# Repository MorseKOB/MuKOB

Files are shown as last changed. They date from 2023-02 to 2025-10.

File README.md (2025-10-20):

# MuKOB (μKOB) - Micro-controller based MorseKOB Client Device

Raspberry Pi Pico W (RP2040 CPU) based device with a built-in display and
a terminal interface. Uses built-in wifi to connect to the MorseKOB Server.

It interfaces to a KOB, Key + Sounder, Key + Tone, Paddle + Tone, etc. to provide Morse
input and output. The device can operate completely stand-alone (using the
display-touchscreen) or it can connect to a VT-220 terminal (or emulator like Putty)
to provide a larger interface and allow keyboard input.

It supports both American (railroad) and International code with sounder or tone
output, and allows use of Farnsworth word/character timing to promote improving
copying speed.

This repo also includes the **MuKOB Interface** which can be used with **MKOB** and **MorseKOB** through a USB to a PC.

# References
* [MorseKOB Main Project](https://github.com/MorseKOB)
* [PyKOB - The full/computer MKOB Client Application, utilities and Python libraries](https://github.com/MorseKOB/PyKOB)
* [Raspberry Pi Pico W](https://www.raspberrypi.com/documentation/microcontrollers/raspberry-pi-pico.html)
* [FatFs - Generic FAT Filesystem Module](http://elm-chan.org/fsw/ff/00index_e.html)
* [no-OS-FatFS-SD-SPI-RPi-Pico](https://github.com/carlk3/no-OS-FatFS-SD-SPI-RPi-Pico)

# Acknowledgements
The first, and probably most significant acknowledgement has to go to the architects, developers, technical writers, and other staff members responsible for the **Raspberry Pi Pico** and **Pico W**, the **Raspberry Pi Pico C/C++ SDK**, and the **Raspberry Pi Pico C/C++ Samples**.

This application implements a 'C' version of the American Morse encoding and decoding algorithms developed by *Les Kerr*.

The FAT file system and SD card libraries, with some small modifications (to configure for the MuKOB board and remove some printing), are from *ChaN* and *Carl Kugler* respectively.

As with every significant C project I've undertaken since the early '80s, my 'go-to' reference is **The C Programming Language** by *Brian Kernighan* and *Dennis Ritchie* (Prentice Hall, 1978 & 1988).

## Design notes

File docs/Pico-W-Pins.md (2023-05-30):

# Pico-W Pins used for the μKOB device

The μKOB device uses most of the Pico-W's GPIO/PIO pins. Because both hardware
SPI's are used, as well as two pins for PIO (for the rotary encoder), the pins
assigned can't be changed too much. The definitions for the pins used are in
the 'system_defs.h' file.

As defined, the pin assignments are
 (Pins within single-quotes are fixed use. NU=Not Used):
| | Use | PIN  |  |  PIN | Use |
|-|---|---|--|---|---|
| | TTY-TX | 1  |  |  40  | 'VBUS' |
| | TTY-RX | 2  |  |  39  | 'VSYS' |
| | 'GND' | 3  |  |  38  | 'GND' |
| | SD+Touch SPI0-SCK | 4  |  |  37  | '3V3_EN' |
| |  SD+Touch SPI0-TX | 5  |  |  36  | '3V3 OUT' |
| |  SD+Touch SPI0-RX | 6  |  |  35  | 'ADC_VREF' |
| | SD Select | 7  |  |  34  | GP-28 (NU) |
| | 'GND' | 8  |  |  33  | 'GND/AGND' |
| | Touch Select | 9  |  |  32  | Display Backlight |
| | Touch IRQ |  10  |  |  31  | Display Reset |
| | Display CMD-/Data |  11  |  |  30  | 'RUN' |
| | Display Select |  12  |  |  29  | Speaker |
| | 'GND' |  13  |  |  28  | 'GND' |
| |  Display SPI1-SCK |  14  |  |  27  | Options SW - 4 |
| | Display SPI1-TX |  15  |  |  26  | Options SW - 3 |
| | Display SPI1-RX |  16  |  |  25  | Options SW - 2 |
| | Rotary Push-SW |  17  |  |  24  | Options SW - 1 |
| | 'GND' |  18  |  |  23  | 'GND' |
| | Rotary Phase-A |  19  |  |  22  | Morse Key |
| | Rotary Phase-B |  20  |  |  21  | Morse Sounder |
|_|___________________|______|__|______|___________________|
Notes:
 SPI0 and SPI1 use the hardware SPI's. Therefore, they have limited pins.
 The Rotary A:B use PIO. They must be 2 sequential GP pins for 'A' then 'B'.
 The 'Options SW' is to select 'hard' options used before the SD is
  initialized. They were selected as 4 GPIO's in a row to make it easy to
  breadboard (also picked these since I2C is not being used).

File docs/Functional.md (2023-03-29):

# Cooperative Multitasking
μKOB uses *cooperative multitasking* on each of the RP2040 cores.

@see https://en.wikipedia.org/wiki/Cooperative_multitasking for more information on this style.

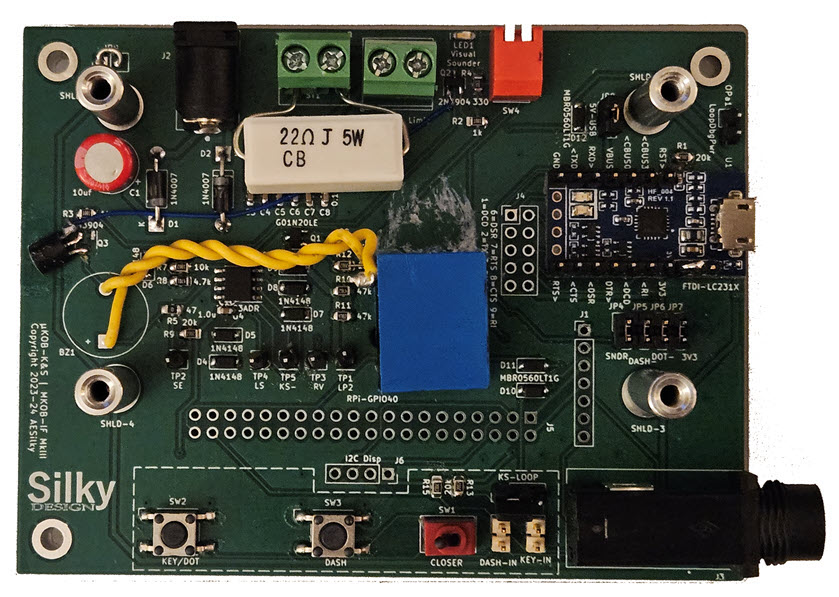
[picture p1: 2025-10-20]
docs/images/KSIF-MkIII-top-na.jpg

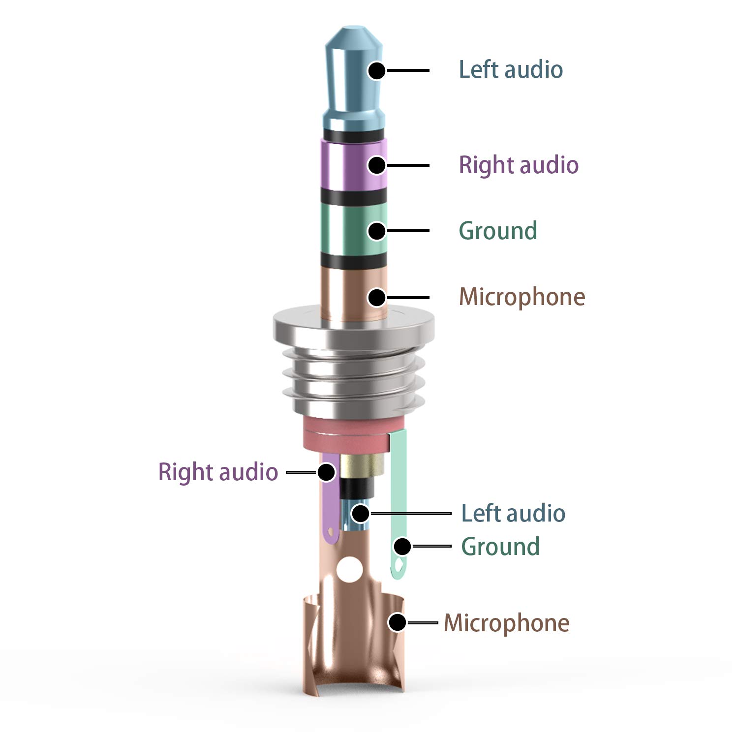
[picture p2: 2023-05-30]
docs/TRRS-Conn-Pins.jpg

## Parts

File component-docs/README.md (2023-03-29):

# COMPONENT DOCUMENTATION
This folder contains documents for the components used in the μKOB system.

These are copies from the manufacturers of the components and are the 
property/copyright of those manufacturers.

They are included here for convenience.

Some of the components may or may not be used in the current version, 
but were, or were expected to be, used in some version.

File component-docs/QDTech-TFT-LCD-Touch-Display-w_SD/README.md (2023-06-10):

# TFT-LCD Display Modules w/Touch and SD Card

There are a number of commonly found, different sized, SPI display modules
with a red PCB, ILITECH display controller, ADS7843/XPT2046 touch screen
controller, and a full-sized SD card slot, sold under different brand names
(HiLetgo, Adafruit, Hosyond, etc.). Regardless of the distributor selling it,
they are all designed and manufactured by:
Shenzhen Junxian Electronic Technology Co., Ltd
[QDTech China](https://szjunxian.en.alibaba.com/)

The specific ILITECH display controller the module uses depends on the
resolution and screen size of the TFT-LCD panel.

Resolution - Size = Controller:

* 240x320 - 2.8" = ILI9341
* 240x320 - 3.2" = ILI9341
* 320x480 - 3.5" = ILI9844
* 320x480 - 4.0" = ILI9486

Touch Screen Controller: TI (Burr-Brown) ADS7843 / SHENZHEN XPTEK XPT2046

SD Card: Full size card socket using 4-wire SPI interface mode.

Module Power (internal): 3.3V. From connector `VCC` or TOREX XC6206 Precicion Voltage Regulator with `VCC` as the source.

## SPI Interface

The SPI connections are seperate for the three functional areas with a common
power connection. The power, display, and touch connections are via one 14
pin connector (1x14 pin). The SD card connection is through a separate
(1x4 pin) connector.

The modules are available without the touch screen (generally, with a 1 digit
difference in model number).

## Power

There is a jumper (SMD resistor location), `J1` on the PCB that is shipped open
(not populated). Shorting it (populating with a 0 ohm resistor) bypasses the
TOREX XC6206 3.3v regulator that is sourced from the `VCC` pin on the 14 pin
connector.

`J1` **MUST** be open if the module is powered from 5v. It can be closed (wired or 0 ohm resistor/shunt populated) if powering the module from 3.3v to avoid the small (~250mV)
drop introduced by the regulator.

Note that **all logic signals are 3.3v**.

## Touch Screen Controller

The `Vref` of the ADS7843/XPT2046 touch screen controller is tied to (the internal)
`VCC3.3`. The `VCC3.3` is either the output from the on-module 3.3v regulator or the
`VCC` input of the module, depending on the state of `J1` (See: [Power](#markdown-header-power)).

If `J1` is left open, the locally generated `VCC3.3` is likely to be more stable than the
voltage of `VCC` provided by the connector. However, the (possibly) lower value of
Vref must be accounted for when reading ADC values.

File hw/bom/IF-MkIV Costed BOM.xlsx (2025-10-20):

Item | References | Value | Footprint | Quantity Total | Cost Each | Base | Base Cost | Key Jack 1/4 | K14 Cost | Sndr/Loop Power | SLPS Cost | LED+Mini Sounder | L/MS Cost
1 | C2, C3, C4, C5, C6, C7, C8, C11 | 0.1u | C_0603_1608Metric_Pad1.08x0.95mm_HandSolder | 8 | $0.02 | 8 | $0.16 |  | $0.00 |  | $0.00 |  | $0.00
2 | C9, C10 | 1.0u | C_0603_1608Metric_Pad1.08x0.95mm_HandSolder | 2 | $0.02 | 2 | $0.04 |  | $0.00 |  | $0.00 |  | $0.00
3 | C1 | 10uf | CP_Radial_D8.0mm_P5.00mm | 1 | $1.40 | 1 | $1.40 |  | $0.00 |  | $0.00 |  | $0.00
4 | C12 | 10uf Tant | CP_EIA-3528-12_Kemet-T_Pad1.50x2.35mm_HandSolder | 1 | $0.13 | 0 | $0.00 |  | $0.00 | 0 | $0.00 | 1 | $0.13
5 | R1, R9, R12, R13, R15 | 20k | R_0805_2012Metric_Pad1.20x1.40mm_HandSolder | 5 | $0.02 | 5 | $0.10 |  | $0.00 |  | $0.00 |  | $0.00
6 | R6, R7 | 10k | R_0805_2012Metric_Pad1.20x1.40mm_HandSolder | 2 | $0.02 | 2 | $0.04 |  | $0.00 |  | $0.00 |  | $0.00
7 | R8, R14 | 4.7k | R_0805_2012Metric_Pad1.20x1.40mm_HandSolder | 2 | $0.02 | 2 | $0.04 |  | $0.00 |  | $0.00 |  | $0.00
8 | R10, R11 | 47k | R_0805_2012Metric_Pad1.20x1.40mm_HandSolder | 2 | $0.02 | 2 | $0.04 |  | $0.00 |  | $0.00 |  | $0.00
9 | R2 | 1k | R_0805_2012Metric_Pad1.20x1.40mm_HandSolder | 1 | $0.02 | 0 | $0.00 |  | $0.00 | 0 | $0.00 | 1 | $0.02
10 | R4 | 330 | R_0805_2012Metric_Pad1.20x1.40mm_HandSolder | 1 | $0.02 | 0 | $0.00 |  | $0.00 | 0 | $0.00 | 1 | $0.02
11 | R5 | 0|16 | R_0805_2012Metric_Pad1.20x1.40mm_HandSolder | 1 | $0.02 | 0 | $0.00 |  | $0.00 | 0 | $0.00 | 1 | $0.02
12 | D4, D5, D6, D7, D8 | 1N4148 | D_SOD-123 | 5 | $0.05 | 5 | $0.25 |  | $0.00 |  | $0.00 |  | $0.00
13 | D2, D10, D11, D12 | MBR0560LT1G | D_SOD-123 | 4 | $0.12 | 3 | $0.36 |  | $0.00 |  | $0.00 | 1 | $0.12
14 | D1 | HDS20M | TO-269AA | 1 | $0.30 | 0 | $0.00 |  | $0.00 | 1 | $0.30 |  | $0.00
15 | D3 | 1N4007 | D_SOD-123 | 1 | $0.08 | 1 | $0.08 |  | $0.00 |  | $0.00 |  | $0.00
16 | D9 | MBR180S1 (Sndr Drv) | D_SOD-123 | 1 | $0.12 | 1 | $0.12 |  | $0.00 |  | $0.00 |  | $0.00
17 | U1 | FTDI-LC231X | AES-FTDI_LC231X | 1 | $9.75 | 1 | $9.75 |  | $0.00 |  | $0.00 |  | $0.00
18 | U4 | LM393ADR | SOIC-8_3.9x4.9mm_P1.27mm | 1 | $0.40 | 1 | $0.40 |  | $0.00 |  | $0.00 |  | $0.00
19 | SW1 | CLOSER | AES-SW-TGL-Micro-DPST-CIT | 1 | $2.60 | 0 | $0.00 |  | $0.00 |  | $0.00 |  | $0.00
20 | SW2 | KEY/DOT | AES-SW_PUSH_SMD_1P1T_NO_6x6mm | 1 | $0.55 | 0 | $0.00 |  | $0.00 |  | $0.00 |  | $0.00
21 | SW3 | DASH | AES-SW_PUSH_SMD_1P1T_NO_6x6mm | 1 | $0.55 | 0 | $0.00 |  | $0.00 |  | $0.00 |  | $0.00
22 | SW4 | SW_DIP_x02 | DIP-4_W7.62mm_Socket | 1 | $1.50 | 0 | $0.00 |  | $0.00 |  | $0.00 | 1 | $1.50
23 | JP8, JP10 | 5V-USB | PinHeader_1x02_P2.54mm_Vertical | 2 | $0.01 | 2 | $0.02 |  | $0.00 |  | $0.00 |  | $0.00
24 | JP1 | KeyJack-NP | PinHeader_1x02_P2.54mm_Vertical | 1 | $0.01 | 1 | $0.01 |  | $0.00 |  | $0.00 |  | $0.00
25 | JP2 | KEY-IN | PinHeader_1x02_P2.54mm_Vertical | 1 | $0.01 | 1 | $0.01 |  | $0.00 |  | $0.00 |  | $0.00
26 | JP3 | DASH-IN | PinHeader_1x02_P2.54mm_Vertical | 1 | $0.01 | 1 | $0.01 |  | $0.00 |  | $0.00 |  | $0.00
27 | JP4 | SNDR | PinHeader_1x02_P2.54mm_Vertical | 1 | $0.01 | 1 | $0.01 |  | $0.00 |  | $0.00 |  | $0.00
28 | JP5 | DASH- | PinHeader_1x02_P2.54mm_Vertical | 1 | $0.01 | 1 | $0.01 |  | $0.00 |  | $0.00 |  | $0.00
29 | JP6 | DOT- | PinHeader_1x02_P2.54mm_Vertical | 1 | $0.01 | 1 | $0.01 |  | $0.00 |  | $0.00 |  | $0.00
30 | JP7 | 3V3 | PinHeader_1x02_P2.54mm_Vertical | 1 | $0.01 | 1 | $0.01 |  | $0.00 |  | $0.00 |  | $0.00
31 | JP9 | Shield_GND | PinHeader_1x02_P2.54mm_Vertical | 1 | $0.01 | 1 | $0.01 |  | $0.00 |  | $0.00 |  | $0.00
32 | LED1 | VIS_SNDR | AES-LED_SMD_SIDEVIEW_Harvatek | 1 | $0.10 | 0 | $0.00 |  | $0.00 |  | $0.00 | 1 | $0.10
33 | OP1 | KS-LOOP | PinHeader_1x03_P2.54mm_Vertical | 1 | $0.02 | 0 | $0.00 |  | $0.00 |  | $0.00 | 1 | $0.02
34 | OPa1 | LoopDbgPwr | PinHeader_1x02_P2.54mm_Vertical | 1 | $0.01 | 1 | $0.01 |  | $0.00 |  | $0.00 |  | $0.00
35 | Q1 | G01N20LE (Sndr Drv) | SOT-23 | 1 | $0.35 | 1 | $0.35 |  | $0.00 |  | $0.00 |  | $0.00
36 | Q2 | MMBT3904 | SOT-23 | 1 | $0.04 | 0 | $0.00 |  | $0.00 |  | $0.00 | 1 | $0.04
37 | RLY1 | RELAY-5v|3v-DPST | Relay_SPDT_Finder_36.11 | 1 | $2.00 | 0 | $0.00 |  | $0.00 |  | $0.00 | 1 | $2.00
38 | ST1 | LOOP_CUR_LIMIT | TerminalBlock_Philmore_TB132_1x02_P5.00mm_Horizontal | 1 | $0.35 | 1 | $0.35 |  | $0.00 |  | $0.00 |  | $0.00
39 | ST2 | SNDR/KOB | TerminalBlock_Philmore_TB132_1x02_P5.00mm_Horizontal | 1 | $0.35 | 1 | $0.35 |  | $0.00 |  | $0.00 |  | $0.00
40 | TP1 | LP2 | PinHeader_1x01_P2.54mm_Vertical | 1 | $0.00 | 0 | $0.00 |  | $0.00 |  | $0.00 |  | $0.00
41 | TP2 | SE | PinHeader_1x01_P2.54mm_Vertical | 1 | $0.00 | 0 | $0.00 |  | $0.00 |  | $0.00 |  | $0.00
42 | TP3 | RV | PinHeader_1x01_P2.54mm_Vertical | 1 | $0.00 | 0 | $0.00 |  | $0.00 |  | $0.00 |  | $0.00
43 | TP4 | LS | PinHeader_1x01_P2.54mm_Vertical | 1 | $0.00 | 0 | $0.00 |  | $0.00 |  | $0.00 |  | $0.00
44 | TP5 | KS- | PinHeader_1x01_P2.54mm_Vertical | 1 | $0.00 | 0 | $0.00 |  | $0.00 |  | $0.00 |  | $0.00
45 | TP6 | SE- | PinHeader_1x01_P2.54mm_Vertical | 1 | $0.00 | 0 | $0.00 |  | $0.00 |  | $0.00 |  | $0.00
46 | J1 | MuKOB IF | PinHeader_1x07_P2.54mm_Vertical | 1 | $0.05 | 0 | $0.00 |  | $0.00 |  | $0.00 |  | $0.00
47 | J2 | LOOP PWR | AES-CUI_PJ-037B | 1 | $0.70 | 0 | $0.00 |  | $0.00 | 1 | $0.70 |  | $0.00
48 | J3 | KEY-PADDLE | AES-CUI_SJ-63063B-audio-jack | 1 | $1.80 | 0 | $0.00 | 1 | $1.80 |  | $0.00 |  | $0.00
49 | J4 | COMM-DCE-10 | PinHeader_2x05_DB9-Order | 1 | $0.10 | 0 | $0.00 |  | $0.00 |  | $0.00 |  | $0.00
50 | J5 | RPi-GPIO40 | PinSocket_2x20_P2.54mm_Vertical | 1 | $0.80 | 0 | $0.00 |  | $0.00 |  | $0.00 |  | $0.00
51 | J6 | I2C Disp | PinSocket_1x04_P2.54mm_Vertical | 1 | $0.05 | 0 | $0.00 |  | $0.00 |  | $0.00 |  | $0.00
52 | J7 | KEY-PADDLE-1_8 | CUI_SJ1-3534NG-audio-jack | 1 | $1.50 | 0 | $0.00 |  | $0.00 |  | $0.00 |  | $0.00
53 | PCB | MuKOB IF MkIV | PCBWay | 1 | $6.50 | 1 | $6.50 |  | $0.00 |  | $0.00 |  | $0.00
54 | Base | Acrylic | Send-Cut-Send Laser Cut | 1 | $2.00 | 1 | $2.00 |  | $0.00 |  | $0.00 |  | $0.00
55 | Shield | Altoids Tin | (Modifications) | 1 | $2.00 | 1 | $2.00 |  | $0.00 |  | $0.00 |  | $0.00
56 | Screws & Spacers |  | 8 Screws, 4 Alum Spacers, 4 Nylon Spacers (kit) | 1 | $3.00 | 1 | $3.00 |  | $0.00 |  | $0.00 |  | $0.00
 |  |  | Totals | 79 |  | 52 | $27.44 | 1 | $1.80 | 2 | $1.00 | 10 | $3.97
 |  | 'Full' >>> | Base + 1/4" Key Jack + Sndr Pwr + L/MS + Test Key |  | $37.71 |  | $27.24 |  | $1.80 |  | $1.00 |  | $3.97
 |  | 'KOB' >>> | Base + Sndr Pwr |  | $28.24 |  | $27.24 |  |  |  | $1.00

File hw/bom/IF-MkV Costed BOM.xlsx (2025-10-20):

Item | References | Value | Footprint | Quantity Total | Cost Each | Base | Base Cost | Key Jack 1/8 | K18 Cost | Sndr/Loop Power | SLPS Cost | LED (Vis) Sounder | L(VS) Cost | RPi Conn | RPC Cost | Debug Only | (qty check)
1 | C3, C6, C7, C8, C9, C11, C12, C13, C14 | 0.1u | C_0603_1608Metric_Pad1.08x0.95mm_HandSolder | 9 | $0.02 | 8 | $0.16 |  | $0.00 | 1 | $0.02 |  | $0.00 | -1 | -$0.02 |  | 9
2 | C5, C10 | 1.0u | C_0603_1608Metric_Pad1.08x0.95mm_HandSolder | 2 | $0.02 | 2 | $0.04 |  | $0.00 |  | $0.00 |  | $0.00 |  | $0.00 |  | 2
3 | C1 | 10u | C_0603_1608Metric_Pad1.08x0.95mm_HandSolder | 1 | $0.02 | 1 | $0.02 |  | $0.00 |  | $0.00 |  | $0.00 | -1 | -$0.02 |  | 1
4 | C2 | 47u | C_0603_1608Metric_Pad1.08x0.95mm_HandSolder | 1 | $0.05 | 1 | $0.05 |  | $0.00 |  | $0.00 |  | $0.00 | -1 | -$0.05 |  | 1
5 | C4 | 10uf | CP_Radial_D8.0mm_P5.00mm | 1 | $1.50 | 0 | $0.00 |  | $0.00 | 1 | $1.50 |  | $0.00 |  | $0.00 |  | 1
6 | R7, R8, R12, R13 | 20k | R_0805_2012Metric_Pad1.20x1.40mm_HandSolder | 4 | $0.03 | 4 | $0.12 |  | $0.00 |  | $0.00 |  | $0.00 |  | $0.00 |  | 4
7 | R3, R4 | 470 | R_0805_2012Metric_Pad1.20x1.40mm_HandSolder | 1 | $0.03 | 0 | $0.00 |  | $0.00 |  | $0.00 | 1 | $0.03 |  | $0.00 |  | 1
8 | R5, R6 | 27 | R_0805_2012Metric_Pad1.20x1.40mm_HandSolder | 2 | $0.03 | 2 | $0.06 |  | $0.00 |  | $0.00 |  | $0.00 | -2 | -$0.06 |  | 2
9 | R9, R10 | 10k | R_0805_2012Metric_Pad1.20x1.40mm_HandSolder | 2 | $0.03 | 2 | $0.06 |  | $0.00 |  | $0.00 |  | $0.00 |  | $0.00 |  | 2
10 | R11, R16 | 4.7k | R_0805_2012Metric_Pad1.20x1.40mm_HandSolder | 2 | $0.03 | 2 | $0.06 |  | $0.00 |  | $0.00 |  | $0.00 |  | $0.00 |  | 2
11 | R14, R15 | 47k | R_0805_2012Metric_Pad1.20x1.40mm_HandSolder | 2 | $0.03 | 2 | $0.06 |  | $0.00 |  | $0.00 |  | $0.00 |  | $0.00 |  | 2
12 | R1 | 1k | R_0805_2012Metric_Pad1.20x1.40mm_HandSolder | 1 | $0.03 | 0 | $0.00 |  | $0.00 |  | $0.00 | 1 | $0.03 |  | $0.00 |  | 1
13 | R2 | 0-S | R_0805_2012Metric_Pad1.20x1.40mm_HandSolder | 1 | $0.03 | 1 | $0.03 |  | $0.00 |  | $0.00 |  | $0.00 | -1 | -$0.03 |  | 1
14 | L1 | 600RJ0.5A | L_0805_2012Metric_Pad1.15x1.40mm_HandSolder | 1 | $0.15 | 1 | $0.15 |  | $0.00 |  | $0.00 |  | $0.00 |  | $0.00 |  | 1
15 | D4, D5, D6, D7, D8 | 1N4148 | D_SOD-123 | 5 | $0.05 | 5 | $0.25 |  | $0.00 |  | $0.00 |  | $0.00 |  | $0.00 |  | 5
16 | D1, D2, D3 | MBR0560LT1G | D_SOD-123 | 3 | $0.15 | 3 | $0.45 |  | $0.00 |  | $0.00 |  | $0.00 |  | $0.00 |  | 3
17 | D9 | MBR180S1 | D_SOD-123 | 1 | $0.15 | 1 | $0.15 |  | $0.00 |  | $0.00 |  | $0.00 |  | $0.00 |  | 1
18 | D10 | 1N4007 | D_SOD-123 | 1 | $0.08 | 1 | $0.08 |  | $0.00 |  | $0.00 |  | $0.00 |  | $0.00 |  | 1
19 | U1 | LM393ADR | SOIC-8_3.9x4.9mm_P1.27mm | 1 | $0.50 | 1 | $0.50 |  | $0.00 |  | $0.00 |  | $0.00 |  | $0.00 |  | 1
20 | U2 | FT231XQ | QFN-20-1EP_4x4mm_P0.5mm_EP2.5x2.5mm | 1 | $3.50 | 1 | $3.50 |  | $0.00 |  | $0.00 |  | $0.00 | -1 | -$3.50 |  | 1
21 | BR1 | HDS20M | AES-BridgeRect-HDS20M-13-1KV-2A | 1 | $0.30 | 0 | $0.00 |  | $0.00 | 1 | $0.30 |  | $0.00 |  | $0.00 |  | 1
22 | JP4 | KeyJack-NP | PinHeader_1x02_P2.54mm_Vertical | 1 | $0.01 | 1 | $0.01 |  | $0.00 |  | $0.00 |  | $0.00 |  | $0.00 |  | 1
23 | JP5 | SNBR EN | PinHeader_1x02_P2.54mm_Vertical | 1 | $0.01 | 1 | $0.01 |  | $0.00 |  | $0.00 |  | $0.00 |  | $0.00 |  | 1
24 | JP6 | Shield-GND | PinHeader_1x02_P2.54mm_Vertical | 1 | $0.01 | 1 | $0.01 |  | $0.00 |  | $0.00 |  | $0.00 |  | $0.00 |  | 1
25 | LED1 | VIS_SNDR | AES-LED_SMD_SIDEVIEW_Harvatek | 1 | $0.10 | 0 | $0.00 |  | $0.00 |  | $0.00 | 1 | $0.10 |  | $0.00 |  | 1
26 | LED2 | RX | AES-LED_SMD_SIDEVIEW_Harvatek | 0 | $0.10 | 0 | $0.00 |  | $0.00 |  | $0.00 |  | $0.00 |  | $0.00 |  | 0
27 | OP1 | LPWR-EPWR | PinHeader_1x03_P2.54mm_Vertical | 1 | $0.03 | 0 | $0.00 |  | $0.00 | 1 | $0.03 |  | $0.00 |  | $0.00 |  | 1
28 | Q1 | MMBT3904 | SOT-23 | 1 | $0.04 | 0 | $0.00 |  | $0.00 |  | $0.00 | 1 | $0.04 |  | $0.00 |  | 1
29 | Q2 | G01N20LE | SOT-23 | 1 | $0.35 | 1 | $0.35 |  | $0.00 |  | $0.00 |  | $0.00 |  | $0.00 |  | 1
30 | ST1 | SNDR/KOB | AES-TermBlock-2POS-5mm-Horz | 1 | $0.35 | 1 | $0.35 |  | $0.00 |  | $0.00 |  | $0.00 |  | $0.00 |  | 1
31 | ST2 | LOOP CUR LIMIT | AES-TermBlock-2POS-5mm-Horz | 1 | $0.35 | 1 | $0.35 |  | $0.00 |  | $0.00 |  | $0.00 |  | $0.00 |  | 1
32 | J2 | LOOP PWR | AES-CUI_PJ-037B | 1 | $0.70 | 0 | $0.00 |  | $0.00 | 1 | $0.70 |  | $0.00 |  | $0.00 |  | 1
33 | J3 | KEY-PADDLE-1_8 | AES-CUI_SJ1-3534NG-audio-jack | 1 | $1.50 | 0 | $0.00 | 1 | $1.50 |  | $0.00 |  | $0.00 |  | $0.00 |  | 1
34 | J4 | USB-Conn | AES-USB_C_Amphenol_GSB1C4621DSHR | 1 | $0.50 | 1 | $0.50 |  | $0.00 |  | $0.00 |  | $0.00 | -1 | -$0.50 |  | 1
35 | J5 | RPi-GPIO40 | 2x20 Socket Header | 1 | $3.50 | 0 | $0.00 |  | $0.00 |  | $0.00 |  | $0.00 | 1 | $3.50 |  | 0
36 | PCB | MuKOB IF MkV | PCBWay | 1 | $7.50 | 1 | $7.50 |  | $0.00 |  | $0.00 |  | $0.00 |  | $0.00 |  | 1
37 | Board Insulator | vinyl | Cricut | 2 | $1.00 | 2 | $2.00 |  | $0.00 |  | $0.00 |  | $0.00 | -1 | -$1.00 |  | 2
38 | Shield | Altoids Tin | (Modifications) | 1 | $4.00 | 1 | $4.00 |  | $0.00 |  | $0.00 |  | $0.00 |  | $0.00 |  | 1
39 | Connector Faceplate | MkV Face | Spring-Steel SendCutSend | 1 | $1.00 | 1 | $1.00 |  | $0.00 |  | $0.00 |  | $0.00 | -1 | -$1.00 |  | 1
40 | Mounting Hardware |  | #6 SS Screws, washers, nuts (set) | 1 | $2.00 | 1 | $2.00 |  | $0.00 |  | $0.00 |  | $0.00 | -1 | -$2.00 |  | 1
 |  |  |  |  |  |  | $0.00 |  | $0.00 |  | $0.00 |  | $0.00 |  | $0.00 |  | 0
 |  |  | Totals | 62 |  | 51 | $23.82 | 1 | $1.50 | 5 | $2.55 | 4 | $0.20 | -10 | -$4.68 | 0 | 1
 |  | 'Full' (Non-RPi) >>> | Base + 1/8" Key Jack + Sndr Pwr + LED(VisSndr) |  | $28.07
 |  | 'LoopPwr' (Non-RPi) >>> | Base + Sndr Pwr |  | $26.37
 |  | 'Minimum' (Non-RPi) >>> | Base Only (No: Key Jack, Power, LED) |  | $23.82

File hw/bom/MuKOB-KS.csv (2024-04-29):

null | Sourced | Placed | References | Value | Footprint | Quantity
1 |  |  | C4, C5, C6, C7, C8, C9 | 0.1u | C_0603_1608Metric_Pad1.08x0.95mm_HandSolder | 6
2 |  |  | C1, C2 | 1uF | C_0201_0603Metric_Pad0.64x0.40mm_HandSolder | 2
3 |  |  | C3 | 10uf | CP_Radial_D8.0mm_P5.00mm | 1
4 |  |  | R5, R6, R8 | 20k | R_0402_1005Metric_Pad0.72x0.64mm_HandSolder | 3
5 |  |  | R2, R10 | 1k | R_0402_1005Metric_Pad0.72x0.64mm_HandSolder | 2
6 |  |  | R1 | 3.3k | R_0402_1005Metric_Pad0.72x0.64mm_HandSolder | 1
7 |  |  | R3 | 10k | R_0402_1005Metric_Pad0.72x0.64mm_HandSolder | 1
8 |  |  | R4 | 270 | R_0402_1005Metric_Pad0.72x0.64mm_HandSolder | 1
9 |  |  | R7 | 100 | R_0402_1005Metric_Pad0.72x0.64mm_HandSolder | 1
10 |  |  | R9 | DNP | R_0402_1005Metric_Pad0.72x0.64mm_HandSolder | 1
11 |  |  | D1, D7, D8 | MBR0560LT1G | D_SOD-123 | 3
12 |  |  | D3, D5, D6 | 1N4148 | D_SOD-123 | 3
13 |  |  | D2, D4 | 1N4148 | D_DO-35_SOD27_P7.62mm_Horizontal | 2
14 |  |  | U1 | MCP1702T-3302E | SOT-23 | 1
15 |  |  | U3 | LM358 | SOIC-8_3.9x4.9mm_P1.27mm | 1
16 |  |  | U4 | LM393ADR | SOIC-8_3.9x4.9mm_P1.27mm | 1
17 |  |  | SW1 | CLOSER | SW-TGL-Micro-DPST-CIT | 1
18 |  |  | SW2 | KEY/DOT | SW_PUSH_SMD_1P1T_NO_6x6mm | 1
19 |  |  | SW3 | DASH | SW_PUSH_SMD_1P1T_NO_6x6mm | 1
20 |  |  | M_KSI1, M_KSI2, M_KSI3, M_KSI4 | MountingHole_Pad | MountingHole_3.2mm_M3_ISO7380_Pad_TopBottom | 4
21 |  |  | SHLD-1, SHLD-2, SHLD-3, SHLD-4 | MountingHole_Pad | MountingHole_4.3mm_M4_ISO14580_Pad_TopBottom | 4
22 |  |  | JP1, JP3 | 1x2 Header | PinHeader_1x02_P2.54mm_Vertical | 2
23 |  |  | Q2, Q4 | 2N3904 | TO-92_Inline | 2
24 |  |  | JP2 | KEY-IN | PinHeader_1x02_P2.54mm_Vertical | 1
25 |  |  | LED1 | SNDR | LED_SMD_SIDEVIEW_Harvatek | 1
26 |  |  | OPa1 | 5V-SRC | PinHeader_1x03_P2.54mm_Vertical | 1
27 |  |  | OPa2 | LoopDbgPwr | PinHeader_1x02_P2.54mm_Vertical | 1
28 |  |  | Q1 | 2N3905 | TO-92_Inline | 1
29 |  |  | Q3 | G01N20LE | SOT-23 | 1
30 |  |  | ST1 | SNDR/KOB | TerminalBlock_Philmore_TB132_1x02_P5.00mm_Horizontal | 1
31 |  |  | ST2 | LOOP RES | TerminalBlock_Philmore_TB132_1x02_P5.00mm_Horizontal | 1
32 |  |  | TP1 | LP2 | PinHeader_1x01_P2.54mm_Vertical | 1
33 |  |  | TP2 | SE | PinHeader_1x01_P2.54mm_Vertical | 1
34 |  |  | TP3 | RV | PinHeader_1x01_P2.54mm_Vertical | 1
35 |  |  | TP4 | LS | PinHeader_1x01_P2.54mm_Vertical | 1
36 |  |  | TP5 | KS- | PinHeader_1x01_P2.54mm_Vertical | 1
37 |  |  | J1 | USB-PWR | USB_Micro-B_Amphenol_10103594-0001LF_Horizontal_modified | 1
38 |  |  | J2 | LOOP PWR | CUI_PJ-037B | 1
39 |  |  | J3 | MKOB-Serial | DSUB-9_Female_Horizontal_P2.77x2.84mm_EdgePinOffset9.90mm_Housed_MountingHolesOffset11.32mm | 1
40 |  |  | J5 | KEY/PDL | CUI_SJ1-3534NG-audio-jack | 1

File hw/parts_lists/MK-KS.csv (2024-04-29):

Source: | C:\Users\aesil\proj\mukob-hw\MuKOB\hw\MK-KS.kicad_sch
Date: | 1/16/2024 10:56:56 AM
Tool: | Eeschema 7.0.2
Generator: | C:\Program Files\KiCad\7.0\bin\scripting\plugins/bom_csv_grouped_by_value.py
Component Count: | 63
Collated Components:
Item | Qty | Reference(s) | Value | LibPart | Footprint | Datasheet | DNP | CUI_PURCHASE_URL | Category | DESCRIPTION | DK_Datasheet_Link | DK_Detail_Page | Description | Digi-Key_PN | Family | MF | MP | MPN | Manufacturer | PACKAGE | PRICE | Sim.Device | Sim.Pins | Status
1 | 2 | C1, C2 | 1uF | Device:C | Capacitor_SMD:C_0201_0603Metric_Pad0.64x0.40mm_HandSolder | ~
2 | 1 | C3 | 10uf | Device:C_Polarized_US | Capacitor_THT:CP_Radial_D8.0mm_P5.00mm | ~
3 | 6 | C4, C5, C6, C7, C8, C9 | 0.1u | Device:C | Capacitor_SMD:C_0603_1608Metric_Pad1.08x0.95mm_HandSolder | ~
4 | 3 | D1, D7, D8 | MBR0560LT1G | Diode:MBR0560 | Diode_SMD:D_SOD-123 | http://www.mccsemi.com/up_pdf/MBR0520~MBR0580(SOD123).pdf
5 | 2 | D2, D4 | 1N4148 | Diode:1N4004 | Diode_THT:D_DO-35_SOD27_P7.62mm_Horizontal | http://www.vishay.com/docs/88503/1n4001.pdf |  |  |  |  |  |  |  |  |  |  |  |  |  |  |  | D | 1=K 2=A
6 | 2 | D3, D5 | 1N4148 | Diode:1N4004 | Diode_SMD:D_SOD-123 | http://www.vishay.com/docs/88503/1n4001.pdf |  |  |  |  |  |  |  |  |  |  |  |  |  |  |  | D | 1=K 2=A
7 | 1 | D6 | 1N4148 | Diode:1N4148W | Diode_SMD:D_SOD-123 | https://www.vishay.com/docs/85748/1n4148w.pdf |  |  |  |  |  |  |  |  |  |  |  |  |  |  |  | D | 1=K 2=A
8 | 1 | J1 | USB-PWR | Connector:USB_OTG | AES_Library:USB_Micro-B_Amphenol_10103594-0001LF_Horizontal_modified | ~
9 | 1 | J2 | LOOP PWR | Connector:Conn_Coaxial_Power | AES_Library:CUI_PJ-037B | ~
10 | 1 | J3 | MKOB-Serial | Connector:DE9_Receptacle_MountingHoles | Connector_Dsub:DSUB-9_Female_Horizontal_P2.77x2.84mm_EdgePinOffset9.90mm_Housed_MountingHolesOffset11.32mm | ~
11 | 1 | J4 | MuKOB IF | Connector_Generic:Conn_01x07 | Connector_PinHeader_2.54mm:PinHeader_1x07_P2.54mm_Vertical | ~
12 | 1 | J5 | KEY/PDL | AES_Library:CUI_SJ1-3534NG-audio-jack | AES_Library:CUI_SJ1-3534NG-audio-jack |  |  | https://www.cuidevices.com/product/interconnect/connectors/audio-connectors/jacks/sj1-353xng-series |  | 3.5 mm, Stereo, Right Angle, Through Hole, Isolated Ground, Audio Jack Connector |  |  |  |  |  | CUI Devices | SJ1-3534NG |  |  | None | None
13 | 2 | JP1, JP3 | 1x2 Header | Jumper:Jumper_2_Open | Connector_PinHeader_2.54mm:PinHeader_1x02_P2.54mm_Vertical | ~
14 | 1 | JP2 | KEY-IN | Jumper:Jumper_2_Open | Connector_PinHeader_2.54mm:PinHeader_1x02_P2.54mm_Vertical | ~
15 | 1 | LED1 | SNDR | Device:LED | AES_Library:LED_SMD_SIDEVIEW_Harvatek | ~
16 | 4 | M_KSI1, M_KSI2, M_KSI3, M_KSI4 | MountingHole_Pad | Mechanical:MountingHole_Pad | MountingHole:MountingHole_3.2mm_M3_ISO7380_Pad_TopBottom | ~
17 | 1 | OPa1 | 5V-SRC | MuKOB:Option_A-B | Connector_PinHeader_2.54mm:PinHeader_1x03_P2.54mm_Vertical
18 | 1 | OPa2 | LoopDbgPwr | Connector_Generic:Conn_01x02 | Connector_PinHeader_2.54mm:PinHeader_1x02_P2.54mm_Vertical | ~
19 | 1 | Q1 | 2N3905 | Transistor_BJT:2N3905 | Package_TO_SOT_THT:TO-92_Inline | https://www.nteinc.com/specs/original/2N3905_06.pdf
20 | 2 | Q2, Q4 | 2N3904 | Transistor_BJT:2N3904 | Package_TO_SOT_THT:TO-92_Inline | https://www.onsemi.com/pub/Collateral/2N3903-D.PDF
21 | 1 | Q3 | G01N20LE | Transistor_FET:2N7002 | Package_TO_SOT_SMD:SOT-23 | https://www.onsemi.com/pub/Collateral/NDS7002A-D.PDF
22 | 1 | R1 | 3.3k | Device:R_US | Resistor_SMD:R_0402_1005Metric_Pad0.72x0.64mm_HandSolder | ~
23 | 1 | R2 | 1k | Device:R_Small_US | Resistor_SMD:R_0402_1005Metric_Pad0.72x0.64mm_HandSolder | ~
24 | 1 | R3 | 10k | Device:R_US | Resistor_SMD:R_0402_1005Metric_Pad0.72x0.64mm_HandSolder | ~
25 | 1 | R4 | 270 | Device:R_Small_US | Resistor_SMD:R_0402_1005Metric_Pad0.72x0.64mm_HandSolder | ~
26 | 3 | R5, R6, R8 | 20k | Device:R_US | Resistor_SMD:R_0402_1005Metric_Pad0.72x0.64mm_HandSolder | ~
27 | 1 | R7 | 100 | Device:R_US | Resistor_SMD:R_0402_1005Metric_Pad0.72x0.64mm_HandSolder | ~
28 | 1 | R9 | DNP | Device:R_US | Resistor_SMD:R_0402_1005Metric_Pad0.72x0.64mm_HandSolder | ~
29 | 1 | R10 | 1k | Device:R_US | Resistor_SMD:R_0402_1005Metric_Pad0.72x0.64mm_HandSolder | ~
30 | 4 | SHLD-1, SHLD-2, SHLD-3, SHLD-4 | MountingHole_Pad | Mechanical:MountingHole_Pad | MountingHole:MountingHole_4.3mm_M4_ISO14580_Pad_TopBottom | ~
31 | 1 | ST1 | SNDR/KOB | Connector:Screw_Terminal_01x02 | TerminalBlock_Philmore:TerminalBlock_Philmore_TB132_1x02_P5.00mm_Horizontal | ~
32 | 1 | ST2 | LOOP RES | Connector:Screw_Terminal_01x02 | TerminalBlock_Philmore:TerminalBlock_Philmore_TB132_1x02_P5.00mm_Horizontal | ~
33 | 1 | SW1 | CLOSER | Switch:SW_SPST | AES_Library:SW-TGL-Micro-DPST-CIT | ~
34 | 1 | SW2 | KEY/DOT | Switch:SW_Push | AES_Library:SW_PUSH_SMD_1P1T_NO_6x6mm | ~
35 | 1 | SW3 | DASH | Switch:SW_Push | AES_Library:SW_PUSH_SMD_1P1T_NO_6x6mm | ~
36 | 1 | TP1 | LP2 | Test_point_Jump:TP_01 | Connector_PinHeader_2.54mm:PinHeader_1x01_P2.54mm_Vertical | ~
37 | 1 | TP2 | SE | Test_point_Jump:TP_01 | Connector_PinHeader_2.54mm:PinHeader_1x01_P2.54mm_Vertical | ~
38 | 1 | TP3 | RV | Test_point_Jump:TP_01 | Connector_PinHeader_2.54mm:PinHeader_1x01_P2.54mm_Vertical | ~
39 | 1 | TP4 | LS | Test_point_Jump:TP_01 | Connector_PinHeader_2.54mm:PinHeader_1x01_P2.54mm_Vertical | ~
40 | 1 | TP5 | KS- | Test_point_Jump:TP_01 | Connector_PinHeader_2.54mm:PinHeader_1x01_P2.54mm_Vertical | ~
41 | 1 | U1 | MCP1702T-3302E | Regulator_Linear:MCP1700x-330xxTT | Package_TO_SOT_SMD:SOT-23 | http://ww1.microchip.com/downloads/en/DeviceDoc/20001826D.pdf
42 | 1 | U3 | LM358 | Amplifier_Operational:LM358 | Package_SO:SOIC-8_3.9x4.9mm_P1.27mm | http://www.ti.com/lit/ds/symlink/lm2904-n.pdf
43 | 1 | U4 | LM393ADR | rpikobhat-rescue:LM393DR-dk_Linear-Comparators | Package_SO:SOIC-8_3.9x4.9mm_P1.27mm | http://www.ti.com/general/docs/suppproductinfo.tsp?distId=10 |  |  | Integrated Circuits (ICs) |  | http://www.ti.com/general/docs/suppproductinfo.tsp?distId=10 | /product-detail/en/texas-instruments/LM393ADR/296-1015-1-ND/404839 | IC DUAL DIFF COMP 8-SOIC | 296-14605-1-ND | Linear - Comparators |  |  | LM393ADR | Texas Instruments |  |  |  |  | Active

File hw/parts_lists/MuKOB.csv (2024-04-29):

Source: | C:\Users\aesil\proj\mukob-hw\MuKOB\hw\MuKOB.kicad_sch
Date: | 1/16/2024 11:01:40 AM
Tool: | Eeschema 7.0.2
Generator: | C:\Program Files\KiCad\7.0\bin\scripting\plugins/bom_csv_grouped_by_value.py
Component Count: | 123
Collated Components:
Item | Qty | Reference(s) | Value | LibPart | Footprint | Datasheet | DNP | MANUFACTURER | MAXIMUM_PACKAGE_HEIGHT | PARTREV | SNAPEDA_PN | STANDARD
1 | 1 | BZ1 | Buzzer | Device:Buzzer | Buzzer_Beeper:Buzzer_12x9.5RM7.6 | ~
2 | 11 | C1, C2, C3, C5, C6, C22, C23, C24, C25, C26, C27 | 0.1uF | Device:C_Small | Capacitor_SMD:C_0603_1608Metric_Pad1.08x0.95mm_HandSolder | ~
3 | 3 | C4, C7, C8 | 10uF | Device:C | Capacitor_SMD:C_0603_1608Metric | ~
4 | 1 | C9 | 0.1uF | Device:C | Capacitor_SMD:C_0603_1608Metric_Pad1.08x0.95mm_HandSolder | ~
5 | 4 | C10, C11, C12, C13 | 1uF | Device:C | Capacitor_SMD:C_0201_0603Metric_Pad0.64x0.40mm_HandSolder | ~
6 | 2 | C14, C15 | 100nF | Device:C_Small | Capacitor_SMD:C_0201_0603Metric_Pad0.64x0.40mm_HandSolder | ~
7 | 2 | C16, C19 | 47uF | Device:C | Capacitor_SMD:C_1206_3216Metric_Pad1.33x1.80mm_HandSolder | ~
8 | 3 | C17, C18, C20 | 100nF | Device:C | Capacitor_SMD:C_0201_0603Metric_Pad0.64x0.40mm_HandSolder | ~
9 | 1 | C21 | 22uF Tant | Device:C_Polarized_Small_US | Capacitor_Tantalum_SMD:CP_EIA-3528-15_AVX-H_Pad1.50x2.35mm_HandSolder | ~
10 | 10 | CF1, CF2, CF3, CF4, CF5, CFA1, CFA2, CFA3, CFA4, CFA5 | 0.1uF | Device:C_Small | Capacitor_THT:C_Axial_L3.8mm_D2.6mm_P7.50mm_Horizontal | ~
11 | 1 | J1 | UART0 IO01 | Connector_Generic:Conn_01x03 | Connector_PinHeader_2.54mm:PinHeader_1x03_P2.54mm_Vertical | ~
12 | 1 | J2 | SERIAL-COMM | AES_Library:CUI_SJ-2524-SMT-TRS-tsw-audio-jack | AES_Library:CUI_SJ-2524-SMT-TRS-audio-jack |  |  | CUI Devices | 4.8mm | 1.05 | SJ-2524-SMT-TR | Manufacturer Recommendations
13 | 1 | J3 | KEY_SND_IF | Connector_Generic:Conn_01x07 | Connector_PinSocket_2.54mm:PinSocket_1x07_P2.54mm_Vertical | ~
14 | 1 | J4 | GPIO28 | Connector_Generic:Conn_01x03 | Connector_PinHeader_2.54mm:PinHeader_1x03_P2.54mm_Vertical | ~
15 | 1 | J5 | I2C-0 | Connector_Generic:Conn_01x04 | Connector_PinSocket_2.54mm:PinSocket_1x04_P2.54mm_Vertical | ~
16 | 1 | J6 | MicroSD-Socket w/Det | Connector:Micro_SD_Card_Det | AES_Library:SDCard-GCT_MEM2075-00-140-01-A | http://katalog.we-online.de/em/datasheet/693072010801.pdf
17 | 1 | J7 | KEY-PADDLE | AES_Library:CUI_SJ-63063B-14TRS-audio-jack | AES_Library:CUI_SJ-63063B-audio-jack |  |  | CUI Devices | 12.5mm | 1.0 |  | Manufacturer Recommendations
18 | 1 | J8 | UART1 IO89 | Connector_Generic:Conn_01x03 | Connector_PinHeader_2.54mm:PinHeader_1x03_P2.54mm_Vertical | ~
19 | 1 | J9 | UI 20-FCC | Connector_Generic:Conn_01x20 | AES_Library:Amphenol_F51L_1x20_P1.00mm_Horizontal-FFC | ~
20 | 1 | J10 | IO_EX | Connector_Generic:Conn_01x07 | Connector_PinHeader_2.54mm:PinHeader_1x07_P2.54mm_Vertical | ~
21 | 1 | J11 | SPKR_L | Connector_Generic:Conn_01x02 | TerminalBlock_Philmore:TerminalBlock_Philmore_TB132_1x02_P5.00mm_Horizontal | ~
22 | 1 | J12 | SPKR_R | Connector_Generic:Conn_01x02 | TerminalBlock_Philmore:TerminalBlock_Philmore_TB132_1x02_P5.00mm_Horizontal | ~
23 | 1 | J13 | UI 20-RBN | Connector_Generic:Conn_02x10_Odd_Even | Connector_PinHeader_2.54mm:PinHeader_2x10_P2.54mm_Vertical | ~
24 | 1 | J14 | AUDIO | AES_Library:CUI_SJ-43516-SMT-4cCPJ | AES_Library:CUI_DEVICES_SJ43516_SMT-CPJ | SJ-43516-SMT-TR
25 | 1 | J15 | SPI-0 | Connector_Generic:Conn_01x07 | Connector_PinSocket_2.54mm:PinSocket_1x07_P2.54mm_Vertical | ~
26 | 1 | J16 | SPI-DISP | Connector_Generic:Conn_01x14 | Connector_PinSocket_2.54mm:PinSocket_1x14_P2.54mm_Vertical | ~
27 | 1 | J17 | SW_MATRIX | Connector_Generic:Conn_01x05 | Connector_PinHeader_2.54mm:PinHeader_1x05_P2.54mm_Vertical | ~
28 | 1 | J18 | UIM 20-FCC | Connector_Generic:Conn_01x20 | AES_Library:Amphenol_F51L_1x20_P1.00mm_Horizontal-FFC | ~
29 | 1 | J19 | UIM 20-RBN | Connector_Generic:Conn_02x10_Odd_Even | Connector_PinHeader_2.54mm:PinHeader_2x10_P2.54mm_Vertical | ~
30 | 1 | JP1 | S0-RX | Connector_Generic:Conn_01x02 | Connector_PinHeader_2.54mm:PinHeader_1x02_P2.54mm_Vertical | ~
31 | 1 | JP2 | J7-BP | Jumper:Jumper_2_Open | Connector_PinHeader_2.54mm:PinHeader_1x02_P2.54mm_Vertical | ~
32 | 1 | JP3 | AUD-SDR- | Connector_Generic:Conn_01x02 | Connector_PinHeader_2.54mm:PinHeader_1x02_P2.54mm_Vertical | ~
33 | 2 | JP-PWR-1, JP-PWR-2 | PWR-APWR-Bridge | Connector_Generic:Conn_02x02_Odd_Even | Connector_PinHeader_2.54mm:PinHeader_2x02_P2.54mm_Vertical | ~
34 | 1 | LED1 | PWR | Device:LED | AES_Library:LED_SMD_SIDEVIEW_Harvatek | ~
35 | 4 | M_KSI1, M_KSI2, M_KSI3, M_KSI4 | MountingHole_Pad | Mechanical:MountingHole_Pad | MountingHole:MountingHole_3.2mm_M3_ISO7380_Pad_TopBottom | ~
36 | 1 | OP1 | BZ-SPK | MuKOB:Option_A-B | Connector_PinHeader_2.54mm:PinHeader_1x03_P2.54mm_Vertical
37 | 6 | OP2, OP3, OP4, OP5, OP6, OP7 | OP_A-B | MuKOB:Option_A-B | Connector_PinHeader_2.54mm:PinHeader_1x03_P2.54mm_Vertical
38 | 1 | OP8 | IO28-ToneR | MuKOB:Option_A-B | Connector_PinHeader_2.54mm:PinHeader_1x03_P2.54mm_Vertical
39 | 1 | OP9 | DISP-BL-PWR | MuKOB:Option_A-B | Connector_PinHeader_2.54mm:PinHeader_1x03_P2.54mm_Vertical
40 | 1 | Q1 | 2N3904 | Transistor_BJT:2N3904 | Package_TO_SOT_THT:TO-92_Inline | https://www.onsemi.com/pub/Collateral/2N3903-D.PDF
41 | 2 | R1, R18 | 100 | Device:R_Small_US | Resistor_SMD:R_0402_1005Metric_Pad0.72x0.64mm_HandSolder | ~
42 | 1 | R2 | DNP | Device:R_US | Resistor_THT:R_Axial_DIN0207_L6.3mm_D2.5mm_P10.16mm_Horizontal | ~
43 | 5 | R3, R8, R9, R24, R25 | 10k | Device:R_US | Resistor_SMD:R_0402_1005Metric_Pad0.72x0.64mm_HandSolder | ~
44 | 5 | R4, R5, R6, R7, R10 | 100k | Device:R_US | Resistor_SMD:R_0402_1005Metric_Pad0.72x0.64mm_HandSolder | ~
45 | 2 | R11, R14 | 220 | Device:R_US | Resistor_SMD:R_0402_1005Metric_Pad0.72x0.64mm_HandSolder | ~
46 | 2 | R12, R15 | 100 | Device:R_US | Resistor_SMD:R_0402_1005Metric_Pad0.72x0.64mm_HandSolder | ~
47 | 2 | R13, R16 | 1.8k | Device:R_US | Resistor_SMD:R_0402_1005Metric_Pad0.72x0.64mm_HandSolder | ~
48 | 1 | R17 | 20k | Device:R_Small_US | Resistor_SMD:R_0402_1005Metric_Pad0.72x0.64mm_HandSolder | ~
49 | 1 | R19 | 47k | Device:R_US | Resistor_SMD:R_0402_1005Metric_Pad0.72x0.64mm_HandSolder | ~
50 | 1 | R20 | 15k | Device:R_US | Resistor_SMD:R_0402_1005Metric_Pad0.72x0.64mm_HandSolder | ~
51 | 1 | R21 | 2.2k | Device:R_US | Resistor_SMD:R_0402_1005Metric_Pad0.72x0.64mm_HandSolder | ~
52 | 1 | R22 | 28k | Device:R_US | Resistor_SMD:R_0402_1005Metric_Pad0.72x0.64mm_HandSolder | ~
53 | 1 | R23 | 6.8k | Device:R_US | Resistor_SMD:R_0402_1005Metric_Pad0.72x0.64mm_HandSolder | ~
54 | 1 | RE1 | RotEnc-SW | Device:RotaryEncoder_Switch | Rotary_Encoder:RotaryEncoder_Bourns_Vertical_PEC12R-3xxxF-Sxxxx | ~
55 | 1 | SW1 | RESET | Switch:SW_Push | AES_Library:SW_PUSH_SMD_1P1T_NO_45x45mm-CK | ~
56 | 1 | SW2 | RE-SO | Switch:SW_Push | AES_Library:SW_PUSH_SMD_1P1T_NO_45x45mm-CK | ~
57 | 1 | SW3 | UP | Switch:SW_Push | AES_Library:SW_PUSH_SMD_1P1T_NO_45x45mm-CK | ~
58 | 1 | SW4 | LF | Switch:SW_Push | AES_Library:SW_PUSH_SMD_1P1T_NO_45x45mm-CK | ~
59 | 1 | SW5 | EN | Switch:SW_Push | AES_Library:SW_PUSH_SMD_1P1T_NO_45x45mm-CK | ~
60 | 1 | SW6 | RT | Switch:SW_Push | AES_Library:SW_PUSH_SMD_1P1T_NO_45x45mm-CK | ~
61 | 1 | SW7 | DN | Switch:SW_Push | AES_Library:SW_PUSH_SMD_1P1T_NO_45x45mm-CK | ~
62 | 1 | SW8 | RE-AO | Switch:SW_Push | AES_Library:SW_PUSH_SMD_1P1T_NO_45x45mm-CK | ~
63 | 1 | SW9 | RE-BO | Switch:SW_Push | AES_Library:SW_PUSH_SMD_1P1T_NO_45x45mm-CK | ~
64 | 1 | TP1 | VOL-A | Test_point_Jump:TP_01 | Connector_PinHeader_2.54mm:PinHeader_1x01_P2.54mm_Vertical | ~
65 | 1 | TP2 | VOL-B | Test_point_Jump:TP_01 | Connector_PinHeader_2.54mm:PinHeader_1x01_P2.54mm_Vertical | ~
66 | 1 | TP3 | AUD-IN | Test_point_Jump:TP_01 | Connector_PinHeader_2.54mm:PinHeader_1x01_P2.54mm_Vertical | ~
67 | 1 | TP4 | TONE-R | Test_point_Jump:TP_01 | Connector_PinHeader_2.54mm:PinHeader_1x01_P2.54mm_Vertical | ~
68 | 1 | TP5 | TONE-L | Test_point_Jump:TP_01 | Connector_PinHeader_2.54mm:PinHeader_1x01_P2.54mm_Vertical | ~
69 | 1 | U1 | MAX3221 | Interface_UART:MAX3221 | AES_Library:TSSOP-16 | http://www.ti.com/lit/ds/symlink/max3221.pdf
70 | 1 | U2 | PicoW | RPi_Pico:PicoW | AES_Library:RPi_PicoW_SMD_TH
71 | 1 | U3 | MCP23S08-E/SO | MuKOB:MCP23S08-E/SO | Package_SO:SOIC-18W_7.5x11.6mm_P1.27mm
72 | 1 | U4 | TLV70033_SOT23-5 | Regulator_Linear:TLV70033_SOT23-5 | Package_TO_SOT_SMD:SOT-23-5 | http://www.ti.com/lit/ds/symlink/tlv700.pdf
73 | 1 | U5 | TPA2012D2RTJT | MuKOB:TPA2012D2RTJT | AES_Library:QFN50P400X400X80-21N270X270 |  |  | TEXAS INSTRUMENTS |  | NA |  | IPC-7351B
74 | 1 | U6 | NC7WZ16P6X | RPi_Pico:NC7WZ16P6X | Package_TO_SOT_SMD:SOT-363_SC-70-6

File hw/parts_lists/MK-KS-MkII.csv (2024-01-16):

Source: | C:\Users\aesil\proj\mukob-hw\MuKOB\hw\MK-KS-MkII.kicad_sch
Date: | 1/13/2024 1:53:58 PM
Tool: | Eeschema 7.0.2
Generator: | C:\Program Files\KiCad\7.0\bin\scripting\plugins/bom_csv_grouped_by_value_with_fp.py
Component Count: | 56
Ref | Qnty | Value | Cmp name | Footprint | Description | Vendor | DNP
C3 | 1 | 10uf | C_Polarized_US | Capacitor_THT:CP_Radial_D8.0mm_P5.00mm | Polarized capacitor, US symbol
C4, C5, C6, C7, C8, C9 | 6 | 0.1u | C | Capacitor_SMD:C_0603_1608Metric_Pad1.08x0.95mm_HandSolder | Unpolarized capacitor
D1, D7, D8 | 3 | MBR0560LT1G | MBR0560 | Diode_SMD:D_SOD-123 | 60V 0.5A Schottky Power Rectifier Diode, SOD-123
D2, D4 | 2 | 1N4148 | 1N4004 | Diode_THT:D_DO-35_SOD27_P7.62mm_Horizontal | 400V 1A General Purpose Rectifier Diode, DO-41
D3, D5 | 2 | 1N4148 | 1N4004 | Diode_SMD:D_SOD-123 | 400V 1A General Purpose Rectifier Diode, DO-41
J2 | 1 | LOOP PWR | Conn_Coaxial_Power | AES_Library:AES-CUI_PJ-037B | coaxial connector (BNC, SMA, SMB, SMC, Cinch/RCA, LEMO, ...)
J3 | 1 | UART Data | Conn_01x03 | Connector_PinHeader_2.54mm:PinHeader_1x03_P2.54mm_Vertical | Generic connector, single row, 01x03, script generated (kicad-library-utils/schlib/autogen/connector/)
J4 | 1 | MuKOB IF | Conn_01x07 | Connector_PinHeader_2.54mm:PinHeader_1x07_P2.54mm_Vertical | Generic connector, single row, 01x07, script generated (kicad-library-utils/schlib/autogen/connector/)
J5 | 1 | KEY-PADDLE | CUI_SJ-63063B-14TRS-audio-jack | AES_Library:AES-CUI_SJ-63063B-audio-jack | 1/4" TRS Stereo Audio Jack w/ts
JP1 | 1 | 3V3-USB | Jumper_2_Open | Connector_PinHeader_2.54mm:PinHeader_1x02_P2.54mm_Vertical | Jumper, 2-pole, open
JP2 | 1 | KEY-IN | Jumper_2_Open | Connector_PinHeader_2.54mm:PinHeader_1x02_P2.54mm_Vertical | Jumper, 2-pole, open
JP3 | 1 | Key Jack NP | Jumper_2_Open | Connector_PinHeader_2.54mm:PinHeader_1x02_P2.54mm_Vertical | Jumper, 2-pole, open
JP4 | 1 | CB0-Dash | Jumper_2_Open | Connector_PinHeader_2.54mm:PinHeader_1x02_P2.54mm_Vertical | Jumper, 2-pole, open
JP5 | 1 | UART-LB | Jumper_2_Open | Connector_PinHeader_2.54mm:PinHeader_1x02_P2.54mm_Vertical | Jumper, 2-pole, open
LED1 | 1 | SNDR | LED | AES_Library:AES-LED_SMD_SIDEVIEW_Harvatek | Light emitting diode
M_KSI1, M_KSI2, M_KSI3, M_KSI4 | 4 | MountingHole_Pad | MountingHole_Pad | MountingHole:MountingHole_3.2mm_M3_ISO7380_Pad_TopBottom | Mounting Hole with connection
OPa1 | 1 | LoopDbgPwr | Conn_01x02 | Connector_PinHeader_2.54mm:PinHeader_1x02_P2.54mm_Vertical | Generic connector, single row, 01x02, script generated (kicad-library-utils/schlib/autogen/connector/)
Q3 | 1 | G01N20LE | 2N7002 | Package_TO_SOT_SMD:SOT-23 | 0.115A Id, 60V Vds, N-Channel MOSFET, SOT-23
Q4 | 1 | 2N3904 | 2N3904 | Package_TO_SOT_THT:TO-92_Inline | 0.2A Ic, 40V Vce, Small Signal NPN Transistor, TO-92
R1 | 1 | 3.3k | R_US | Resistor_SMD:R_0402_1005Metric_Pad0.72x0.64mm_HandSolder | Resistor, US symbol
R2, R5, R6, R8 | 4 | 20k | R_US | Resistor_SMD:R_0402_1005Metric_Pad0.72x0.64mm_HandSolder | Resistor, US symbol
R7 | 1 | 100 | R_US | Resistor_SMD:R_0402_1005Metric_Pad0.72x0.64mm_HandSolder | Resistor, US symbol
R9 | 1 | DNP | R_US | Resistor_SMD:R_0402_1005Metric_Pad0.72x0.64mm_HandSolder | Resistor, US symbol
R10 | 1 | 1k | R_US | Resistor_SMD:R_0402_1005Metric_Pad0.72x0.64mm_HandSolder | Resistor, US symbol
SHLD-1, SHLD-2, SHLD-3, SHLD-4 | 4 | MountingHole_Pad | MountingHole_Pad | MountingHole:MountingHole_4.3mm_M4_ISO14580_Pad_TopBottom | Mounting Hole with connection
ST1 | 1 | SNDR/KOB | Screw_Terminal_01x02 | TerminalBlock_Philmore:TerminalBlock_Philmore_TB132_1x02_P5.00mm_Horizontal | Generic screw terminal, single row, 01x02, script generated (kicad-library-utils/schlib/autogen/connector/)
ST2 | 1 | LOOP RES | Screw_Terminal_01x02 | TerminalBlock_Philmore:TerminalBlock_Philmore_TB132_1x02_P5.00mm_Horizontal | Generic screw terminal, single row, 01x02, script generated (kicad-library-utils/schlib/autogen/connector/)
ST3 | 1 | KEY | Screw_Terminal_01x02 | TerminalBlock_Philmore:TerminalBlock_Philmore_TB132_1x02_P5.00mm_Horizontal | Generic screw terminal, single row, 01x02, script generated (kicad-library-utils/schlib/autogen/connector/)
SW1 | 1 | CLOSER | SW_SPST | AES_Library:AES-SW-TGL-Micro-DPST-CIT | Single Pole Single Throw (SPST) switch
SW2 | 1 | KEY/DOT | SW_Push | AES_Library:AES-SW_PUSH_SMD_1P1T_NO_6x6mm | Push button switch, generic, two pins
SW3 | 1 | DASH | SW_Push | AES_Library:AES-SW_PUSH_SMD_1P1T_NO_6x6mm | Push button switch, generic, two pins
TP1 | 1 | LP2 | TP_01 | Connector_PinHeader_2.54mm:PinHeader_1x01_P2.54mm_Vertical | Test point, single pin
TP2 | 1 | SE | TP_01 | Connector_PinHeader_2.54mm:PinHeader_1x01_P2.54mm_Vertical | Test point, single pin
TP3 | 1 | RV | TP_01 | Connector_PinHeader_2.54mm:PinHeader_1x01_P2.54mm_Vertical | Test point, single pin
TP4 | 1 | LS | TP_01 | Connector_PinHeader_2.54mm:PinHeader_1x01_P2.54mm_Vertical | Test point, single pin
TP5 | 1 | KS- | TP_01 | Connector_PinHeader_2.54mm:PinHeader_1x01_P2.54mm_Vertical | Test point, single pin
U1 | 1 | FT234XF_USB_UART_Module | AES-FTDI_FT234XF_USB_UART_Module | AES_Library:AES-FTDI-UMFT234XF | UMFT234XF USB to a basic UART (RXD, TXD, RTS#, CTS#) Development Module
U4 | 1 | LM393ADR | AES-LM393DR-dk_Linear-Comparators | Package_SO:SOIC-8_3.9x4.9mm_P1.27mm

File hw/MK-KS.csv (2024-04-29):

# | Reference | Qty | Value | Footprint | DNP
1 | C1, C2 | 2 | 1uF | Capacitor_SMD:C_0201_0603Metric_Pad0.64x0.40mm_HandSolder
2 | C3 | 1 | 10uf | Capacitor_THT:CP_Radial_D8.0mm_P5.00mm
3 | C4, C5, C6, C7, C8, C9 | 6 | 0.1u | Capacitor_SMD:C_0603_1608Metric_Pad1.08x0.95mm_HandSolder
4 | D1, D7, D8 | 3 | MBR0560LT1G | Diode_SMD:D_SOD-123
5 | D2, D4 | 2 | 1N4148 | Diode_THT:D_DO-35_SOD27_P7.62mm_Horizontal
6 | D3, D5, D6 | 3 | 1N4148 | Diode_SMD:D_SOD-123
7 | J1 | 1 | USB-PWR | AES_Library:USB_Micro-B_Amphenol_10103594-0001LF_Horizontal_modified
8 | J2 | 1 | LOOP PWR | AES_Library:CUI_PJ-037B
9 | J3 | 1 | MKOB-Serial | Connector_Dsub:DSUB-9_Female_Horizontal_P2.77x2.84mm_EdgePinOffset9.90mm_Housed_MountingHolesOffset11.32mm
10 | J4 | 1 | MuKOB IF | Connector_PinHeader_2.54mm:PinHeader_1x07_P2.54mm_Vertical
11 | J5 | 1 | KEY/PDL | AES_Library:CUI_SJ1-3534NG-audio-jack
12 | JP1, JP3 | 2 | 1x2 Header | Connector_PinHeader_2.54mm:PinHeader_1x02_P2.54mm_Vertical
13 | JP2 | 1 | KEY-IN | Connector_PinHeader_2.54mm:PinHeader_1x02_P2.54mm_Vertical
14 | LED1 | 1 | SNDR | AES_Library:LED_SMD_SIDEVIEW_Harvatek
15 | M_KSI1, M_KSI2, M_KSI3, M_KSI4 | 4 | MountingHole_Pad | MountingHole:MountingHole_3.2mm_M3_ISO7380_Pad_TopBottom
16 | OPa1 | 1 | 5V-SRC | Connector_PinHeader_2.54mm:PinHeader_1x03_P2.54mm_Vertical
17 | OPa2 | 1 | LoopDbgPwr | Connector_PinHeader_2.54mm:PinHeader_1x02_P2.54mm_Vertical
18 | Q1 | 1 | 2N3905 | Package_TO_SOT_THT:TO-92_Inline
19 | Q2, Q4 | 2 | 2N3904 | Package_TO_SOT_THT:TO-92_Inline
20 | Q3 | 1 | G01N20LE | Package_TO_SOT_SMD:SOT-23
21 | R1 | 1 | 3.3k | Resistor_SMD:R_0402_1005Metric_Pad0.72x0.64mm_HandSolder
22 | R2, R10 | 2 | 1k | Resistor_SMD:R_0402_1005Metric_Pad0.72x0.64mm_HandSolder
23 | R3 | 1 | 10k | Resistor_SMD:R_0402_1005Metric_Pad0.72x0.64mm_HandSolder
24 | R4 | 1 | 270 | Resistor_SMD:R_0402_1005Metric_Pad0.72x0.64mm_HandSolder
25 | R5, R6, R8 | 3 | 20k | Resistor_SMD:R_0402_1005Metric_Pad0.72x0.64mm_HandSolder
26 | R7 | 1 | 100 | Resistor_SMD:R_0402_1005Metric_Pad0.72x0.64mm_HandSolder
27 | R9 | 1 | DNP | Resistor_SMD:R_0402_1005Metric_Pad0.72x0.64mm_HandSolder
28 | SHLD-1, SHLD-2, SHLD-3, SHLD-4 | 4 | MountingHole_Pad | MountingHole:MountingHole_4.3mm_M4_ISO14580_Pad_TopBottom
29 | ST1 | 1 | SNDR/KOB | TerminalBlock_Philmore:TerminalBlock_Philmore_TB132_1x02_P5.00mm_Horizontal
30 | ST2 | 1 | LOOP RES | TerminalBlock_Philmore:TerminalBlock_Philmore_TB132_1x02_P5.00mm_Horizontal
31 | SW1 | 1 | CLOSER | AES_Library:SW-TGL-Micro-DPST-CIT
32 | SW2 | 1 | KEY/DOT | AES_Library:SW_PUSH_SMD_1P1T_NO_6x6mm
33 | SW3 | 1 | DASH | AES_Library:SW_PUSH_SMD_1P1T_NO_6x6mm
34 | TP1 | 1 | LP2 | Connector_PinHeader_2.54mm:PinHeader_1x01_P2.54mm_Vertical
35 | TP2 | 1 | SE | Connector_PinHeader_2.54mm:PinHeader_1x01_P2.54mm_Vertical
36 | TP3 | 1 | RV | Connector_PinHeader_2.54mm:PinHeader_1x01_P2.54mm_Vertical
37 | TP4 | 1 | LS | Connector_PinHeader_2.54mm:PinHeader_1x01_P2.54mm_Vertical
38 | TP5 | 1 | KS- | Connector_PinHeader_2.54mm:PinHeader_1x01_P2.54mm_Vertical
39 | U1 | 1 | MCP1702T-3302E | Package_TO_SOT_SMD:SOT-23
40 | U3 | 1 | LM358 | Package_SO:SOIC-8_3.9x4.9mm_P1.27mm
41 | U4 | 1 | LM393ADR | Package_SO:SOIC-8_3.9x4.9mm_P1.27mm

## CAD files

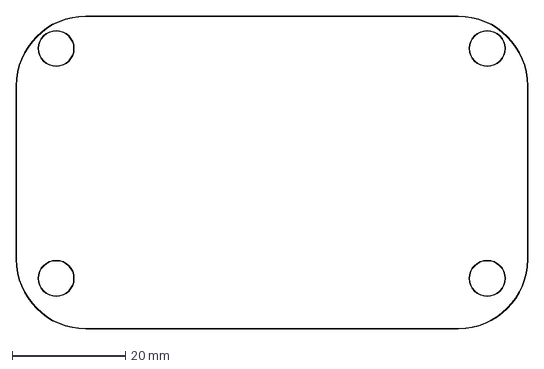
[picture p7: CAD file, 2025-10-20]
hw/dxf/MK-IF-MkV-Insulator.dxf
90.3 x 55.2 mm

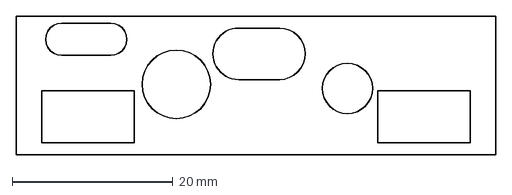
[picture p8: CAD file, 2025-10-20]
hw/dxf/MK-IF-MkV-Faceplate_2-0.dxf
59.6 x 17.2 mm

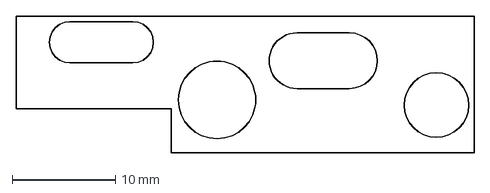
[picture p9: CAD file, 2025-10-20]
hw/dxf/MK-IF-MkV-Faceplate.dxf
44.4 x 13.3 mm

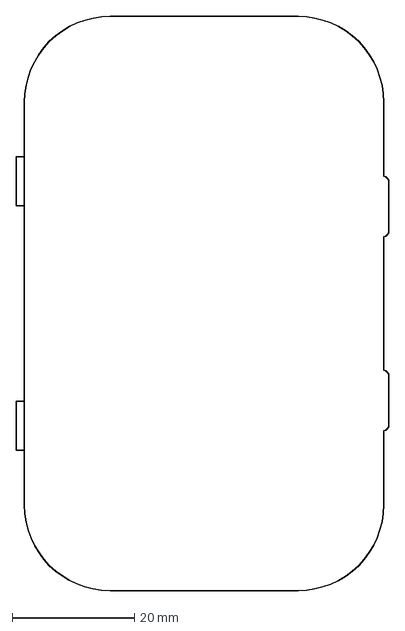
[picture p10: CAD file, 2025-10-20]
hw/dxf/Altoid-Bottom-Outline.dxf
61.0 x 93.9 mm

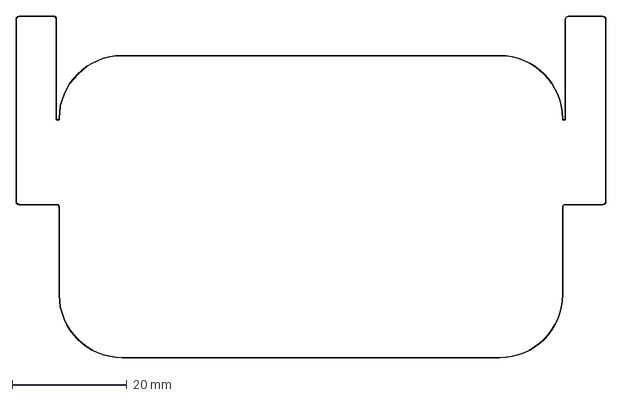
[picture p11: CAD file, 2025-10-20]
hw/dxf/MK-IF-MkV-PCB-Outline.dxf
103.0 x 59.6 mm

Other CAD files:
hw/step/MK-KS.step
hw/step/MuKOB.step

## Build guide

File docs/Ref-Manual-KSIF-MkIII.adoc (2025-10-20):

= μKOB KS Interface MkIII: Reference Manual
include::man_settings.adoc[]
//include::../mukobversion.txt[]
:title: μKOB KS Interface MkIII: Reference Manual
:docver: 1.1
:docdate: 20240506
:organization: Silky Design - AES
:copyright: Copyright (c) 2023-24 AESilky
:license: MIT License
:doctype: book
:description: μKOB KOB/Key/Paddle/Sounder Interface MkIII
:imagesdir: ./images

toc::[]

[introduction]
= Introduction
This is the reference manual for the μKOB Key/Sounder/KOB/Paddle Interface MkIII. It is not intended as a tutorial, and it is not a user manual for the μKOB device. It describes the external device connections, the jumper settings, and how to use the test features of the interface board.

[preface%nonfacing]
= Preface
At a high level, the ((μKOB KS Interface)) (board) provides an interface between the ((μKOB)) main board and a ((KOB)) or a separate ((Key & Sounder)). It is also capable of being used as a KOB/Key&Sounder interface for the ((MKOB)) application running on a ((Raspberry Pi)) through the ((GPIO)) (((GPIO, Raspberry Pi))) connector,footnote:gpiorpi[In this document the term _the GPIO_ will be used to refer to the Raspberry Pi GPIO connector/connection.] or for the ((MKOB)) or ((MorseKOB)) application running on any system that supports an FTDIfootnote:ftdi[Future Technology Devices International (*FTDI*) is the manufacturer of the USB-Serial module used. The FTDI _Virtual Serial Port_ driver is part of the Linux and MacOS kernel, and auto-installs on Windows.] USB serial port.

Depending on the intended application - ((μKOB)), ((Raspberry Pi)), or ((USB Serial)) - certain components may or may not, be populated. The possible options are:footnote:ifconn[Since this interface board connects to μKOB and Raspberry Pi using a _((piggyback))_ connector on the bottom of the board, it isn't possible to assemble a board that can be used on both a μKOB and a Raspberry Pi.]

1. μKOB Only
2. μKOB + USB Serial
3. Raspberry Pi GPIO Only
4. Raspberry Pi + USB Serial
5. USB Serial Only

Following are sections that identify all of the connectors and option jumpers, setting the option jumpers for applications 1, 3, and 5 (2 and 4 can be deduced), connecting a KOB, a Key & Sounder, or a Paddle, including power options and current limit resistor. Finally, there is a section on using the test key/paddle & sounder portion of the board (when the real thing isn't available, or isn't practical).

This interface can be used with a KOB (_KOB_ = _Key On Board_, a Sounder and Key connected in series, typically as a single unit on a base) (((KOB, Key On Board))) or a separate key and sounder (((Key & Sounder, separate))). The KOB, or a key and sounder connected in series, will sometimes be referred to as _The Loop Circuit_, _The Loop_, or simply, _Loop_ (((Loop, Loop Circuit))).

TIP: When carrying a ((stand-alone)) interface board, it is suggested that you hold it by the bottom, edges, or shield rather than by the USB cable. Carrying it by the USB cable has a tendency to cause the micro-USB connector to part ways with the USB-Serial Module that it was assembled to, and you will be left holding a USB cable and connector and the interface board will be on the floor. You will then need to test your surface mount soldering, and possibly trace repair, skills.

== Connectors, Controls, and Option Jumpers

[%breakable]
=== Connectors and Controls
[%unbreakable]
--
Going clockwise around the board, the connectors and controls are:

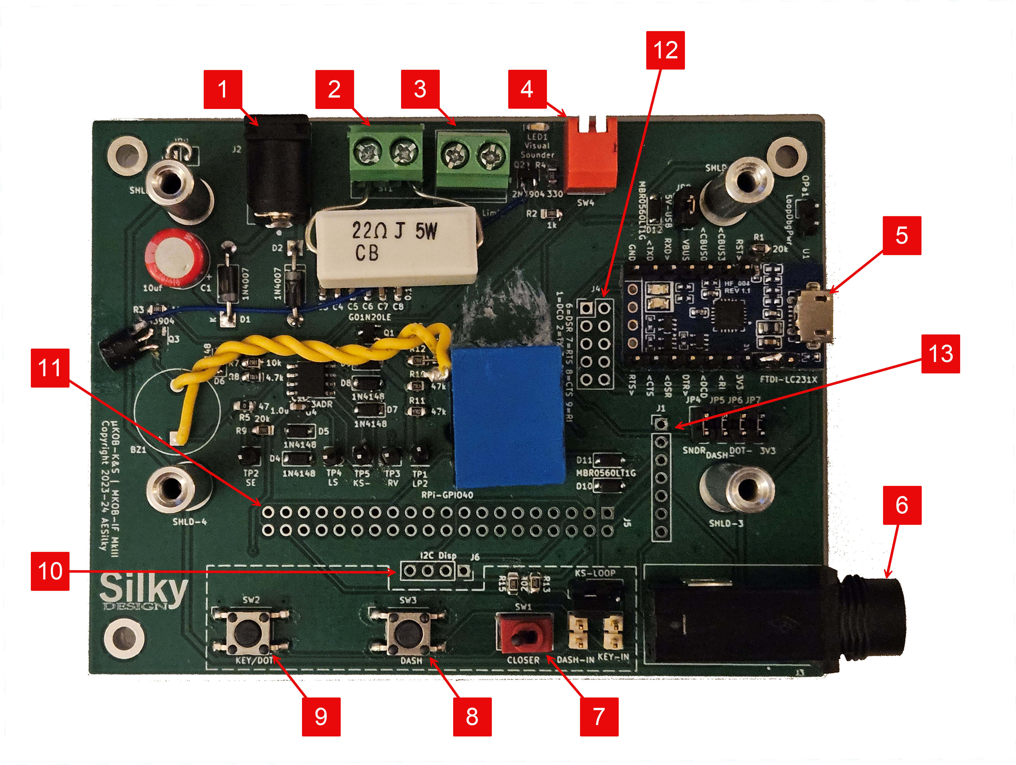
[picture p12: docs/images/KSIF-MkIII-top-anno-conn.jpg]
Connectors and Controls

--

.Interface Board Connectors
[%breakable]
[width=98%]
[cols="^.<1,<.<3,<.<10,^.<3",options=header]
|===
|#
|Connector / Control
|Usage
|Schematic Designator

|1
|Power Jack 2x5.5mm: Sounder/Loop Power
|This barrel connector is a typical size for _wall wart_ and small _inline_ power supplies in the 9v-24v range that can be used to power the sounder or KOB loop. The center pin is positive. This input is reverse polarity protected. Refer to the <<Sounder / KOB Loop Connection>> section for suggestions on selecting a power source.
|J2

|2
|2pos Screw Terminal (inward facing): Sounder Current Limit
|Used to connect a current limiting resistor for the sounder or KOB loop power (((KOB, loop power))). Refer to the <<Sounder / KOB Loop Connection>> section for suggestions on selecting an appropriate resistor value.
|ST1

|3
|2pos Screw Terminal: Sounder/KOB
|The connection to the Sounder/KOB. This is *The Loop*. Refer to the <<Sounder / KOB Loop Connection>> section for notes about connecting to a loop that is externally powered.
|ST2

|4
|2pos Switch: Mini Sounder & Visual Sounder Enable
|Pos-1 (left) enables the _Visual Sounder Indicator_. Pos-2 (right) enables the _Mini Sounder_. Down enables the feature, up disables the feature.
|SW4

|5
|USB (Micro-B): Serial interface and logic power
|Serial connection to a host running MKOB or MorseKOB. This is also used to supply power to the logic portion of the interface board when being used _((stand-alone))_.

*IMPORTANT:* If the interface board is attached to a *μKOB* or a *Raspberry Pi*, refer to the <<Option Jumpers>> section before connecting to this USB connector.
|U1

|6
|1/4in Stereo (TRS): Key/Paddle
|Key/Paddle input for use with a separate Key & Sounder. Refer to the <<Key/Paddle Input>> section for connection details.
|J3

|7
|Toggle Switch: Test Closer
|The key closer for the mini-test key portion. Lever to the left (toward the pushbutton switches) is CLOSED, to the right is OPEN.
|SW1

|8
|Pushbutton Switch: Test Paddle-Dash (Dah)
|The _Dash_ sender of the mini-test paddle.
|SW3

|9
|Pushbutton Switch: Test Key / Paddle-Dot (Dit)
|The mini-test key, or the _Dot_ sender of the mini-test paddle.
|SW2

|10
|1x4 Socket: I2C Disp
|Connection for an I2C display panel for a Raspberry Pi through the GPIO connector.  This 4-pin socket connector is connected to the I2C-1 GPIO pins for use with a small OLED panel.
|J6

|11
|2x20 Socket: GPIO
|Connection to a Raspberry Pi GPIO connector.  The 40-pin socket connector is populated on the bottom of the board.
|J5

|12
|2x5 Header: Serial I/O
|10-pin header for the serial port I/O signals. This can connect to a DB9 ribbon cable or to a piggyback'ed μKOB Comm Adaptor board.
|J4

|13
|1x7 Socket: μKOB
|Connection to a μKOB main board. The 7-pin socket connector is populated on the bottom of the board.
|J1

|NA
|7 Pin x 2 Rows on USB-Serial Module
|The two 7-pin header rows on the USB-Serial Module connect the module to the interface board. They are not intended to be used, and must not be jumpered. The signals are labeled on the interface board, and can be used for testing if needed.
|U1

|===

[%breakable]
=== Option Jumpers
[%unbreakable]
--
The option jumpers described in this section may or may not be configurable (via pins and jumpers) depending on how the interface board was assembled. It is possible that the options are hard-jumpered a specific way and cannot be changed. Unless noted, the option jumpers are either ON (jumpered) or OFF (open). Option jumper OP1 is the one 2-position option (left-right).

Going clockwise around the board, the option jumpers are:

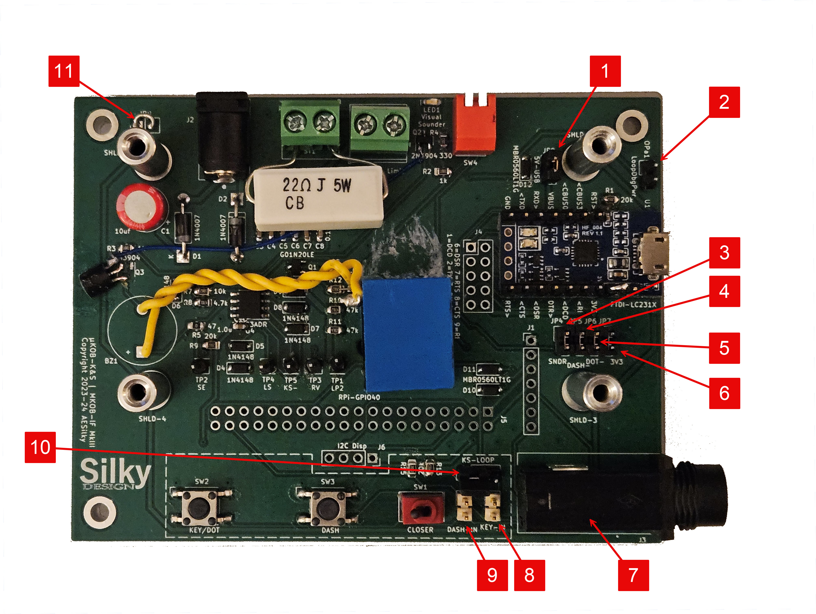
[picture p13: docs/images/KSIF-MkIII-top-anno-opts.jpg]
Option Jumpers

--

.Interface Board Option Jumpers
[%breakable]
[width=98%]
[cols="^.<1,<.<3,<.<10,^.<3",options=header]
|===
|#
|Name
|Usage
|Schematic Designator

|1
|5V-USB
|When jumpered, 5 volt power to the board is supplied by the USB connection. When open, 5 volt power is supplied by the μKOB or GPIO.
|JP8

|2
|LoopDbgPwr
|When jumpered, power is supplied to the Sounder / KOB Loop circuit from the 5V board (logic) power.
|OPa1

|3
|SNDR
|When jumpered, the sounder drive is from the USB (serial) RTS line. When open, the sounder drive is from the μKOB or GPIO.
|JP4

|4
|DASH-
|When jumpered, the paddle dash signal is sent to the USB (serial) CTS line. When open, the paddle dash signal is sent to the μKOB or GPIO.
|JP5

|5
|DOT-
|When jumpered, the key / paddle dot signal is sent to the USB (serial) DSR line. When open, the key / paddle dot signal is sent to the μKOB or GPIO.
|JP6

|6
|3V3
|When jumpered, 3.3 volt power to the board is supplied by the USB connection. When open, 3.3 volt power is supplied by the μKOB or GPIO.
|JP7

|7
|KeyJack-NP
|This must be jumpered when the Key/Paddle Jack (J3) is not installed. The jumper and markings are located within the border of the jack.
|JP1

|8
|KEY-IN
|When jumpered, the key / paddle dot signal is connected to the interface board. When open, the signal is not connected, allowing the mini-test key function to be used.
|JP3

|9
|DASH-IN
|When jumpered, the paddle dash signal is connected to the interface board. When open, the signal is not connected, allowing the mini-test key function to be used.
|JP2

|10
|KS-LOOP
|This 2-position jumper selects how the mini-test key and sounder are connected. When the jumper is to the *KS* side, the mini-test is connected as a separate key & sounder. When the jumper is to the *LOOP* side, the mini-test is connected as a loop (key and sounder in series). The paddle-dash is always separate, and when testing as a paddle the jumper should be in the *KS* position.
|OP1

|11
|JP9
|When jumpered, the shield (Altoids can) is connected to power/signal ground.
|JP9

|===

[%nonfacing]
== Option Settings
Following are the option settings for the different applications of the interface board.

[%breakable]
=== Common
[%unbreakable]
--
The option jumper settings in this section are common to all applications of the interface board.
--

.Common Option Jumpers
[%breakable]
[width=98%]
[cols="^.<3,<.<5,<.<5",options=header]
|===
|Name / Designator
|Typical Setting
|Alternate Setting Use

|LoopDbgPwr / OPa1
|OPEN
|Jumper to provide 5 volt power to the loop circuit for board testing.

|KEY-IN / JP3
|JUMPERED
|Open to use the on-board test key and closer when the external key can't be left open.

|DASH-IN / JP2
|JUMPERED
|Open to use the on-board test paddle if the external paddle can't be left open.

|KS-LOOP / OP1
|LEFT = Key&Sounder / RIGHT = Loop Configuration of the on-board test key and sounder.
|Must be jumpered to left or right for the on-board test sounder (visual or mini) to operate.

|JP9
|JUMPERED. This connects the shield to the board's (electrical) ground.
|Open to isolate the shield from the board. When this is done, one of the shield screws can be used to attach an external ground for the shield.

|===

[%breakable]
=== μKOB (Configurations 1 and 2)
[%unbreakable]
--
In addition to the common option jumper settings, the following settings apply when the interface board is being attached to a μKOB via piggyback connector J1.(((μKOB, Attached, J1))) If the board is only being used with a μKOB, the board most likely does not have the ((FTDI USB-Serial Module (U1))) populated. If that is the case, many of the jumpers in this section will also not be populated, and therefore will be OPEN.
--

[%unbreakable]
--
.μKOB Option Jumpers
[width=98%]
[cols="^.<3,<.<5,<.<5",options=header]
|===
|Name / Designator
|Setting
|Operation

|SNDR / JP4
|OPEN
|USB interface sounder drive signal is disconnected from the board.

|DASH- / JP5
|OPEN
|USB interface dash input is disconnected from the board.

|DOT- / JP6
|OPEN
|USB interface dot input is disconnected from the board.

|3V3 / JP7
|OPEN
|USB interface 3.3 volt source is disconnected from the board.

|5V-USB / JP8
|OPEN
|USB interface 5 volt source is disconnected from the board.

|RPI-GPIO40 / J5
|NON-EXISTENT
|A Raspberry Pi cannot be connected.

|===
--

[%breakable]
=== Raspberry Pi GPIO (Configurations 3 and 4)
[%unbreakable]
--
In addition to the common option jumper settings, the following settings apply when the interface board is being attached to a Raspberry Pi via piggyback connector J5.(((Raspberry Pi, Attached, J5))) If the board is only being used with a Raspberry Pi, the board most likely does not have the ((FTDI USB-Serial Module (U1))) populated. If that is the case, many of the jumpers in this section will also not be populated, and therefore will be OPEN.
--

.Raspberry Pi Option Jumpers
[%breakable]
[width=98%]
[cols="^.<3,<.<5,<.<5",options=header]
|===
|Name / Designator
|Setting
|Operation

|SNDR / JP4
|OPEN
|USB interface sounder drive signal is disconnected from the board.

|DASH- / JP5
|OPEN
|USB interface dash input is disconnected from the board.

|DOT- / JP6
|OPEN
|USB interface dot input is disconnected from the board.

|3V3 / JP7
|OPEN
|USB interface 3.3 volt source is disconnected from the board.

|5V-USB / JP8
|OPEN
|USB interface 5 volt source is disconnected from the board.

|I2C Disp / J6
|OPTIONAL
|Connects an I2C OLED Display panel to the Raspberry Pi GPIO (Pin1=GND, Pin2=3.3V/P1, Pin3=SCL/GP3/P5, Pin4=SDA/GP2/P3).

|μKOB / J1
|NON-EXISTENT
|A μKOB cannot be connected.

|===

[%breakable]
=== USB Serial (Configuration 5, plus 2 and 4)
[%unbreakable]
--
In addition to the common option jumper settings, the following settings apply when the interface board is being used through the USB Serial connection to a system running MKOB or MorseKOB. If the board is assembled for use only with the USB Serial interface, the options in this section are most likely permanently jumpered.
--

.USB Serial Option Jumpers
[%breakable]
[width=98%]
[cols="^.<3,<.<5,<.<5",options=header]
|===
|Name / Designator
|Setting
|Operation

|SNDR / JP4
|JUMPERED
|USB interface sounder drive signal is driving the board circuit.

|DASH- / JP5
|JUMPERED
|USB interface dash input is from the board circuit.

|DOT- / JP6
|JUMPERED
|USB interface dot input is from the board circuit.

|3V3 / JP7
|JUMPERED
|USB interface 3.3 volt source is powering the board.

|5V-USB / JP8
|JUMPERED
|USB interface 5 volt source is powering the board.

|μKOB / J1
|NO
|A μKOB cannot be connected.

|RPI-GPIO40 / J5
|NO
|A Raspberry Pi cannot be connected.

|===

[%nonfacing]
== Sounder / KOB Loop Connection
[%unbreakable]
--
A Sounder or a KOB Loop (key and sounder connected in series) are connected to the interface board using the screw-terminal block ST2. A user-supplied ((current limiting resistor))(((resistor, current limiting))) must be connected to screw-terminal block ST1. The resistor is positioned on the inside (under the shield) to reduce ((radio interference)) and to help guard against touching it, as it may become warm during operation.

Power for the sounder/loop is normally provided by a user-supplied power module connected via J2. Refer to the <<Externally Powered Loop>> section below if connecting to a powered telegraph loop.

Selecting the appropriate power module voltage and the current limiting resistor value depends on the sounder being used. The following table provides values that can be used as a starting point.

NOTE: The values in the table are meant to be used with this interface board and a Sounder or KOB for enjoying and practicing land-line telegraphy. They are not meant to indicate what was used in actual telegraph circuits _of the day_.

CAUTION: Some telegraphy enthusiasts use higher voltages and/or lower valued current limiting resistors to get a more _SNAPPY_ sound/response. Just remember that, in most cases, you are dealing with antique equipment that, if damaged, can be impossible to repair. If the sounder windings are over-powered long enough, or too many times, it can cause the (very thin) insulation coating the (extremely fine) wire to fail, causing an internal short. This results in the sounder becoming an interesting paper weight or conversation provoking door stop, rather than a functional telegraph instrument. It is suggested that you start with a lower voltage and/or higher resistor value. Then, if the sound produced isn't satisfactory, slightly increase the voltage *or* decrease the resistor value until a good, solid, *CLICK* is produced. Note that the *CLACK* is produced by the spring and other adjustments of the sounder, so voltage and resistance values don't really affect it.
--

[%unbreakable]
--
.Example Sounder / KOB Loop Voltage and Current Limit Resistor Values
[width=98%]
[cols="<.<10,<.<3,<.<3,^.<5,^.<5",options=header]
|===
|Instrument
|Nominal Current
|Voltage Drop
|Power Supply Voltage (J2)
|Current Limit Resistor Ohms (ST1)

|Line Sounder, 30 Ohms
|70 ma
|2.1v
|9v / 12v
|39 / 150 1W

|Line Sounder, 120 Ohms
|40 ma
|4.0v
|12v / 18v
|180 / 330 1W

|Local Sounder / KOB, 4 Ohms
|240 ma
|0.96v
|9v / 12v
|16 / 47 3W

|Local Sounder, 50 Ohms
|110 ma
|5.5v
|12v / 18v
|56 / 110 3W

|Local Sounder, 400 Ohms
|30 ma
|12v
|18v / 24v
|200 / 400 1W

|===
--

[%breakable]
=== Externally Powered Loop
The interface board is designed to make it easy to set up a personal telegraph station by providing a convenient way to provide power to the Sounder / KOB Loop. However, rather than powering the Sounder / KOB Loop from a power supply connected to J2, the interface board can be connected into a powered telegraph loop if the following conditions are met:

* The loop power must be DC
* The loop voltage must not exceed 30 volts (regardless of the amperage)
* The loop amperage must not exceed 1 amp (regardless of the voltage)
* The loop wattage must not exceed 1.8 watts (all sounders and other equipment in the loop energized)

If the existing telegraph loop has appropriate current limiting, the current limit resistor normally connected to ST1 can be replaced by a jumper wire. ST1 must have a resistor or a jumper wire in order to complete the loop circuit.

When connecting to a powered telegraph loop the J2 power connector must be jumpered. This can be accomplished using a shorting connector.

The interface board must be connected into the telegraph loop with the negative side of the loop circuit connected to the screw terminal nearer the J2 Power Jack (right side when viewing the face of the terminal block) and the positive side of the loop circuit connected to the screw terminal away from the J2 Power Jack (left when viewing the face of the terminal block). The interface board will introduce a 1.5 volt drop into the telegraph loop circuit.

[%nonfacing]
== Key/Paddle Input
[%unbreakable]
--
When using a separate key and sounder, or a paddle, the ((key)) or ((paddle))(((connecting, key or paddle))) is connected to the 1/4 inch phone jack ((J3)).

IMPORTANT: No power should be applied to this connection.

The connection is the same as many common HAM radios. It is illustrated below:
--

.Key/Paddle Connection
[%breakable]
[width=50%]
[cols="<.<1,<.<4"]
|===
|Tip
|Key or Paddle Dot

|Ring
|Paddle Dash

|Sleeve
|Common

|===

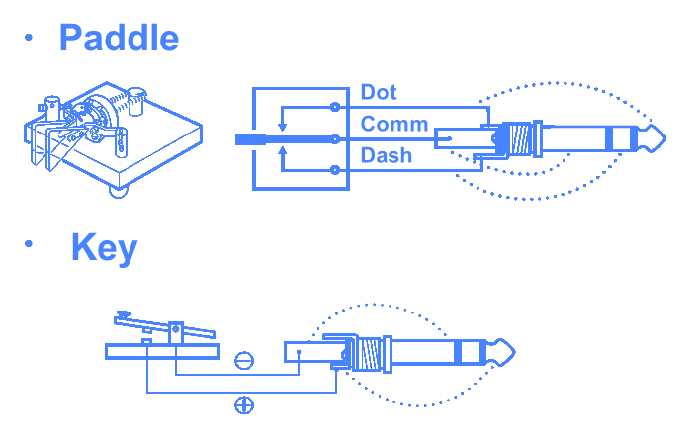
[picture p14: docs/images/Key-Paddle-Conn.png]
Key/Paddle Jack Connection


[%nonfacing]
== Connection Diagrams

.Separate Key and Sounder, powered through the interface
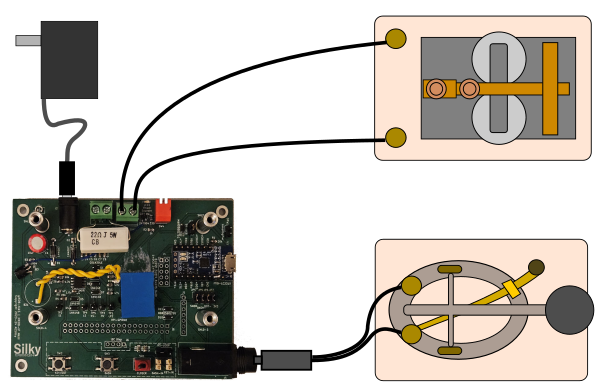
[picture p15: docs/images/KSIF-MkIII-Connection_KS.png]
Key & Sounder


.Separate Key and Sounder with external power
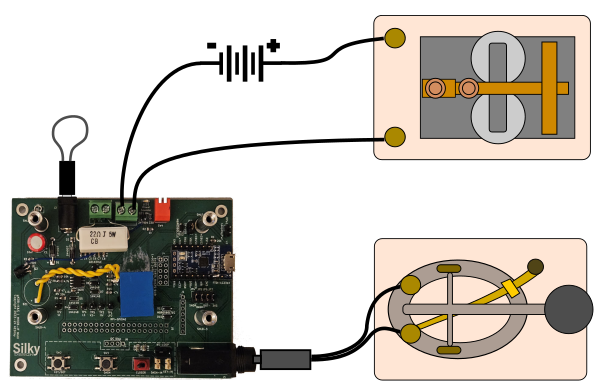
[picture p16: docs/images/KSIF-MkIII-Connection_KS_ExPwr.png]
Key & Sounder with External Power


.KOB or Loop, powered through the interface
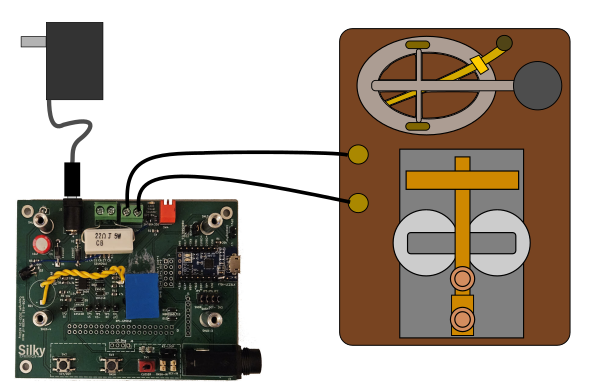
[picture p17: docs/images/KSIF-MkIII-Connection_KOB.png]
KOB (Loop)


.KOB or Loop with external power
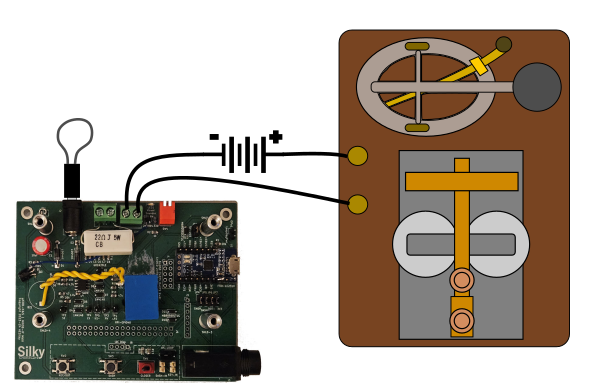
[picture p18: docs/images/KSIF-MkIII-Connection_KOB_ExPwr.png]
KOB (Loop) with External Power


[%nonfacing]
== Optional Test Key/Paddle and Visual/Mini Sounder
For testing μKOB or MKOB it can be handy to have a small, self-contained device that includes a key and sounder. This interface board optionally provides a _((Visual Sounder))_, a _((Mini Sounder))_, and a _Key_(((key))) with _Closer_(((closer))) switch, and a _((Paddle-Dash))_ switch. The _((Visual Sounder))_ and _((Mini Sounder))_ can be enabled/disabled individually using the 2-position ((DIP-Switch))(((DIP-Switch, 2-position))) (SW4). The test features do not require the Sounder/Loop power (J2), the Sounder Current Limit resistor (ST1), or a Sounder/KOB (ST2).

To use the key+closer when an external key is attached, the ((JP2)) jumper can be removed or the external key can be left open. Normally, nothing special needs to be done to use the _((Paddle Switches))_, as a paddle doesn't close the circuit when it's not being used.

((Option Jumper)) OP1 (((Option Jumper, OP1))) configures the test key+closer and visual sounder and mini sounder as either a ((separate key and sounder)) or a ((loop)) circuit. This configuration only affects the test key and sounder, it does not change the external circuit.

NOTE: Technically, the test key/paddle, visual sounder, and mini sounder are in parallel with the actual, external, telegraph equipment. Therefore, when using the actual telegraph equipment the test closer, if installed, must be open in order for the telegraph key's operation to be recognized.

=== Adjusting Tone
The _((Mini Sounder))_ ((tone)) can be adjusted by tightening or loosening the screws that hold down the ((shield tin)) (((shield tin, Altoids))).

ifdef::backend-pdf[]
[index]
== Index
endif::[]

[colophon%nonfacing]
= Colophon
This document is for PCB: μKOB-K&S | MKOB-IF MkIII v1.0 with Cv2 mods
--
Document version: {docver} ({docdate})
--

{license}

{copyright}

This document is authored using *asciidoc*, and the pdf version rendered through
*asciidoctor-pdf*, to create a manual that is more readable and more pleasing to the eye.

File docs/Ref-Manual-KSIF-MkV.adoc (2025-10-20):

= μKOB KS Interface MkV: Reference Manual
include::man_settings.adoc[]
//include::../mukobversion.txt[]
:title: μKOB KS Interface MkV: Reference Manual
:docver: 1.0
:docdate: 20240821
:organization: Silky Design - AES
:copyright: Copyright (c) 2023-24 AESilky
:license: MIT License
:doctype: book
:description: μKOB KOB/Key/Paddle/Sounder Interface MkV
:imagesdir: ./images

toc::[]

[introduction]
= Introduction
This is the reference manual for the μKOB Key/Sounder/KOB/Paddle Interface MkV. It is not intended as a tutorial, and it is not a user manual for the μKOB device. It describes the external device connections to, and jumper settings of, the interface board.

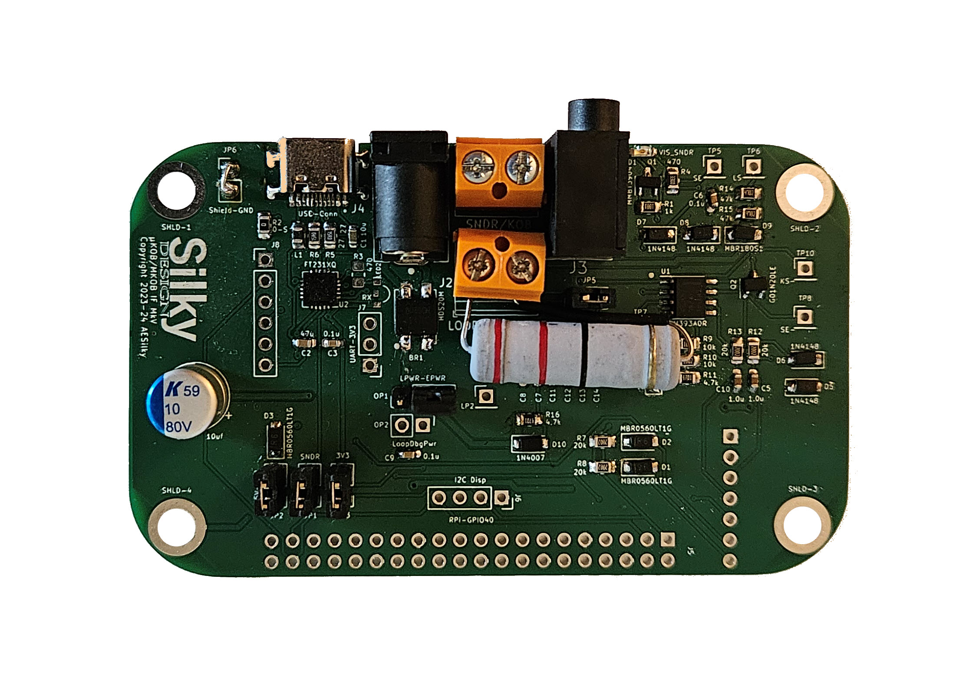
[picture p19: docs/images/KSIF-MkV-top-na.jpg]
The Interface Board


[preface%nonfacing]
= Preface
At a high level, the ((μKOB KS Interface)) (board) provides an interface between the ((μKOB)) main board and a ((KOB)) or a separate ((Key & Sounder)). It is also capable of being used as a KOB/Key&Sounder interface for the ((MKOB)) application running on a ((Raspberry Pi)) through the ((GPIO)) (((GPIO, Raspberry Pi))) connector,footnote:gpiorpi[In this document the term _the GPIO_ will be used to refer to the Raspberry Pi GPIO connector/connection.] or for the ((MKOB)) or ((MorseKOB)) application running on any system that supports a FTDIfootnote:ftdi[Future Technology Devices International (*FTDI*) is the manufacturer of the USB-Serial device used. The FTDI _Virtual Serial Port_ driver is part of the Linux and MacOS kernel, and auto-installs on Windows.] USB serial port.

Depending on the intended application - ((μKOB)), ((Raspberry Pi)), or ((USB Serial)) - certain components may or may not, be populated. The possible options are:footnote:ifconn[Since this interface board connects to μKOB and Raspberry Pi using a _((piggyback))_ connector on the bottom of the board, it isn't possible to assemble a board that can be used on both a μKOB and a Raspberry Pi.]

1. μKOB Only
2. μKOB + USB Serial
3. Raspberry Pi GPIO Only
4. Raspberry Pi + USB Serial
5. USB Serial Only

Following are sections that identify all of the connectors and option jumpers, setting the option jumpers for applications 1, 3, and 5 (2 and 4 can be deduced), connecting a KOB, a Key & Sounder, or a Paddle, including power options and current limit resistor.

This interface can be used with a KOB (_KOB_ = _Key On Board_, a Sounder and Key connected in series, typically as a single unit on a base) (((KOB, Key On Board))) or a separate key and sounder (((Key & Sounder, separate))). Within this document, a KOB or a key and sounder connected in series, will sometimes be referred to as _The Loop Circuit_, _The Loop_, or simply, _Loop_ (((Loop, Loop Circuit))).

== MKOB Suite Auto-Detect (USB Serial)

When using a single interface connected via the USB Serial and the MKOB Suite of applications (MKOB, MRT, Telegram, and the utilities), the configuration (preferences) can be set to auto-detect the interface. Using Configure (or the Preferences in MKOB) set the Serial Port value to *SDIF* (Silky Design Interface)(((SDIF, Silky Design Interface))). The value must by typed in manually. With the serial port set to *SDIF*, the application will search for the interface and once found it will automatically be used.

If more than one Silky Design interface is connected, the first interface found will be used.

== Connectors, Controls, and Option Jumpers

[%breakable]
=== Connectors and Controls
[%unbreakable]
--
Going clockwise around the board, the connectors are:

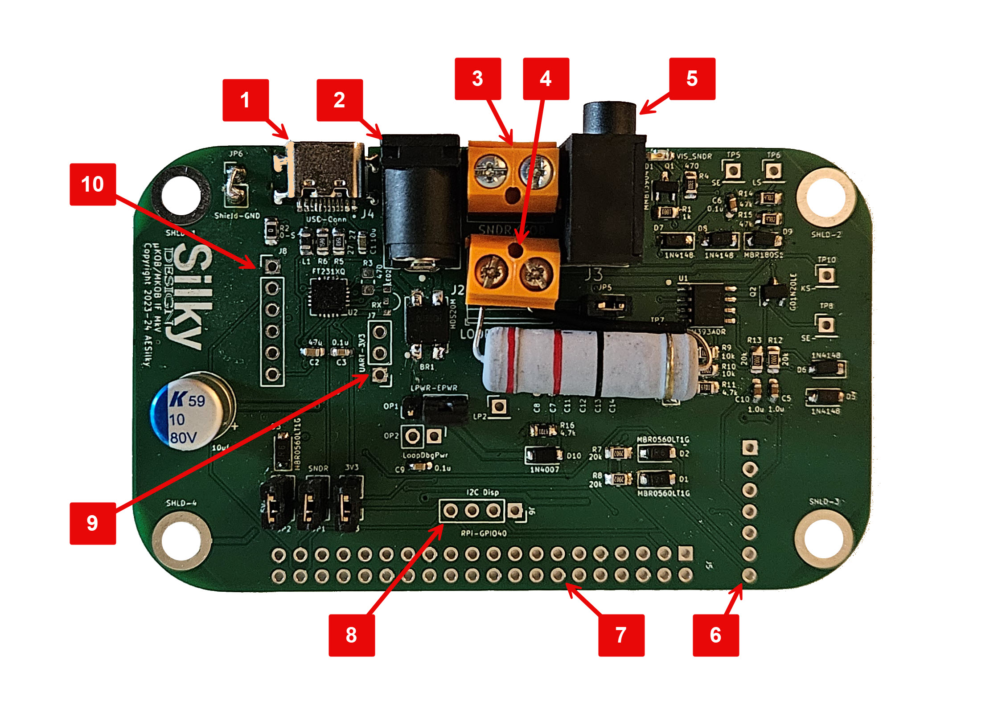
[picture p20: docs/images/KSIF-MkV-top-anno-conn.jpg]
Connectors

--

.Interface Board Connectors
[%breakable]
[width=98%]
[cols="^.<1,<.<3,<.<10,^.<3",options=header]
|===
|#
|Connector / Control
|Usage
|Schematic Designator

|1
|USB (USB-C): Serial interface and logic power
|Serial connection to a host running MKOB or MorseKOB. This is also used to supply power to the logic portion of the interface board when being used _((stand-alone))_.

*IMPORTANT:* If the interface board is attached to a *μKOB* or a *Raspberry Pi*, refer to the <<Option Jumpers>> section, and *DO NOT CONNECT* to this USB connector.
|J4

|2
|Power Jack 2x5.5mm: Sounder/Loop Power
|This barrel connector is a typical size for _wall wart_ and small _inline_ power supplies in the 9v-24v range that can be used to power the sounder or KOB loop. Typically the center pin is positive, but either polarity will work. Refer to the <<Sounder / KOB Loop Connection>> section for suggestions on selecting a power source.
|J2

|3
|2pos Screw Terminal: Sounder/KOB
|The connection to the Sounder/KOB. This is *The Loop*. Refer to the <<Sounder / KOB Loop Connection>> section for notes about connecting to a loop that is externally powered.
|ST1

|4
|2pos Screw Terminal (inward facing): Sounder Current Limit
|Used to connect a current limiting resistor for the sounder or KOB loop power(((KOB, loop power))). Refer to the <<Sounder / KOB Loop Connection>> section for suggestions on selecting an appropriate resistor value.
|ST2

|5
|1/8" Stereo (TRS): Key/Paddle
|Key/Paddle input for use with a separate Key & Sounder. Refer to the <<Key/Paddle Input>> section for connection details.
|J3

|6
|1x7 Socket: μKOB
|Connection to a μKOB main board. The 7-pin socket connector is populated on the bottom of the board.
|J1

|7
|2x20 Socket: GPIO
|Connection to a Raspberry Pi GPIO connector.  The 40-pin socket connector is populated on the bottom of the board.
|J5

|8
|1x4 Socket: I2C Disp
|Connection for an I2C display panel for a Raspberry Pi through the GPIO connector.  This 4-pin socket connector is connected to the I2C-1 GPIO pins for use with a small OLED panel.
|J6

|9
|3 Pin Serial Data
|This 3-pin header row is labeled on the back of the board. It provides a logic-level serial connection to a μKOB for debugging.
|J9

|10
|6 Pin Serial Handshake
|This 6-pin header row is labeled on the back of the board. It provides a connection to the switch when used *ONLY* as a MRT Selector Switch.
|J8

|===

[%breakable]
=== Option Jumpers
[%unbreakable]
--
The option jumpers described in this section may or may not be configurable (via pins and jumpers) depending on how the interface board was assembled. It is possible that the options are hard-jumpered a specific way and cannot be changed. Unless noted, the option jumpers are either ON (jumpered) or OFF (open). Option jumper OP1 is the one 2-position option (left-right).

Going clockwise around the board, the option jumpers are:

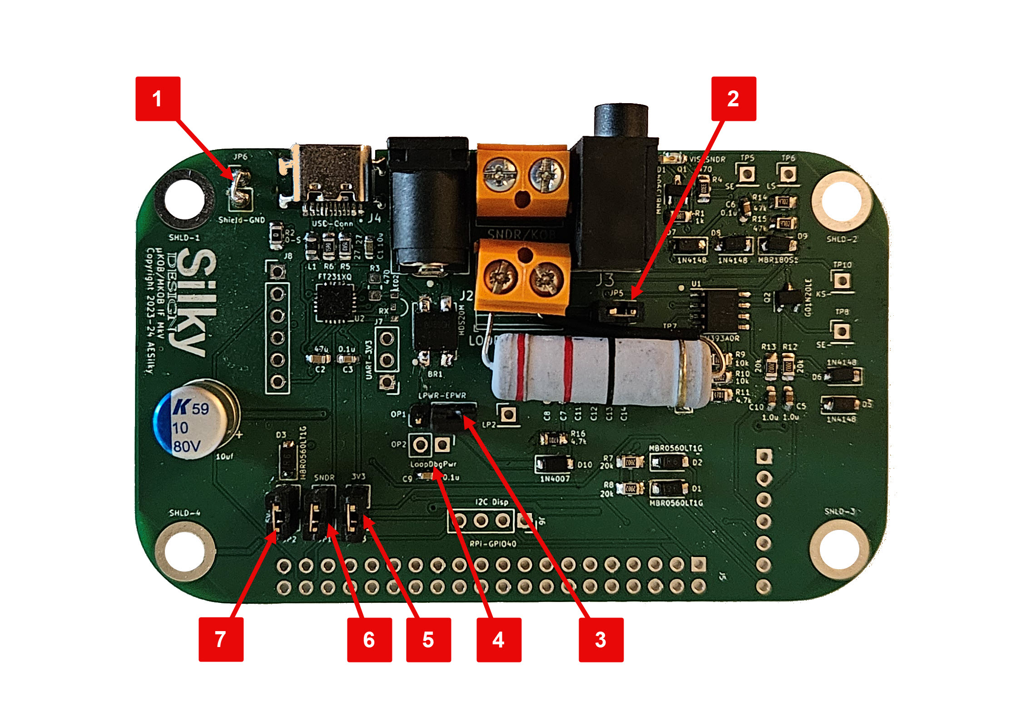
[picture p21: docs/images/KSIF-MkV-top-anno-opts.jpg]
Option Jumpers

--

.Interface Board Option Jumpers
[%breakable]
[width=98%]
[cols="^.<1,<.<3,<.<10,^.<3",options=header]
|===
|#
|Name
|Usage
|Schematic Designator

|1
|Shield-GND
|When jumpered, the shield (Altoids Tin) is connected to power/signal ground.
|JP6

|2
|SNBR EN
|When jumpered, the snubber circuit is connected to the Loop. The snubber circuit reduces electrical noise (radio interference) generated by driving the sounder.
|JP5

|3
|LPWR-EPWR
|This 2-position jumper selects how the Sounder / KOB Loop is powered. Selecting _LPWR_ (left) powers the Sounder/Loop from the _LOCAL_ (on-board) power connector (J2). Selecting _EPWR_ (right) configures the interface to allow the Sounder/Loop to be powered externally.
|OP1

|4
|LoopDbgPwr (*DEBUG ONLY*)
|When jumpered, power is supplied to the Sounder / KOB Loop circuit from the 5V board (logic) power.
|OP2

|5
|3V3
|When jumpered, 3.3 volt power to the board is supplied by the USB connection. When open, 3.3 volt power is supplied by the μKOB or GPIO.
|JP3

|6
|SNDR
|When jumpered, the sounder drive is from the USB (serial) RTS line. When open, the sounder drive is from the μKOB or GPIO.
|JP1

|7
|5V-USB
|When jumpered, 5 volt power to the board is supplied by the USB connection. When open, 5 volt power is supplied by the μKOB or GPIO.
|JP2

|NA
|KeyJack-NP
|This must be jumpered when the Key/Paddle Jack (J3) is not installed. The jumper and markings are located within the border of the jack.
|JP4

|NA
|TPn
|There are a number of _test points_ on the board. These are used for circuit test. See schematic for details.
|TP5-TP10

|===

[%nonfacing]
== Option Settings
Following are the option settings for the different applications of the interface board.

[%breakable]
=== Common
[%unbreakable]
--
The option jumper settings in this section are common to all applications of the interface board.
--

.Common Option Jumpers
[%breakable]
[width=98%]
[cols="^.<3,<.<5,<.<5",options=header]
|===
|Name / Designator
|Typical Setting
|Alternate Setting Use

|LPWR-EPWR / OP1
|LEFT = Local power supplied to the Sounder/Loop. RIGHT = Sounder/Loop is externally powered.
|Must be jumpered to left or right for the Sounder/Loop to operate.

|SNBR EN / JP5
|JUMPERED. Connects the snubber circuit to the Loop to reduce electrical noise (radio interference) generated by driving the sounder.
|Open to remove the snubber.

|LoopDbgPwr / OP2
|OPEN
|Jumper to provide 5 volt power to the loop circuit for board testing.

|Shield-GND / JP6
|JUMPERED. This connects the shield to the board's (electrical) ground.
|Open to isolate the shield from the board. When this is done, one of the shield screws can be used to attach an external ground for the shield.

|===

[%breakable]
=== μKOB (Configurations 1 and 2)
[%unbreakable]
--
In addition to the common option jumper settings, the following settings apply when the interface board is being attached to a μKOB via piggyback connector J1.(((μKOB, Attached, J1))) If the board is only being used with a μKOB, the board most likely does not have the ((USB interface)) populated. If that is the case, many of the jumpers in this section will also not be populated, and therefore will be OPEN.
--

[%unbreakable]
--
.μKOB Option Jumpers
[width=98%]
[cols="^.<3,<.<5,<.<5",options=header]
|===
|Name / Designator
|Setting
|Operation

|SNDR / JP1
|OPEN
|USB interface sounder drive signal is disconnected from the board.

|3V3 / JP3
|OPEN
|USB interface 3.3 volt source is disconnected from the board.

|5V-USB / JP2
|OPEN
|USB interface 5 volt source is disconnected from the board.

|RPI-GPIO40 / J5
|NON-EXISTENT
|A Raspberry Pi cannot be connected.

|I2C Disp / J6
|NON-EXISTENT
|The I2C is only connected to the GPIO connector for the Raspberry Pi.

|===
--

[%breakable]
=== Raspberry Pi GPIO (Configurations 3 and 4)
[%unbreakable]
--
In addition to the common option jumper settings, the following settings apply when the interface board is being attached to a Raspberry Pi via piggyback connector J5.(((Raspberry Pi, Attached, J5))) If the board is only being used with a Raspberry Pi, the board most likely does not have the ((USB interface)) populated. If that is the case, many of the jumpers in this section will also not be populated, and therefore will be OPEN.
--

.Raspberry Pi Option Jumpers
[%breakable]
[width=98%]
[cols="^.<3,<.<5,<.<5",options=header]
|===
|Name / Designator
|Setting
|Operation

|SNDR / JP1
|OPEN
|USB interface sounder drive signal is disconnected from the board.

|3V3 / JP3
|OPEN
|USB interface 3.3 volt source is disconnected from the board.

|5V-USB / JP2
|OPEN
|USB interface 5 volt source is disconnected from the board.

|I2C Disp / J6
|OPTIONAL
|Connects an I2C OLED Display panel to the Raspberry Pi GPIO (Pin1=GND, Pin2=3.3V/P1, Pin3=SCL/GP3/P5, Pin4=SDA/GP2/P3).

|μKOB / J1
|NON-EXISTENT
|A μKOB cannot be connected.

|===

[%breakable]
=== USB Serial (Configuration 5, plus 2 and 4)
[%unbreakable]
--
In addition to the common option jumper settings, the following settings apply when the interface board is being used through the USB Serial connection to a system running MKOB or MorseKOB. If the board is assembled for use only with the USB Serial interface, the options in this section are most likely permanently jumpered.
--

.USB Serial Option Jumpers
[%breakable]
[width=98%]
[cols="^.<3,<.<5,<.<5",options=header]
|===
|Name / Designator
|Setting
|Operation

|SNDR / JP1
|JUMPERED
|USB interface sounder drive signal is driving the board circuit.

|3V3 / JP3
|JUMPERED
|USB interface 3.3 volt source is powering the board.

|5V-USB / JP2
|JUMPERED
|USB interface 5 volt source is powering the board.

|μKOB / J1
|NO
|A μKOB cannot be connected.

|RPI-GPIO40 / J5
|NO
|A Raspberry Pi cannot be connected.

|===

[%nonfacing]
== Sounder / KOB Loop Connection
[%unbreakable]
--
A Sounder or a KOB Loop (key and sounder connected in series) are connected to the interface board using the screw-terminal block ST1. A user-supplied ((current limiting resistor))(((resistor, current limiting))) must be connected to screw-terminal block ST2. The resistor is positioned on the inside to reduce ((radio interference)) and to help guard against touching it, as it may become warm during operation.

Power for the sounder/loop is normally provided by a user-supplied power module connected via J2. Refer to the <<Externally Powered Loop>> section below if connecting to a powered telegraph loop.

Selecting the appropriate power module voltage and the current limiting resistor value depends on the sounder being used. The following table provides values that can be used as a starting point.

NOTE: The values in the table are meant to be used with this interface board and a Sounder or KOB for enjoying and practicing land-line telegraphy. They are not meant to indicate what was used in actual telegraph circuits _of the day_.

CAUTION: Some telegraphy enthusiasts use higher voltages and/or lower valued current limiting resistors to get a more _SNAPPY_ sound/response. Just remember that, in most cases, you are dealing with antique equipment that, if damaged, can be impossible to repair. If the sounder windings are over-powered long enough, or too many times, it can cause the (very thin) insulation coating the (extremely fine) wire to fail, causing an internal short. This results in the sounder becoming an interesting paper weight or conversation provoking door stop, rather than a functional telegraph instrument. It is suggested that you start with a lower voltage and/or higher resistor value. Then, if the sound produced isn't satisfactory, slightly increase the voltage *or* decrease the resistor value until a good, solid, *CLICK* is produced. Note that the *CLACK* is produced by the spring and other adjustments of the sounder, so voltage and resistance values don't really affect it.
--

[%unbreakable]
--
.Example Sounder / KOB Loop Voltage and Current Limit Resistor Values
[width=98%]
[cols="<.<10,<.<3,<.<3,^.<5,^.<5",options=header]
|===
|Instrument
|Nominal Current
|Voltage Drop
|Power Supply Voltage (J2)
|Current Limit Resistor Ohms (ST2)

|Line Sounder, 30 Ohms
|70 ma
|2.1v
|9v / 12v
|39 / 150 1W

|Line Sounder, 120 Ohms
|40 ma
|4.0v
|12v / 18v
|180 / 330 1W

|Local Sounder / KOB, 4 Ohms
|240 ma
|0.96v
|9v / 12v
|16 / 47 3W

|Local Sounder, 50 Ohms
|110 ma
|5.5v
|12v / 18v
|56 / 110 3W

|Local Sounder, 400 Ohms
|30 ma
|12v
|18v / 24v
|200 / 400 1W

|===
--

[%breakable]
=== Externally Powered Loop
The interface board is designed to make it easy to set up a personal telegraph station by providing a convenient way to provide power to the Sounder / KOB Loop. However, rather than powering the Sounder / KOB Loop from a power supply connected to J2, the interface board can be connected into a powered telegraph loop if the following conditions are met:

* The loop power must be DC
* The loop voltage must not exceed 80 volts (regardless of the amperage)
* The loop amperage must not exceed 1 amp (regardless of the voltage)
* The loop wattage must not exceed 3 watts (all sounders and other equipment in the loop energized)

If the existing telegraph loop has appropriate current limiting, the current limit resistor normally connected to ST2 can be replaced by a jumper wire. ST2 must have a resistor or a jumper wire in order to complete the loop circuit.

When connecting to a powered telegraph loop the LPWR-EPWR / OP1 jumper should be to the right (EPWR)(((External Power, EPWR))).

The interface board must be connected into the telegraph loop with the positive side of the loop circuit connected to the screw terminal nearer the J2 Power Jack (right side when viewing the face of the terminal block) and the negative side of the loop circuit connected to the screw terminal away from the J2 Power Jack (left when viewing the face of the terminal block). The interface board will introduce a 0.5 volt drop into the telegraph loop circuit.

[%nonfacing]
== Key/Paddle Input
[%unbreakable]
--
When using a separate key and sounder, or a paddle, the ((key)) or ((paddle))(((connecting, key or paddle))) is connected to the 1/8 inch (3.175 mm) phone jack ((J3)).

IMPORTANT: No power should be applied to this connection.

The connection is the same as many common HAM radios. It is illustrated below:
--

.Key/Paddle Connection
[%breakable]
[width=50%]
[cols="<.<1,<.<4"]
|===
|Tip
|Key or Paddle Dot

|Ring
|Paddle Dash

|Sleeve
|Common

|===

Key/Paddle Jack Connection

[%nonfacing]
== Connection Diagrams

.Separate Key and Sounder, powered through the interface
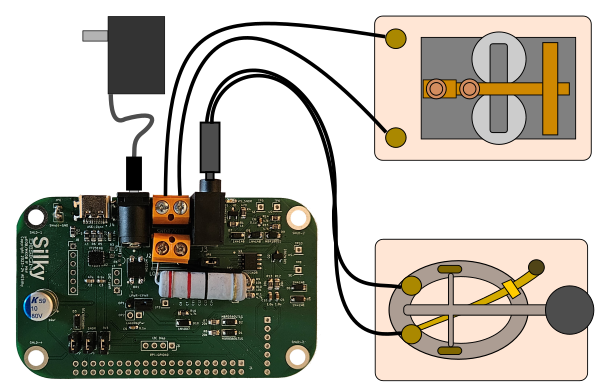
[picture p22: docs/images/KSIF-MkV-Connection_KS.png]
Key & Sounder


.Separate Key and Sounder with external power
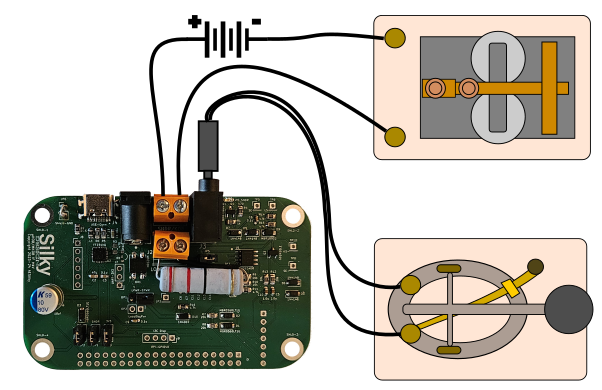
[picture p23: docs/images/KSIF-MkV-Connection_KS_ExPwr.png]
Key & Sounder with External Power


.KOB or Loop, powered through the interface
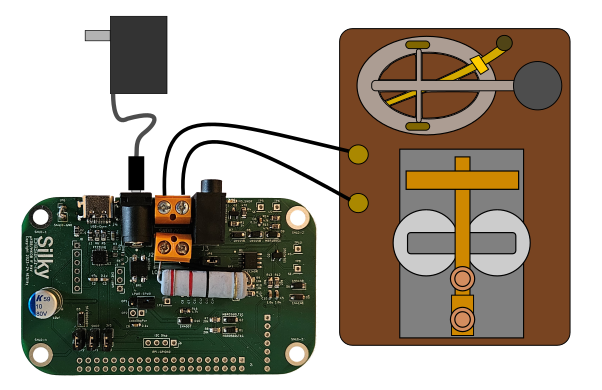
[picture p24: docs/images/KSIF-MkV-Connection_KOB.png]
KOB (Loop)


.KOB or Loop with external power
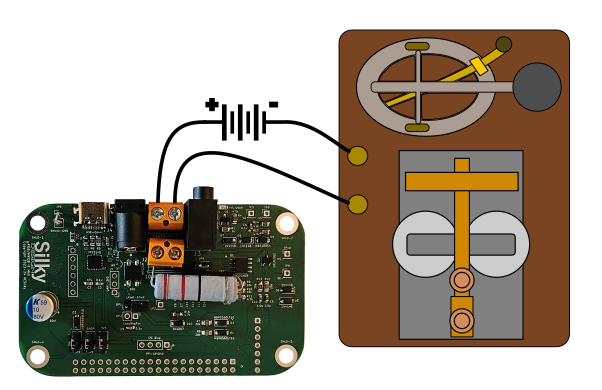
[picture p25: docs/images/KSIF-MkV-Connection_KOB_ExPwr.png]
KOB (Loop) with External Power


ifdef::backend-pdf[]
[index]
== Index
endif::[]

[colophon%nonfacing]
= Colophon
This document is for PCB: μKOB/MKOB IF MkV v1.0
--
Document version: {docver} ({docdate})
--

{license}

{copyright}

This document is authored using *asciidoc*, and the PDF version rendered through
*asciidoctor-pdf*.

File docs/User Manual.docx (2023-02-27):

# µKOB

# Introduction

µKOB (MuKOB) is a MorseKOB client developed for micro-controller operation. The initial version is targeted at the Raspberry Pi Pico W micro-controller with some specific peripherals connected. The Hardware section details the peripherals and connections. The combination of the micro-controller and peripherals will be referred to as ‘The Device’ or ‘The Unit’, or simply as ‘µKOB’ when the physical device/unit is implied.

µKOB can be operated using either the built-in display, with touch and rotary control, or a connected ANSI terminal (like PuTTY or similar terminal emulator). In fact, it can be operated from both simultaneously!

Refer to the sections for ‘Device Control’ and ‘Terminal Control’ for information about each method.

# General Operation

# Device Control

# Terminal Control

µKOB operates with a connected ANSI Terminal. It is tested with PuTTY, but other applications might work as well.

To enter a command or commands, type ‘:’ (colon). This pauses code display if you are currently connected to a wire and receiving code and displays a prompt at the bottom of the screen. µKOB is now in command mode and is waiting for your input. To exit command mode and return to displaying incoming code, press ‘ESC’.

## Commands

The following commands control µKOB operation and configuration. They are entered at the command prompt, which is entered by typing ‘:’ during normal operation.

Command | Description
w <wire number> | Set the wire to connect to.
c [wire number] | Connect to the currently selected wire. Optionally, specify the wire. If currently connected, disconnect.
s <speed> | Set the code speed.
S <Station ID> | Set the Station ID.
h | Help – lists commands with a short description.

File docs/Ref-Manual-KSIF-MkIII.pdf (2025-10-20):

# μKOB KS Interface MkIII

# Reference Manual

# Table of Contents

μKOB KS Interface MkIII

Silky Design - AES | Table of Contents | 1

2 | Preface | Silky Design - AES

# Introduction

This is the reference manual for the μKOB Key/Sounder/KOB/Paddle Interface MkIII. It is not intended as a tutorial, and it is not a user manual for the μKOB device. It describes the external device connections, the jumper settings, and how to use the test features of the interface board.

Silky Design - AES | Introduction | 3

# Preface

At a high level, the μKOB KS Interface (board) provides an interface between the μKOB main board and a KOB or a separate Key & Sounder. It is also capable of being used as a KOB/Key&Sounder interface for the MKOB application running on a Raspberry Pi through the GPIO connector,[1]
or for
the MKOB or MorseKOB application running on any system that supports an FTDI[2]
USB serial
port.

Depending on the intended application - μKOB, Raspberry Pi, or USB Serial - certain components may or may not, be populated. The possible options are:[3]

1. μKOB Only
2. μKOB + USB Serial
3. Raspberry Pi GPIO Only
4. Raspberry Pi + USB Serial
5. USB Serial Only

Following are sections that identify all of the connectors and option jumpers, setting the option jumpers for applications 1, 3, and 5 (2 and 4 can be deduced), connecting a KOB, a Key & Sounder, or a Paddle, including power options and current limit resistor. Finally, there is a section on using the test key/paddle & sounder portion of the board (when the real thing isn’t available, or isn’t practical).

This interface can be used with a KOB (KOB = Key On Board, a Sounder and Key connected in series, typically as a single unit on a base) or a separate key and sounder. The KOB, or a key and sounder connected in series, will sometimes be referred to as The Loop Circuit, The Loop, or simply, Loop.

When carrying a stand-alone interface board, it is suggested that you hold it by the bottom, edges, or shield rather than by the USB cable. Carrying it by the USB cable has a tendency to cause the micro-USB connector to part ways with the USB-Serial Module that it was assembled to, and you will be left holding a USB cable and connector and the interface board will be on the floor. You will then need to test your surface mount soldering, and possibly trace repair, skills.

[1] In this document the term the GPIO will be used to refer to the Raspberry Pi GPIO connector/connection.
[2] Future Technology Devices International (FTDI) is the manufacturer of the USB-Serial module used. The FTDI Virtual Serial Port driver is part of the Linux and MacOS kernel, and auto-installs on Windows.
[3] Since this interface board connects to μKOB and Raspberry Pi using a piggyback connector on the bottom of the board, it isn’t possible to assemble a board that can be used on both a μKOB and a Raspberry Pi.
4 | Preface | Silky Design - AES

# Connectors, Controls, and Option Jumpers

# Connectors and Controls

Going clockwise around the board, the connectors and controls are:


Table 1. Interface Board Connectors
# | Connector / Control | Usage | Schematic Designator

1 | Power Jack 2x5.5mm: Sounder/Loop Power | This barrel connector is a typical size for wall wart and small inline power supplies in the 9v-24v range that can be used to power the sounder or KOB loop. The center pin is positive. This input is reverse polarity protected. Refer to the Sounder / KOB Loop Connection section for suggestions on selecting a power source. | J2
Silky Design - AES | Connectors, Controls, and Option Jumpers | 5

# | Connector / Control | Usage | Schematic Designator

2 | 2pos Screw Terminal (inward facing): Sounder Current Limit | Used to connect a current limiting resistor for the sounder or KOB loop power. Refer to the Sounder / KOB Loop Connection section for suggestions on selecting an appropriate resistor value. | ST1
3 | 2pos Screw Terminal: Sounder/KOB | The connection to the Sounder/KOB. This is The Loop. Refer to the Sounder / KOB Loop Connection section for notes about connecting to a loop that is externally powered. | ST2
4 | 2pos Switch: Mini Sounder & Visual Sounder Enable | Pos-1 (left) enables the Visual Sounder Indicator. Pos-2 (right) enables the Mini Sounder. Down enables the feature, up disables the feature. | SW4
5 | USB (Micro-B): Serial interface and logic power | Serial connection to a host running MKOB or MorseKOB. This is also used to supply power to the logic portion of the interface board when being used stand-alone. IMPORTANT: If the interface board is attached to a μKOB or a Raspberry Pi, refer to the Option Jumpers section before connecting to this USB connector. | U1
6 | 1/4in Stereo (TRS): Key/Paddle | Key/Paddle input for use with a separate Key & Sounder. Refer to the Key/Paddle Input section for connection details. | J3
7 | Toggle Switch: Test Closer | The key closer for the mini-test key portion. Lever to the left (toward the pushbutton switches) is CLOSED, to the right is OPEN. | SW1
8 | Pushbutton Switch: Test Paddle-Dash (Dah) | The Dash sender of the mini-test paddle. | SW3
9 | Pushbutton Switch: Test Key / Paddle-Dot (Dit) | The mini-test key, or the Dot sender of the mini-test paddle. | SW2
6 | Connectors, Controls, and Option Jumpers | Silky Design - AES

# | Connector / Control | Usage | Schematic Designator

10 | 1x4 Socket: I2C Disp | Connection for an I2C display panel for a Raspberry Pi through the GPIO connector. This 4-pin socket connector is connected to the I2C-1 GPIO pins for use with a small OLED panel. | J6
11 | 2x20 Socket: GPIO | Connection to a Raspberry Pi GPIO connector. The 40-pin socket connector is populated on the bottom of the board. | J5
12 | 2x5 Header: Serial I/O | 10-pin header for the serial port I/O signals. This can connect to a DB9 ribbon cable or to a piggyback’ed μKOB Comm Adaptor board. | J4
13 | 1x7 Socket: μKOB | Connection to a μKOB main board. The 7-pin socket connector is populated on the bottom of the board. | J1
NA | 7 Pin x 2 Rows on USB-Serial Module | The two 7-pin header rows on the USB-Serial Module connect the module to the interface board. They are not intended to be used, and must not be jumpered. The signals are labeled on the interface board, and can be used for testing if needed. | U1
Silky Design - AES | Connectors, Controls, and Option Jumpers | 7

# Option Jumpers

The option jumpers described in this section may or may not be configurable (via pins and jumpers) depending on how the interface board was assembled. It is possible that the options are hard-jumpered a specific way and cannot be changed. Unless noted, the option jumpers are either ON (jumpered) or OFF (open). Option jumper OP1 is the one 2-position option (left-right).

Going clockwise around the board, the option jumpers are:


Table 2. Interface Board Option Jumpers
# | Name | Usage | Schematic Designator

1 | 5V-USB | When jumpered, 5 volt power to the board is supplied by the USB connection. When open, 5 volt power is supplied by the μKOB or GPIO. | JP8
2 | LoopDbgPwr | When jumpered, power is supplied to the Sounder / KOB Loop circuit from the 5V board (logic) power. | OPa1
3 | SNDR | When jumpered, the sounder drive is from the USB (serial) RTS line. When open, the sounder drive is from the μKOB or GPIO. | JP4
8 | Connectors, Controls, and Option Jumpers | Silky Design - AES

# | Name | Usage | Schematic Designator

4 | DASH- | When jumpered, the paddle dash signal is sent to the USB (serial) CTS line. When open, the paddle dash signal is sent to the μKOB or GPIO. | JP5
5 | DOT- | When jumpered, the key / paddle dot signal is sent to the USB (serial) DSR line. When open, the key / paddle dot signal is sent to the μKOB or GPIO. | JP6
6 | 3V3 | When jumpered, 3.3 volt power to the board is supplied by the USB connection. When open, 3.3 volt power is supplied by the μKOB or GPIO. | JP7
7 | KeyJack-NP | This must be jumpered when the Key/Paddle Jack (J3) is not installed. The jumper and markings are located within the border of the jack. | JP1
8 | KEY-IN | When jumpered, the key / paddle dot signal is connected to the interface board. When open, the signal is not connected, allowing the mini-test key function to be used. | JP3
9 | DASH-IN | When jumpered, the paddle dash signal is connected to the interface board. When open, the signal is not connected, allowing the mini-test key function to be used. | JP2
10 | KS-LOOP | This 2-position jumper selects how the mini-test key and sounder are connected. When the jumper is to the KS side, the mini-test is connected as a separate key & sounder. When the jumper is to the LOOP side, the mini-test is connected as a loop (key and sounder in series). The paddle-dash is always separate, and when testing as a paddle the jumper should be in the KS position. | OP1
11 | JP9 | When jumpered, the shield (Altoids can) is connected to power/signal ground. | JP9
Silky Design - AES | Connectors, Controls, and Option Jumpers | 9

# Option Settings

Following are the option settings for the different applications of the interface board.

# Common

The option jumper settings in this section are common to all applications of the interface board.

Table 3. Common Option Jumpers
Name / Designator | Typical Setting | Alternate Setting Use
LoopDbgPwr / OPa1 | OPEN | Jumper to provide 5 volt power to the loop circuit for board testing.
KEY-IN / JP3 | JUMPERED | Open to use the on-board test key and closer when the external key can’t be left open.
DASH-IN / JP2 | JUMPERED | Open to use the on-board test paddle if the external paddle can’t be left open.
KS-LOOP / OP1 | LEFT = Key&Sounder / RIGHT = Loop Configuration of the on-board test key and sounder. | Must be jumpered to left or right for the on-board test sounder (visual or mini) to operate.
JP9 | JUMPERED. This connects the shield to the board’s (electrical) ground. | Open to isolate the shield from the board. When this is done, one of the shield screws can be used to attach an external ground for the shield.

# μKOB (Configurations 1 and 2)

In addition to the common option jumper settings, the following settings apply when the interface board is being attached to a μKOB via piggyback connector J1. If the board is only being used with a μKOB, the board most likely does not have the FTDI USB-Serial Module (U1) populated. If that is the case, many of the jumpers in this section will also not be populated, and therefore will be OPEN.

10 | Option Settings | Silky Design - AES

Table 4. μKOB Option Jumpers
Name / Designator | Setting | Operation
SNDR / JP4 | OPEN | USB interface sounder drive signal is disconnected from the board.
DASH- / JP5 | OPEN | USB interface dash input is disconnected from the board.
DOT- / JP6 | OPEN | USB interface dot input is disconnected from the board.
3V3 / JP7 | OPEN | USB interface 3.3 volt source is disconnected from the board.
5V-USB / JP8 | OPEN | USB interface 5 volt source is disconnected from the board.
RPI-GPIO40 / J5 | NON-EXISTENT | A Raspberry Pi cannot be connected.

# Raspberry Pi GPIO (Configurations 3 and 4)

In addition to the common option jumper settings, the following settings apply when the interface board is being attached to a Raspberry Pi via piggyback connector J5. If the board is only being used with a Raspberry Pi, the board most likely does not have the FTDI USB-Serial Module (U1) populated. If that is the case, many of the jumpers in this section will also not be populated, and therefore will be OPEN.

Table 5. Raspberry Pi Option Jumpers
Name / Designator | Setting | Operation
SNDR / JP4 | OPEN | USB interface sounder drive signal is disconnected from the board.
DASH- / JP5 | OPEN | USB interface dash input is disconnected from the board.
DOT- / JP6 | OPEN | USB interface dot input is disconnected from the board.
3V3 / JP7 | OPEN | USB interface 3.3 volt source is disconnected from the board.
5V-USB / JP8 | OPEN | USB interface 5 volt source is disconnected from the board.
Silky Design - AES | Option Settings | 11

Name / Designator | Setting | Operation
I2C Disp / J6 | OPTIONAL | Connects an I2C OLED Display panel to the Raspberry Pi GPIO (Pin1=GND, Pin2=3.3V/P1, Pin3=SCL/GP3/P5, Pin4=SDA/GP2/P3).
μKOB / J1 | NON-EXISTENT | A μKOB cannot be connected.

# USB Serial (Configuration 5, plus 2 and 4)

In addition to the common option jumper settings, the following settings apply when the interface board is being used through the USB Serial connection to a system running MKOB or MorseKOB. If the board is assembled for use only with the USB Serial interface, the options in this section are most likely permanently jumpered.

Table 6. USB Serial Option Jumpers
Name / Designator | Setting | Operation
SNDR / JP4 | JUMPERED | USB interface sounder drive signal is driving the board circuit.
DASH- / JP5 | JUMPERED | USB interface dash input is from the board circuit.
DOT- / JP6 | JUMPERED | USB interface dot input is from the board circuit.
3V3 / JP7 | JUMPERED | USB interface 3.3 volt source is powering the board.
5V-USB / JP8 | JUMPERED | USB interface 5 volt source is powering the board.
μKOB / J1 | NO | A μKOB cannot be connected.
RPI-GPIO40 / J5 | NO | A Raspberry Pi cannot be connected.
12 | Option Settings | Silky Design - AES

# Sounder / KOB Loop Connection

A Sounder or a KOB Loop (key and sounder connected in series) are connected to the interface board using the screw-terminal block ST2. A user-supplied current limiting resistor must be connected to screw-terminal block ST1. The resistor is positioned on the inside (under the shield) to reduce radio interference and to help guard against touching it, as it may become warm during operation.

Power for the sounder/loop is normally provided by a user-supplied power module connected via J2. Refer to the Externally Powered Loop section below if connecting to a powered telegraph loop.

Selecting the appropriate power module voltage and the current limiting resistor value depends on the sounder being used. The following table provides values that can be used as a starting point.

The values in the table are meant to be used with this interface board and a Sounder or KOB for enjoying and practicing land-line telegraphy. They are not meant to indicate what was used in actual telegraph circuits of the day.

Some telegraphy enthusiasts use higher voltages and/or lower valued current limiting resistors to get a more SNAPPY sound/response. Just remember that, in most cases, you are dealing with antique equipment that, if damaged, can be impossible to repair. If the sounder windings are over-powered long enough, or too many times, it can cause the (very thin) insulation coating the (extremely fine) wire to fail, causing an internal short. This results in the sounder becoming an interesting paper weight or conversation provoking door stop, rather than a functional telegraph instrument. It is suggested that you start with a lower voltage and/or higher resistor value. Then, if the sound produced isn’t satisfactory, slightly increase the voltage or decrease the resistor value until a good, solid, CLICK is produced. Note that the CLACK is produced by the spring and other adjustments of the sounder, so voltage and resistance values don’t really affect it.

Silky Design - AES | Sounder / KOB Loop Connection | 13

Table 7. Example Sounder / KOB Loop Voltage and Current Limit Resistor Values
Instrument | Nominal Current | Voltage Drop | Power Supply Voltage (J2) | Current Limit Resistor Ohms (ST1)
Line Sounder, 30 Ohms | 70 ma | 2.1v | 9v / 12v | 39 / 150 1W
Line Sounder, 120 Ohms | 40 ma | 4.0v | 12v / 18v | 180 / 330 1W
Local Sounder / KOB, 4 Ohms | 240 ma | 0.96v | 9v / 12v | 16 / 47 3W
Local Sounder, 50 Ohms | 110 ma | 5.5v | 12v / 18v | 56 / 110 3W
Local Sounder, 400 Ohms | 30 ma | 12v | 18v / 24v | 200 / 400 1W

# Externally Powered Loop

The interface board is designed to make it easy to set up a personal telegraph station by providing a convenient way to provide power to the Sounder / KOB Loop. However, rather than powering the Sounder / KOB Loop from a power supply connected to J2, the interface board can be connected into a powered telegraph loop if the following conditions are met:

- The loop power must be DC
- The loop voltage must not exceed 30 volts (regardless of the amperage)
- The loop amperage must not exceed 1 amp (regardless of the voltage)
- The loop wattage must not exceed 1.8 watts (all sounders and other equipment in the loop energized)

If the existing telegraph loop has appropriate current limiting, the current limit resistor normally connected to ST1 can be replaced by a jumper wire. ST1 must have a resistor or a jumper wire in order to complete the loop circuit.

When connecting to a powered telegraph loop the J2 power connector must be jumpered. This can be accomplished using a shorting connector.

The interface board must be connected into the telegraph loop with the negative side of the loop circuit connected to the screw terminal nearer the J2 Power Jack (right side when viewing the face of the terminal block) and the positive side of the loop circuit connected to the screw terminal away from the J2 Power Jack (left when viewing the face of the terminal block). The interface board will introduce a 1.5 volt drop into the telegraph loop circuit.

14 | Sounder / KOB Loop Connection | Silky Design - AES

# Key/Paddle Input

When using a separate key and sounder, or a paddle, the key or paddle is connected to the 1/4 inch phone jack J3.

- No power should be applied to this connection.

The connection is the same as many common HAM radios. It is illustrated below:

Table 8. Key/Paddle Connection

Tip | Key or Paddle Dot
Ring | Paddle Dash
Sleeve | Common

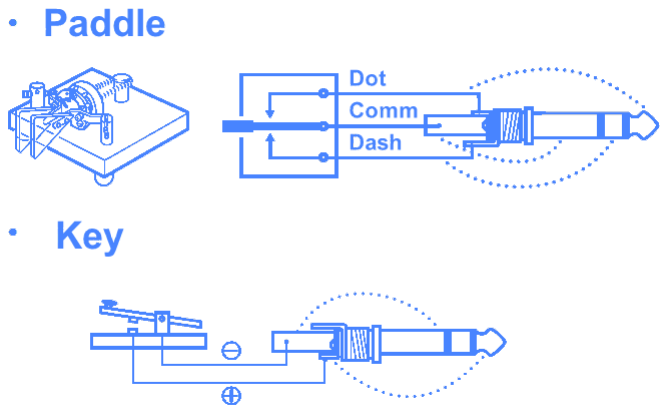
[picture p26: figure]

Silky Design - AES | Key/Paddle Input | 15

# Connection Diagrams

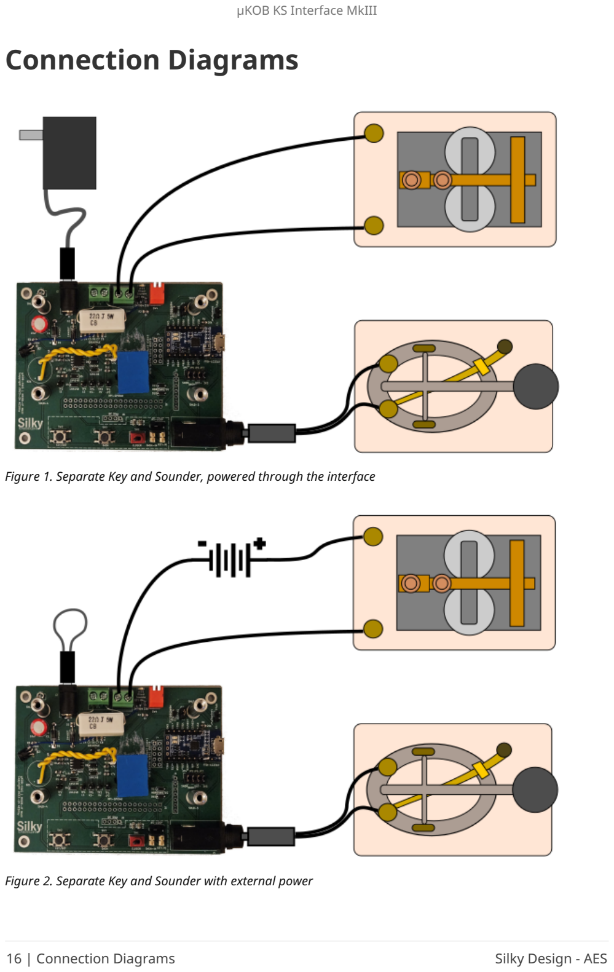
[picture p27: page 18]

Figure 1. Separate Key and Sounder, powered through the interface

Figure 2. Separate Key and Sounder with external power

16 | Connection Diagrams | Silky Design - AES

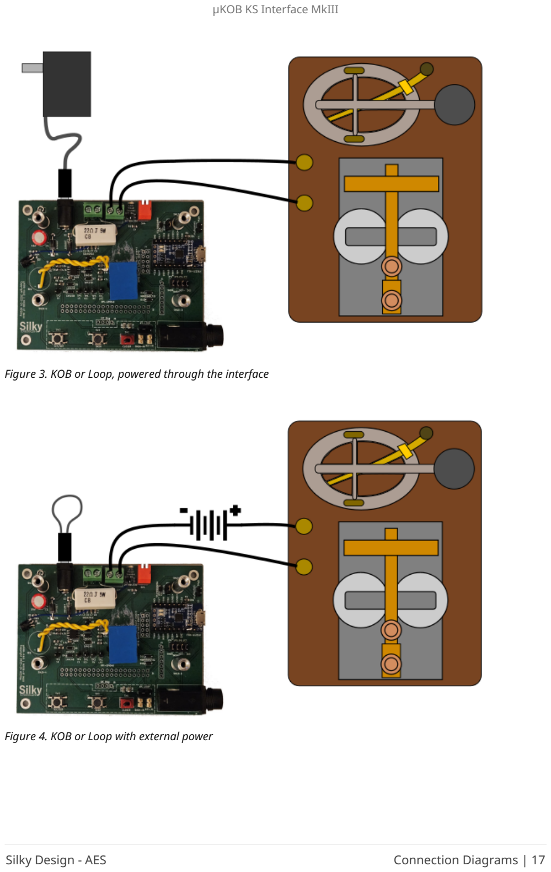
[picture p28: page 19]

Figure 3. KOB or Loop, powered through the interface

Figure 4. KOB or Loop with external power

Silky Design - AES | Connection Diagrams | 17

# Optional Test Key/Paddle and Visual/Mini Sounder

For testing μKOB or MKOB it can be handy to have a small, self-contained device that includes a key and sounder. This interface board optionally provides a Visual Sounder, a Mini Sounder, and a Key with Closer switch, and a Paddle-Dash switch. The Visual Sounder and Mini Sounder can be enabled/disabled individually using the 2-position DIP-Switch (SW4). The test features do not require the Sounder/Loop power (J2), the Sounder Current Limit resistor (ST1), or a Sounder/KOB (ST2).

To use the key+closer when an external key is attached, the JP2 jumper can be removed or the external key can be left open. Normally, nothing special needs to be done to use the Paddle Switches, as a paddle doesn’t close the circuit when it’s not being used.

Option Jumper OP1 configures the test key+closer and visual sounder and mini sounder as either a separate key and sounder or a loop circuit. This configuration only affects the test key and sounder, it does not change the external circuit.

Technically, the test key/paddle, visual sounder, and mini sounder are in parallel with the actual, external, telegraph equipment. Therefore, when using the actual telegraph equipment the test closer, if installed, must be open in order for the telegraph key’s operation to be recognized.

# Adjusting Tone

The Mini Sounder tone can be adjusted by tightening or loosening the screws that hold down the shield tin.

18 | Optional Test Key/Paddle and Visual/Mini Sounder | Silky Design - AES

# Index

C
closer, 18
connecting
key or paddle, 15
current limiting resistor, 13

D
DIP-Switch, 18
2-position, 18

F
FTDI USB-Serial Module (U1, 10-11

G
GPIO, 4
Raspberry Pi, 4

J
J3, 15
JP2, 18

K
key, 15, 18
Key & Sounder, 4
separate, 4
KOB, 4
Key On Board, 4
loop power, 6

L
Loop
Loop Circuit, 4
loop, 18

M
Mini Sounder, 18
MKOB, 4
MorseKOB, 4

O
Option Jumper, 18
OP1, 18

P
paddle, 15
Paddle Switches, 18
Paddle-Dash, 18
piggyback, 4

R
radio interference, 13
Raspberry Pi, 4
Attached
J5, 11
resistor
current limiting, 13

S
separate key and sounder, 18 shield tin, 18
Altoids, 18
stand-alone, 4, 6

T
tone, 18

U
USB Serial, 4

V
Visual Sounder, 18

Μ
μKOB, 4
Attached
J1, 10
μKOB KS Interface, 4
Silky Design - AES | Index | 19

# Colophon

This document is for PCB: μKOB-K&S | MKOB-IF MkIII v1.0 with Cv2 mods

Document version: 1.1 (20240506)

MIT License

Copyright (c) 2023-24 AESilky

This document is authored using asciidoc, and the pdf version rendered through asciidoctor-pdf, to create a manual that is more readable and more pleasing to the eye.

20 | Colophon | Silky Design - AES

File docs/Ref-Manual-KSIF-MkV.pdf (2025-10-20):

# μKOB KS Interface MkV

# Reference Manual

# Table of Contents

μKOB KS Interface MkIII

Silky Design - AES | Table of Contents | 1

2 | Preface | Silky Design - AES

# Introduction

This is the reference manual for the μKOB Key/Sounder/KOB/Paddle Interface MkV. It is not intended as a tutorial, and it is not a user manual for the μKOB device. It describes the external device connections to, and jumper settings of, the interface board.


Silky Design - AES | Introduction | 3

# Preface

At a high level, the μKOB KS Interface (board) provides an interface between the μKOB main board and a KOB or a separate Key & Sounder. It is also capable of being used as a KOB/Key&Sounder interface for the MKOB application running on a Raspberry Pi through the GPIO connector,[1]
or for
the MKOB or MorseKOB application running on any system that supports a FTDI[2]
USB serial port.

Depending on the intended application - μKOB, Raspberry Pi, or USB Serial - certain components may or may not, be populated. The possible options are:[3]

1. μKOB Only
2. μKOB + USB Serial
3. Raspberry Pi GPIO Only
4. Raspberry Pi + USB Serial
5. USB Serial Only

Following are sections that identify all of the connectors and option jumpers, setting the option jumpers for applications 1, 3, and 5 (2 and 4 can be deduced), connecting a KOB, a Key & Sounder, or a Paddle, including power options and current limit resistor.

This interface can be used with a KOB (KOB = Key On Board, a Sounder and Key connected in series, typically as a single unit on a base) or a separate key and sounder. Within this document, a KOB or a key and sounder connected in series, will sometimes be referred to as The Loop Circuit, The Loop, or simply, Loop.

[1] In this document the term the GPIO will be used to refer to the Raspberry Pi GPIO connector/connection.
[2] Future Technology Devices International (FTDI) is the manufacturer of the USB-Serial device used. The FTDI Virtual Serial Port driver is part of the Linux and MacOS kernel, and auto-installs on Windows.
[3] Since this interface board connects to μKOB and Raspberry Pi using a piggyback connector on the bottom of the board, it isn’t possible to assemble a board that can be used on both a μKOB and a Raspberry Pi.
4 | Preface | Silky Design - AES

# MKOB Suite Auto-Detect (USB Serial)

When using a single interface connected via the USB Serial and the MKOB Suite of applications (MKOB, MRT, Telegram, and the utilities), the configuration (preferences) can be set to auto-detect the interface. Using Configure (or the Preferences in MKOB) set the Serial Port value to SDIF (Silky Design Interface). The value must by typed in manually. With the serial port set to SDIF, the application will search for the interface and once found it will automatically be used.

If more than one Silky Design interface is connected, the first interface found will be used.

Silky Design - AES | MKOB Suite Auto-Detect (USB Serial) | 5

6 | MKOB Suite Auto-Detect (USB Serial) | Silky Design - AES

# Connectors, Controls, and Option Jumpers

# Connectors and Controls

Going clockwise around the board, the connectors are:


Table 1. Interface Board Connectors
# | Connector / Control | Usage | Schematic Designator

1 | USB (USB-C): Serial interface and logic power | Serial connection to a host running MKOB or MorseKOB. This is also used to supply power to the logic portion of the interface board when being used stand-alone. IMPORTANT: If the interface board is attached to a μKOB or a Raspberry Pi, refer to the Option Jumpers section, and DO NOT CONNECT to this USB connector. | J4
Silky Design - AES | Connectors, Controls, and Option Jumpers | 7

# | Connector / Control | Usage | Schematic Designator

2 | Power Jack 2x5.5mm: Sounder/Loop Power | This barrel connector is a typical size for wall wart and small inline power supplies in the 9v-24v range that can be used to power the sounder or KOB loop. Typically the center pin is positive, but either polarity will work. Refer to the Sounder / KOB Loop Connection section for suggestions on selecting a power source. | J2
3 | 2pos Screw Terminal: Sounder/KOB | The connection to the Sounder/KOB. This is The Loop. Refer to the Sounder / KOB Loop Connection section for notes about connecting to a loop that is externally powered. | ST1
4 | 2pos Screw Terminal (inward facing): Sounder Current Limit | Used to connect a current limiting resistor for the sounder or KOB loop power. Refer to the Sounder / KOB Loop Connection section for suggestions on selecting an appropriate resistor value. | ST2
5 | 1/8" Stereo (TRS): Key/Paddle | Key/Paddle input for use with a separate Key & Sounder. Refer to the Key/Paddle Input section for connection details. | J3
6 | 1x7 Socket: μKOB | Connection to a μKOB main board. The 7-pin socket connector is populated on the bottom of the board. | J1
7 | 2x20 Socket: GPIO | Connection to a Raspberry Pi GPIO connector. The 40-pin socket connector is populated on the bottom of the board. | J5
8 | 1x4 Socket: I2C Disp | Connection for an I2C display panel for a Raspberry Pi through the GPIO connector. This 4-pin socket connector is connected to the I2C-1 GPIO pins for use with a small OLED panel. | J6
9 | 3 Pin Serial Data | This 3-pin header row is labeled on the back of the board. It provides a logic-level serial connection to a μKOB for debugging. | J9
10 | 6 Pin Serial Handshake | This 6-pin header row is labeled on the back of the board. It provides a connection to the switch when used ONLY as a MRT Selector Switch. | J8
8 | Connectors, Controls, and Option Jumpers | Silky Design - AES

# Option Jumpers

The option jumpers described in this section may or may not be configurable (via pins and jumpers) depending on how the interface board was assembled. It is possible that the options are hard-jumpered a specific way and cannot be changed. Unless noted, the option jumpers are either ON (jumpered) or OFF (open). Option jumper OP1 is the one 2-position option (left-right).

Going clockwise around the board, the option jumpers are:


Table 2. Interface Board Option Jumpers
# | Name | Usage | Schematic Designator

1 | Shield-GND | When jumpered, the shield (Altoids Tin) is connected to power/signal ground. | JP6
2 | SNBR EN | When jumpered, the snubber circuit is connected to the Loop. The snubber circuit reduces electrical noise (radio interference) generated by driving the sounder. | JP5
Silky Design - AES | Connectors, Controls, and Option Jumpers | 9

# | Name | Usage | Schematic Designator

3 | LPWR-EPWR | This 2-position jumper selects how the Sounder / KOB Loop is powered. Selecting LPWR (left) powers the Sounder/Loop from the LOCAL (on-board) power connector (J2). Selecting EPWR (right) configures the interface to allow the Sounder/Loop to be powered externally. | OP1
4 | LoopDbgPwr (DEBUG ONLY) | When jumpered, power is supplied to the Sounder / KOB Loop circuit from the 5V board (logic) power. | OP2
5 | 3V3 | When jumpered, 3.3 volt power to the board is supplied by the USB connection. When open, 3.3 volt power is supplied by the μKOB or GPIO. | JP3
6 | SNDR | When jumpered, the sounder drive is from the USB (serial) RTS line. When open, the sounder drive is from the μKOB or GPIO. | JP1
7 | 5V-USB | When jumpered, 5 volt power to the board is supplied by the USB connection. When open, 5 volt power is supplied by the μKOB or GPIO. | JP2
NA | KeyJack-NP | This must be jumpered when the Key/Paddle Jack (J3) is not installed. The jumper and markings are located within the border of the jack. | JP4
NA | TPn | There are a number of test points on the board. These are used for circuit test. See schematic for details. | TP5-TP10
10 | Connectors, Controls, and Option Jumpers | Silky Design - AES

# Option Settings

Following are the option settings for the different applications of the interface board.

# Common

The option jumper settings in this section are common to all applications of the interface board.

Table 3. Common Option Jumpers
Name / Designator | Typical Setting | Alternate Setting Use
LPWR-EPWR / OP1 | LEFT = Local power supplied to the Sounder/Loop. RIGHT = Sounder/Loop is externally powered. | Must be jumpered to left or right for the Sounder/Loop to operate.
SNBR EN / JP5 | JUMPERED. Connects the snubber circuit to the Loop to reduce electrical noise (radio interference) generated by driving the sounder. | Open to remove the snubber.
LoopDbgPwr / OP2 | OPEN | Jumper to provide 5 volt power to the loop circuit for board testing.
Shield-GND / JP6 | JUMPERED. This connects the shield to the board’s (electrical) ground. | Open to isolate the shield from the board. When this is done, one of the shield screws can be used to attach an external ground for the shield.

# μKOB (Configurations 1 and 2)

In addition to the common option jumper settings, the following settings apply when the interface board is being attached to a μKOB via piggyback connector J1. If the board is only being used with a μKOB, the board most likely does not have the USB interface populated. If that is the case, many of the jumpers in this section will also not be populated, and therefore will be OPEN.

Silky Design - AES | Option Settings | 11

Table 4. μKOB Option Jumpers
Name / Designator | Setting | Operation
SNDR / JP1 | OPEN | USB interface sounder drive signal is disconnected from the board.
3V3 / JP3 | OPEN | USB interface 3.3 volt source is disconnected from the board.
5V-USB / JP2 | OPEN | USB interface 5 volt source is disconnected from the board.
RPI-GPIO40 / J5 | NON-EXISTENT | A Raspberry Pi cannot be connected.
I2C Disp / J6 | NON-EXISTENT | The I2C is only connected to the GPIO connector for the Raspberry Pi.

# Raspberry Pi GPIO (Configurations 3 and 4)

In addition to the common option jumper settings, the following settings apply when the interface board is being attached to a Raspberry Pi via piggyback connector J5. If the board is only being used with a Raspberry Pi, the board most likely does not have the USB interface populated. If that is the case, many of the jumpers in this section will also not be populated, and therefore will be OPEN.

Table 5. Raspberry Pi Option Jumpers
Name / Designator | Setting | Operation
SNDR / JP1 | OPEN | USB interface sounder drive signal is disconnected from the board.
3V3 / JP3 | OPEN | USB interface 3.3 volt source is disconnected from the board.
5V-USB / JP2 | OPEN | USB interface 5 volt source is disconnected from the board.
I2C Disp / J6 | OPTIONAL | Connects an I2C OLED Display panel to the Raspberry Pi GPIO (Pin1=GND, Pin2=3.3V/P1, Pin3=SCL/GP3/P5, Pin4=SDA/GP2/P3).
μKOB / J1 | NON-EXISTENT | A μKOB cannot be connected.
12 | Option Settings | Silky Design - AES

# USB Serial (Configuration 5, plus 2 and 4)

In addition to the common option jumper settings, the following settings apply when the interface board is being used through the USB Serial connection to a system running MKOB or MorseKOB. If the board is assembled for use only with the USB Serial interface, the options in this section are most likely permanently jumpered.

Table 6. USB Serial Option Jumpers
Name / Designator | Setting | Operation
SNDR / JP1 | JUMPERED | USB interface sounder drive signal is driving the board circuit.
3V3 / JP3 | JUMPERED | USB interface 3.3 volt source is powering the board.
5V-USB / JP2 | JUMPERED | USB interface 5 volt source is powering the board.
μKOB / J1 | NO | A μKOB cannot be connected.
RPI-GPIO40 / J5 | NO | A Raspberry Pi cannot be connected.
Silky Design - AES | Option Settings | 13

# Sounder / KOB Loop Connection

A Sounder or a KOB Loop (key and sounder connected in series) are connected to the interface board using the screw-terminal block ST1. A user-supplied current limiting resistor must be connected to screw-terminal block ST2. The resistor is positioned on the inside to reduce radio interference and to help guard against touching it, as it may become warm during operation.

Power for the sounder/loop is normally provided by a user-supplied power module connected via J2. Refer to the Externally Powered Loop section below if connecting to a powered telegraph loop.

Selecting the appropriate power module voltage and the current limiting resistor value depends on the sounder being used. The following table provides values that can be used as a starting point.

The values in the table are meant to be used with this interface board and a Sounder or KOB for enjoying and practicing land-line telegraphy. They are not meant to indicate what was used in actual telegraph circuits of the day.

Some telegraphy enthusiasts use higher voltages and/or lower valued current limiting resistors to get a more SNAPPY sound/response. Just remember that, in most cases, you are dealing with antique equipment that, if damaged, can be impossible to repair. If the sounder windings are over-powered long enough, or too many times, it can cause the (very thin) insulation coating the (extremely fine) wire to fail, causing an internal short. This results in the sounder becoming an interesting paper weight or conversation provoking door stop, rather than a functional telegraph instrument. It is suggested that you start with a lower voltage and/or higher resistor value. Then, if the sound produced isn’t satisfactory, slightly increase the voltage or decrease the resistor value until a good, solid, CLICK is produced. Note that the CLACK is produced by the spring and other adjustments of the sounder, so voltage and resistance values don’t really affect it.

14 | Sounder / KOB Loop Connection | Silky Design - AES

Table 7. Example Sounder / KOB Loop Voltage and Current Limit Resistor Values
Instrument | Nominal Current | Voltage Drop | Power Supply Voltage (J2) | Current Limit Resistor Ohms (ST2)
Line Sounder, 30 Ohms | 70 ma | 2.1v | 9v / 12v | 39 / 150 1W
Line Sounder, 120 Ohms | 40 ma | 4.0v | 12v / 18v | 180 / 330 1W
Local Sounder / KOB, 4 Ohms | 240 ma | 0.96v | 9v / 12v | 16 / 47 3W
Local Sounder, 50 Ohms | 110 ma | 5.5v | 12v / 18v | 56 / 110 3W
Local Sounder, 400 Ohms | 30 ma | 12v | 18v / 24v | 200 / 400 1W

# Externally Powered Loop

The interface board is designed to make it easy to set up a personal telegraph station by providing a convenient way to provide power to the Sounder / KOB Loop. However, rather than powering the Sounder / KOB Loop from a power supply connected to J2, the interface board can be connected into a powered telegraph loop if the following conditions are met:

- The loop power must be DC
- The loop voltage must not exceed 80 volts (regardless of the amperage)
- The loop amperage must not exceed 1 amp (regardless of the voltage)
- The loop wattage must not exceed 3 watts (all sounders and other equipment in the loop energized)

If the existing telegraph loop has appropriate current limiting, the current limit resistor normally connected to ST2 can be replaced by a jumper wire. ST2 must have a resistor or a jumper wire in order to complete the loop circuit.

When connecting to a powered telegraph loop the LPWR-EPWR / OP1 jumper should be to the right (EPWR).

The interface board must be connected into the telegraph loop with the positive side of the loop circuit connected to the screw terminal nearer the J2 Power Jack (right side when viewing the face of the terminal block) and the negative side of the loop circuit connected to the screw terminal away from the J2 Power Jack (left when viewing the face of the terminal block). The interface board will introduce a 0.5 volt drop into the telegraph loop circuit.

Silky Design - AES | Sounder / KOB Loop Connection | 15

# Key/Paddle Input

When using a separate key and sounder, or a paddle, the key or paddle is connected to the 1/8 inch (3.175 mm) phone jack J3.

- No power should be applied to this connection.

The connection is the same as many common HAM radios. It is illustrated below:

Table 8. Key/Paddle Connection

Tip | Key or Paddle Dot
Ring | Paddle Dash
Sleeve | Common


16 | Key/Paddle Input | Silky Design - AES

# Connection Diagrams

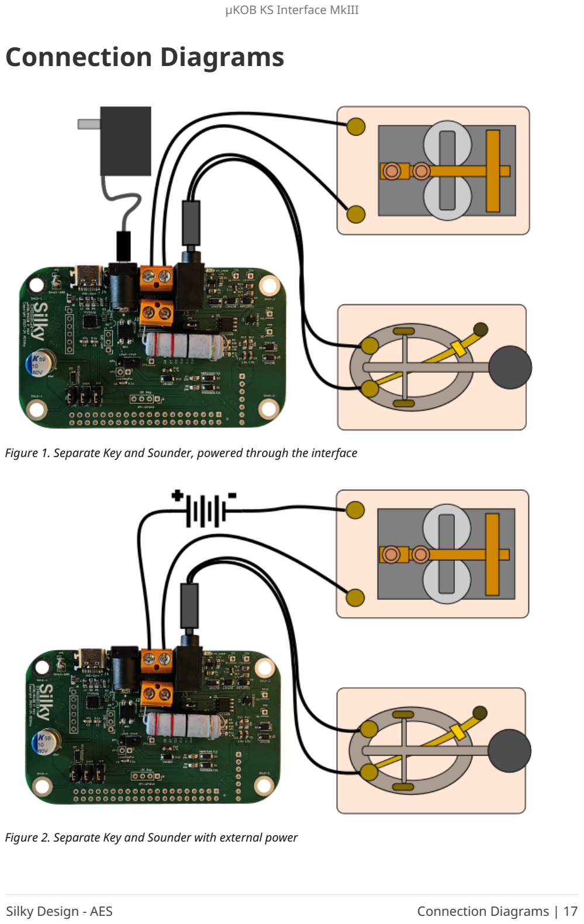
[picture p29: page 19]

Figure 1. Separate Key and Sounder, powered through the interface

Figure 2. Separate Key and Sounder with external power

Silky Design - AES | Connection Diagrams | 17

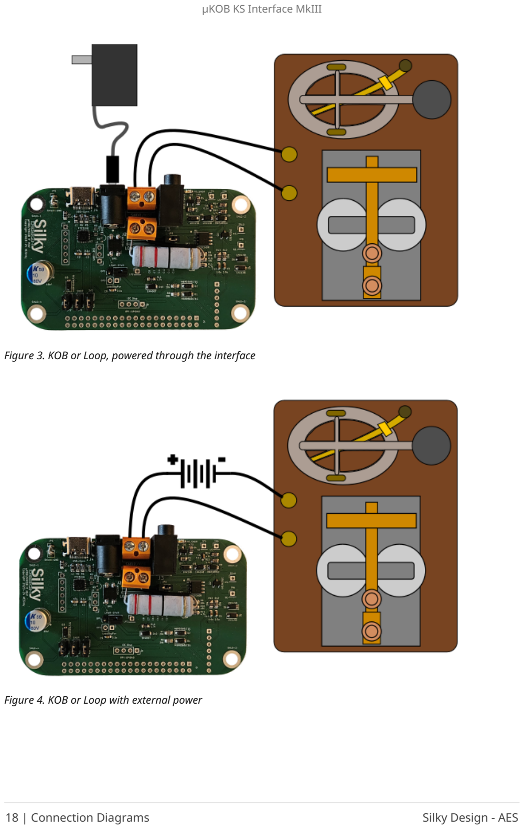
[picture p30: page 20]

Figure 3. KOB or Loop, powered through the interface

Figure 4. KOB or Loop with external power

18 | Connection Diagrams | Silky Design - AES

# Index

C
connecting
key or paddle, 16
current limiting resistor, 14

E
External Power
EPWR, 15

G
GPIO, 4
Raspberry Pi, 4

J
J3, 16

K
key, 16
Key & Sounder, 4
separate, 4
KOB, 4
Key On Board, 4
loop power, 8

L
Loop
Loop Circuit, 4

M
MKOB, 4
MorseKOB, 4

P
paddle, 16
piggyback, 4

R
radio interference, 14

Raspberry Pi, 4
Attached
J5, 12
resistor
current limiting, 14

S
SDIF
Silky Design Interface, 5
stand-alone, 7

U
USB interface, 11-12
USB Serial, 4

Μ
μKOB, 4
Attached
J1, 11
μKOB KS Interface, 4
Silky Design - AES | Index | 19

# Colophon

This document is for PCB: μKOB/MKOB IF MkV v1.0

Document version: 1.0 (20240821)

MIT License

Copyright (c) 2023-24 AESilky

This document is authored using asciidoc, and the PDF version rendered through asciidoctor-pdf.

20 | Colophon | Silky Design - AES

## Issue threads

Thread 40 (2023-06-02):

Wifi machine/client name should be "MuKOB..."

AESilky, 2023-06-02:
Currently, the device shows up as "picow". Use "MuKOB" and the board ID to register the device with a more meaningful name. Also, using the board ID will allow multiple MuKOB devices to register with unique names.

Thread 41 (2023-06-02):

Provide software update mechanism

AESilky, 2023-06-02:
The device will need to be updated with bug fixes and new features. Although it will be possible to update it by booting with the bootsel button pressed and then copying the updated `.uf2` file onto the device, that process is not intuitive or easy for an average (non-developer) user to perform.

Look at 'src/rp2_common/pico_bootrom' and other SDK functionality to see if there is a more user-friendly way to perform an update.

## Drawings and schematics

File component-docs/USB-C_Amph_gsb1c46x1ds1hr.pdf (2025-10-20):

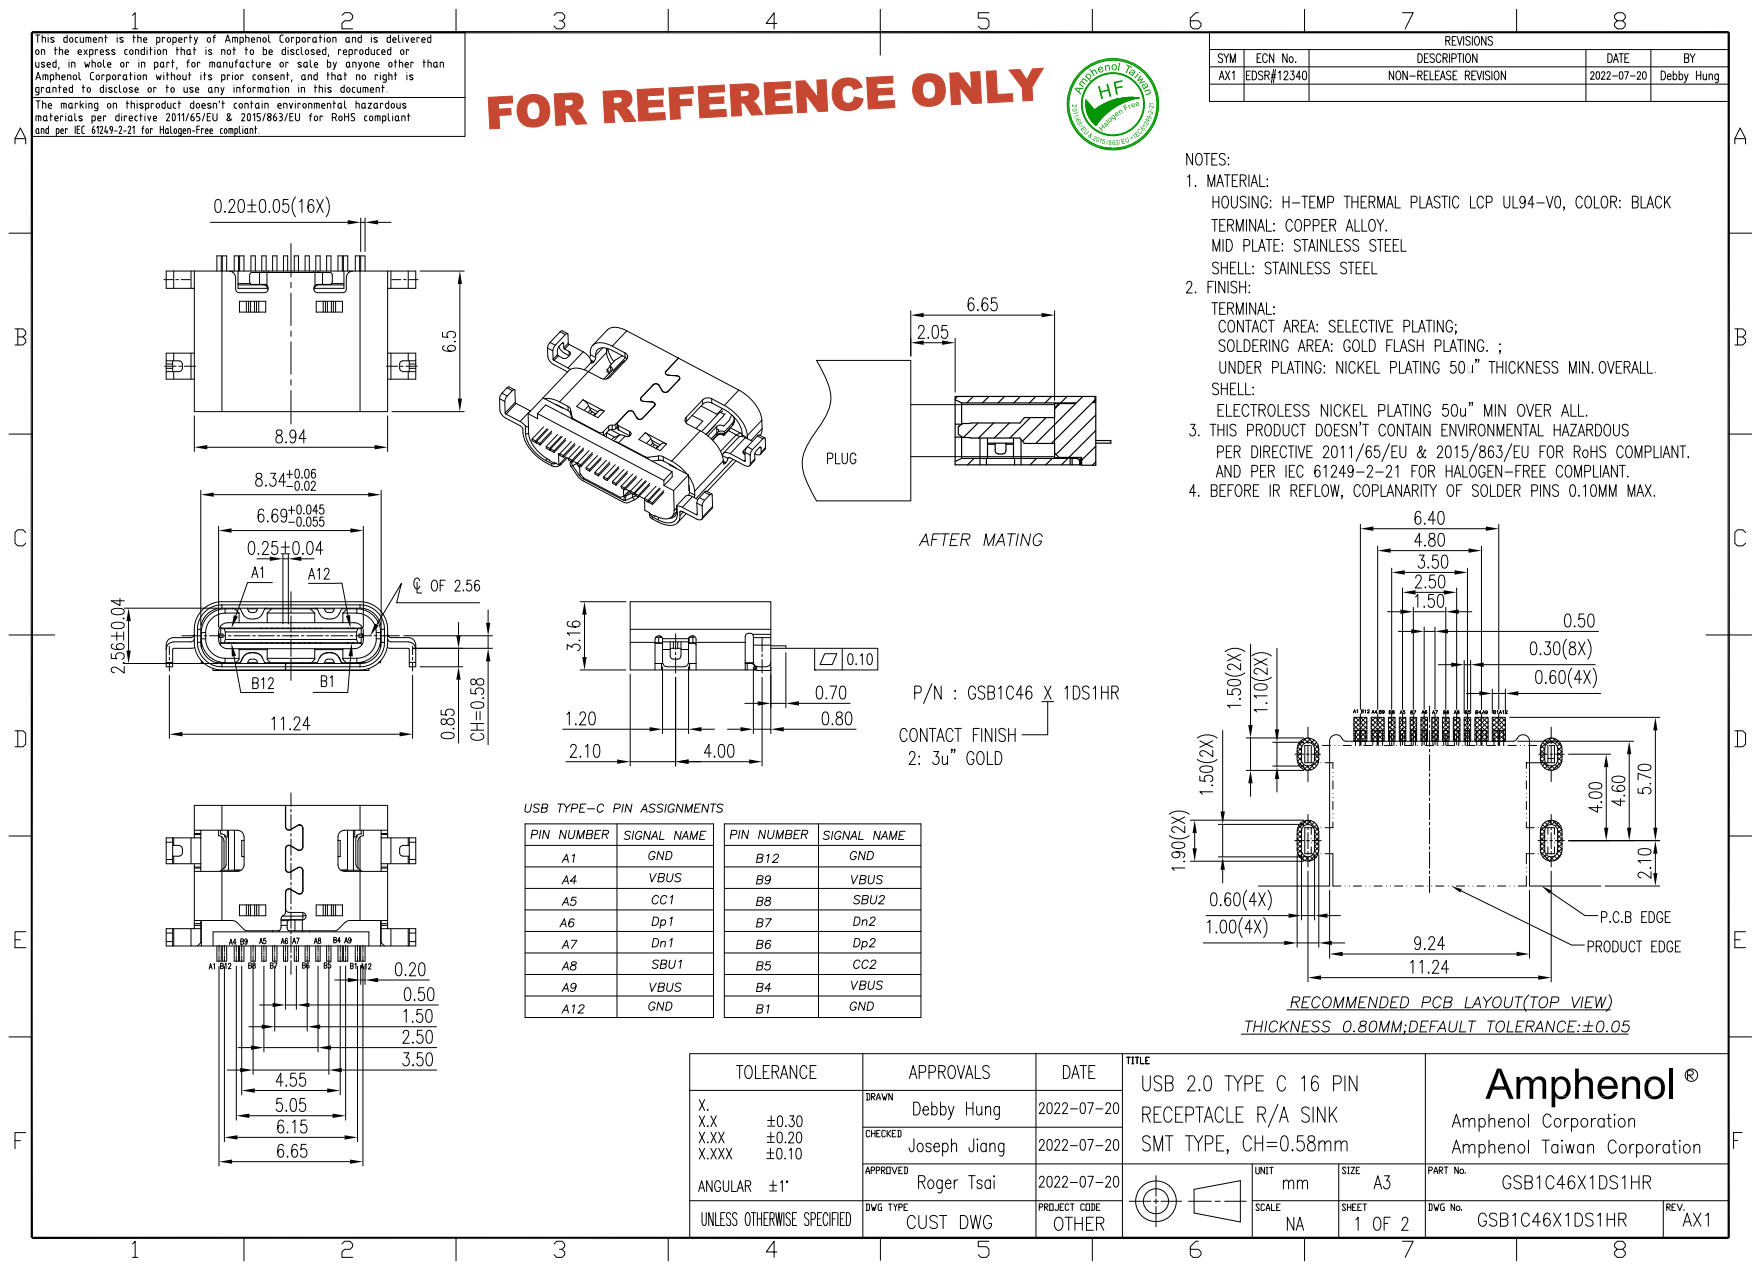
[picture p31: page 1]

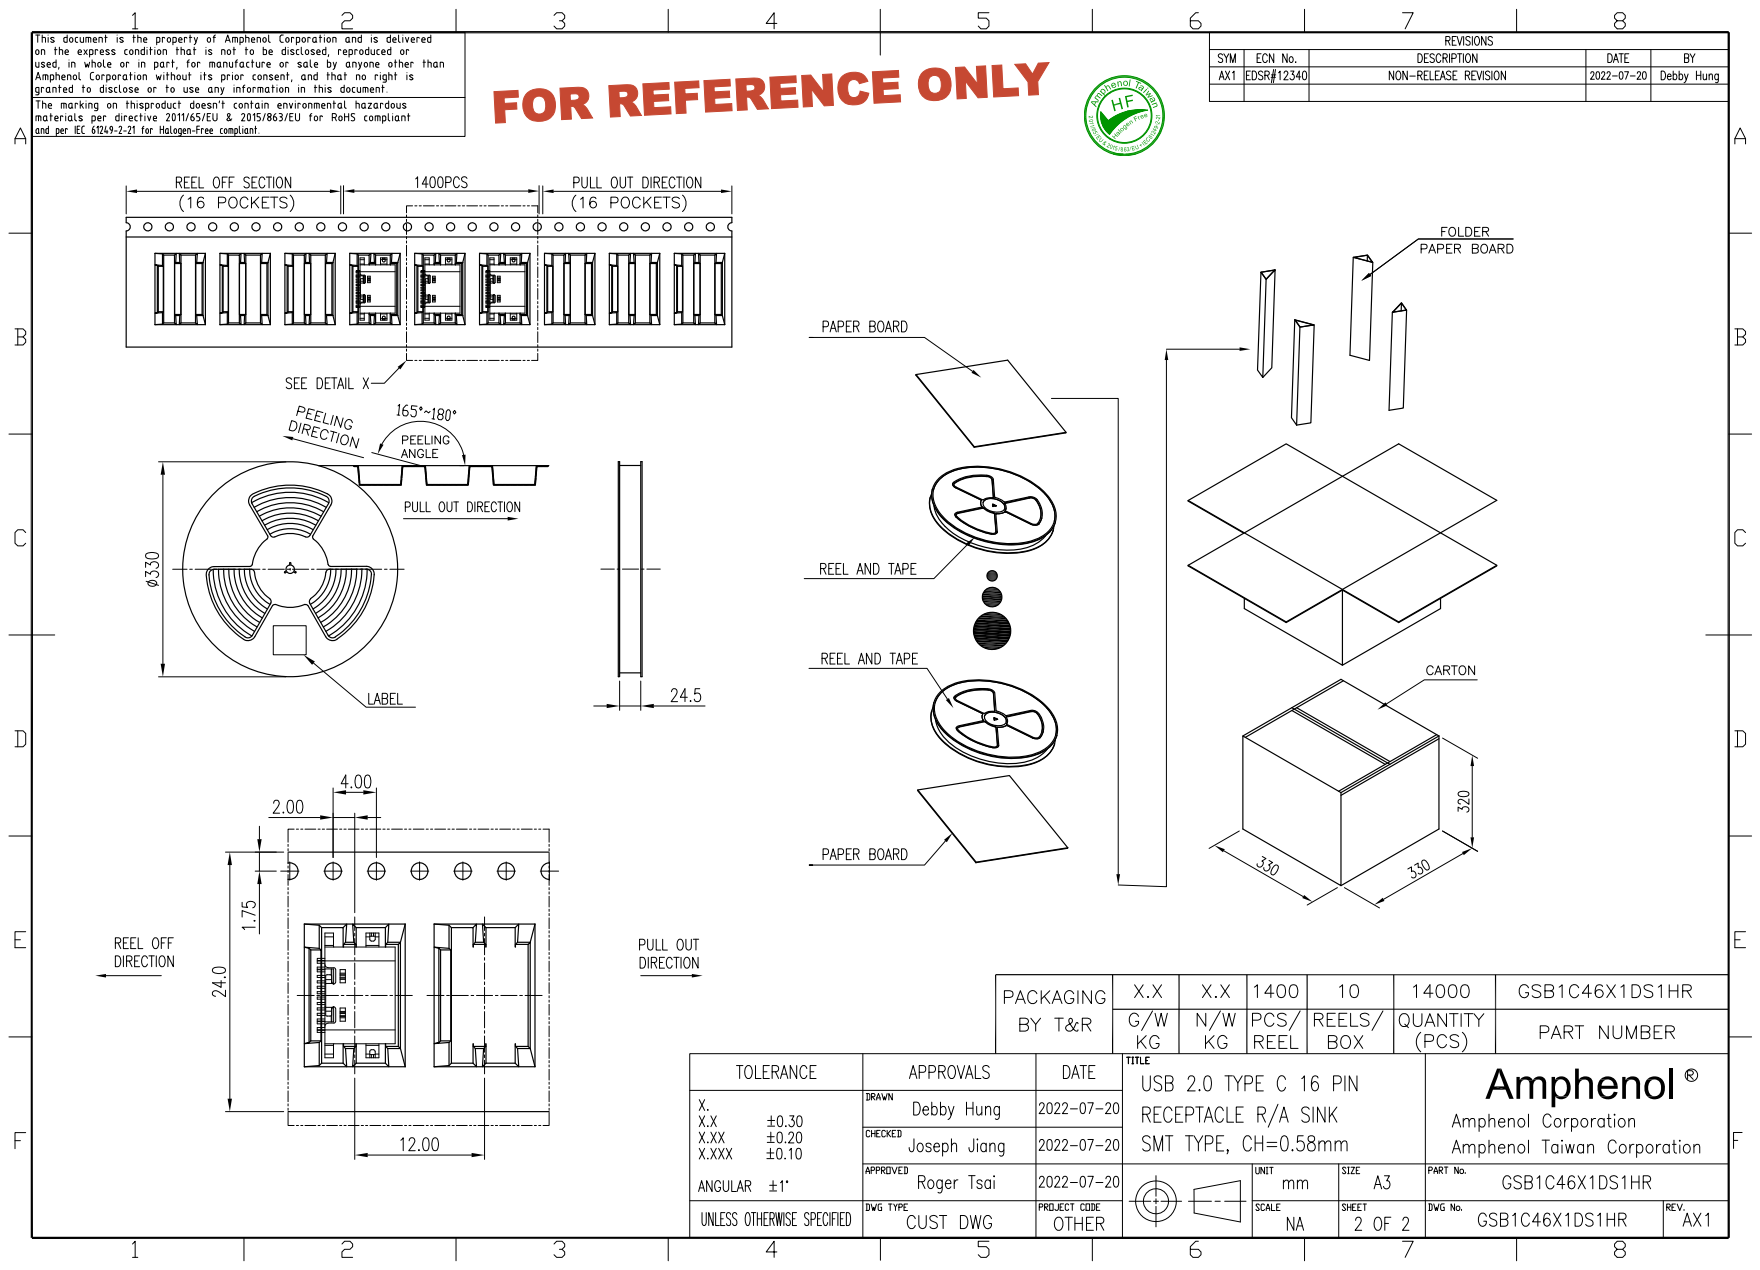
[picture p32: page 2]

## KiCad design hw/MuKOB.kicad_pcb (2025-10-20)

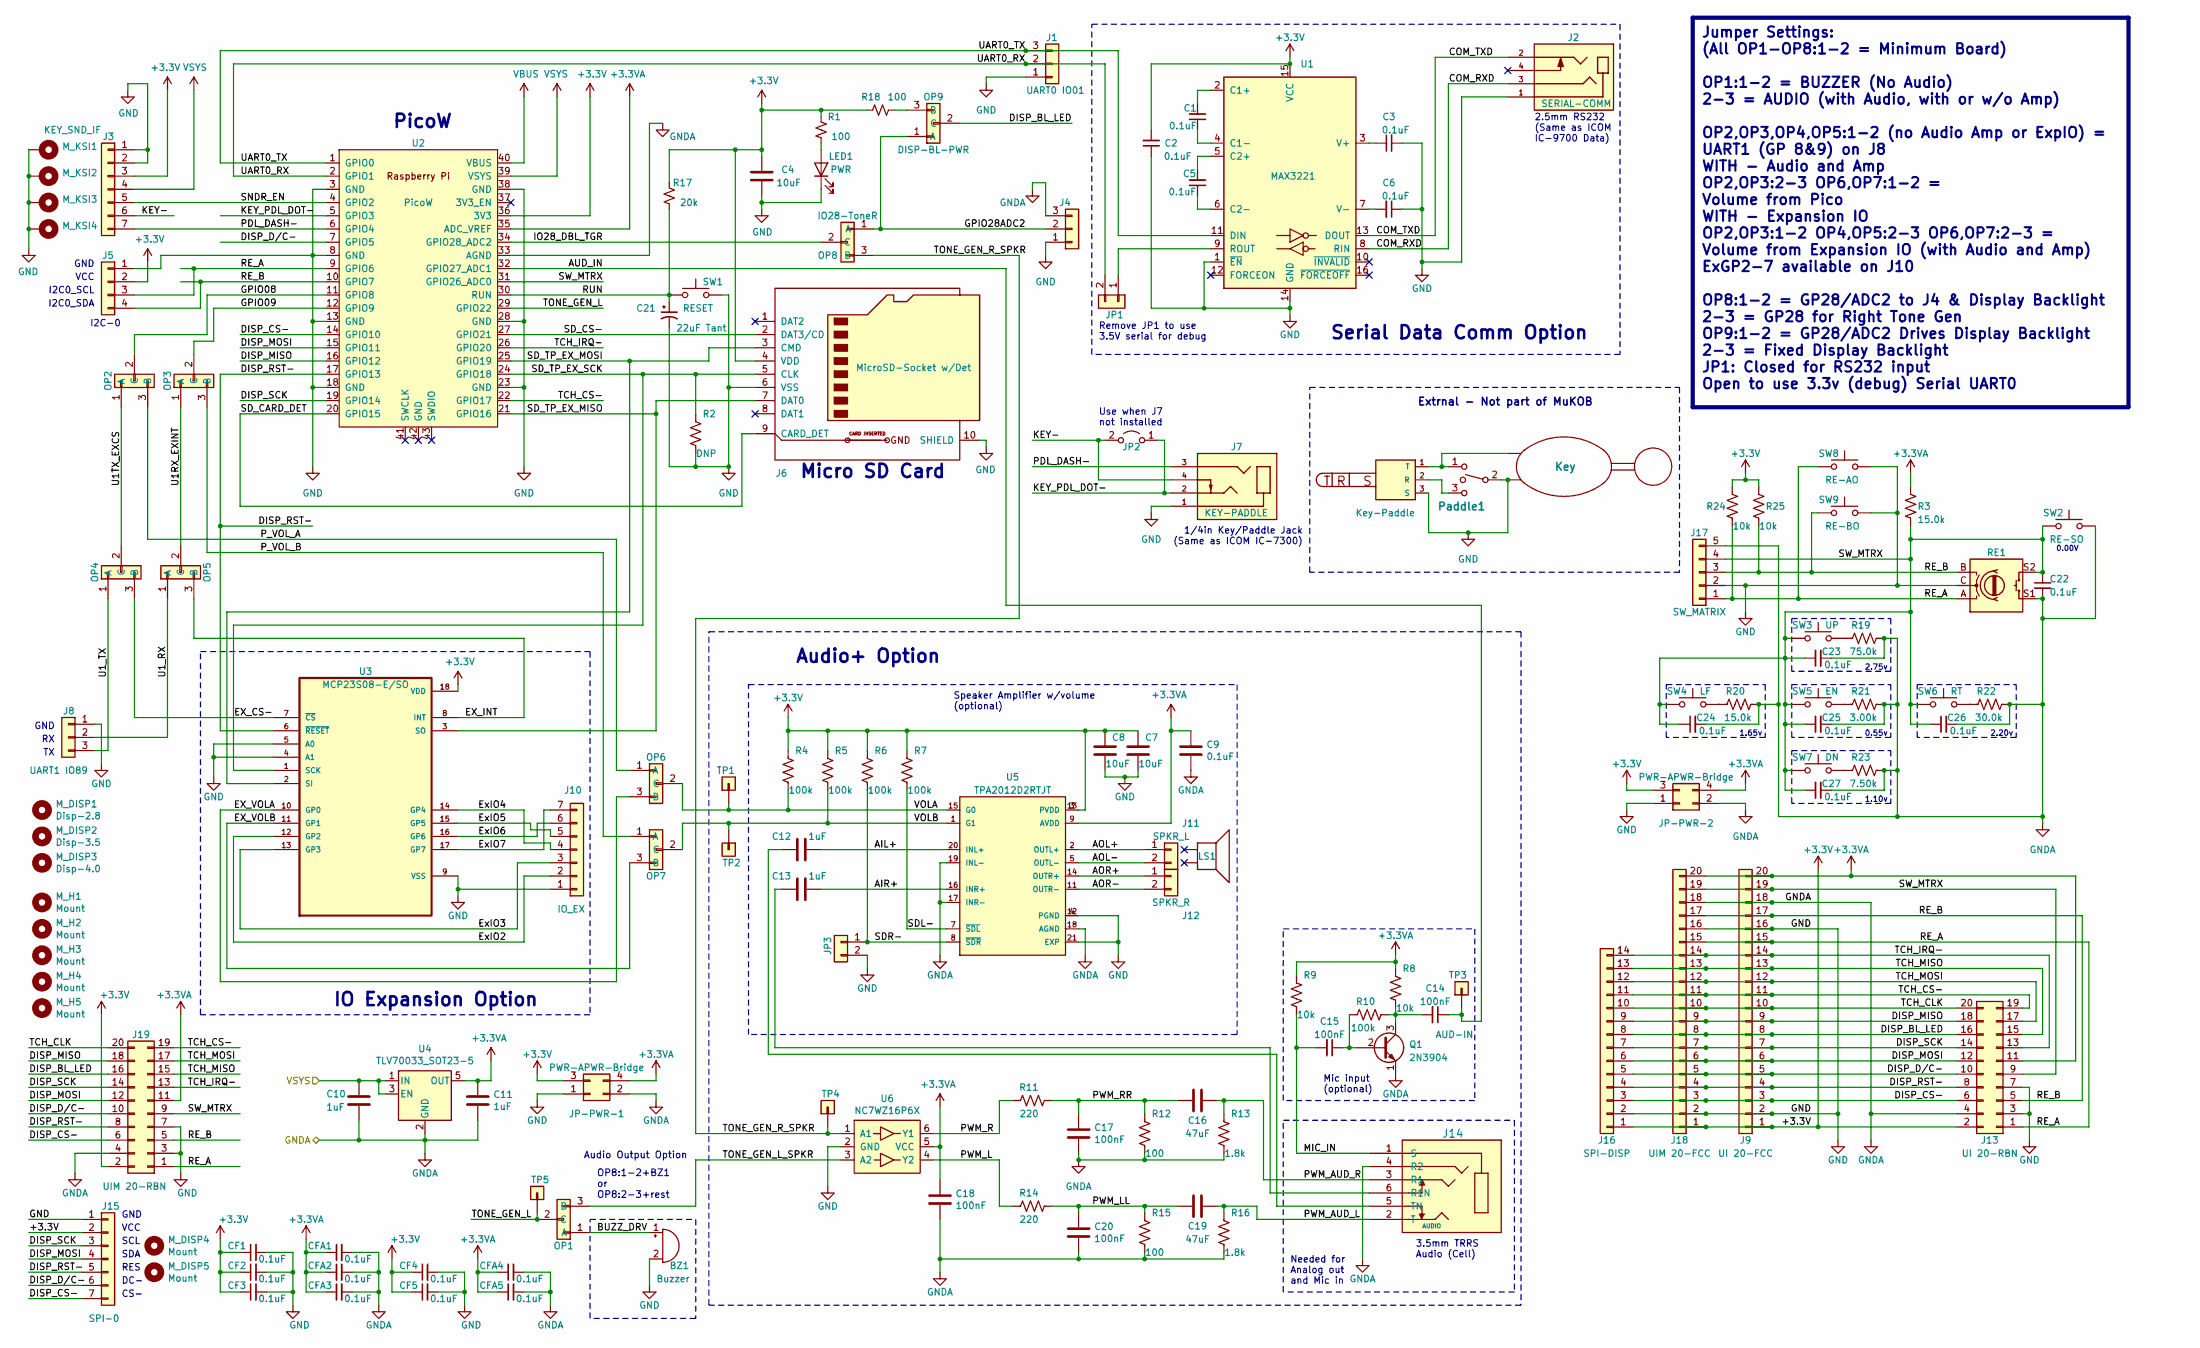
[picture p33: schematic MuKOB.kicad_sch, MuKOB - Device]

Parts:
BZ1: Buzzer; Buzzer_12x9.5RM7.6
C1, C2, C3, C5, C6, C9, C22, C23, C24, C25, C26, C27: 0.1uF; C_0603_1608Metric_Pad1.08x0.95mm_HandSolder
C4, C7, C8: 10uF; C_0603_1608Metric
C10, C11, C12, C13: 1uF; C_0201_0603Metric_Pad0.64x0.40mm_HandSolder
C14, C15, C17, C18, C20: 100nF; C_0201_0603Metric_Pad0.64x0.40mm_HandSolder
C16, C19: 47uF; C_1206_3216Metric_Pad1.33x1.80mm_HandSolder
C21: 22uF Tant; CP_EIA-3528-15_AVX-H_Pad1.50x2.35mm_HandSolder
CF1, CF2, CF3, CF4, CF5: 0.1uF; C_Axial_L3.8mm_D2.6mm_P7.50mm_Horizontal
CFA1, CFA2, CFA3, CFA4, CFA5: 0.1uF; C_Axial_L3.8mm_D2.6mm_P7.50mm_Horizontal
J1: UART0 IO01; PinHeader_1x03_P2.54mm_Vertical
J2: SERIAL-COMM; CUI_SJ-2524-SMT-TRS-audio-jack; PARTREV 1.05
J3: KEY_SND_IF; PinSocket_1x07_P2.54mm_Vertical
J4: GPIO28; PinHeader_1x03_P2.54mm_Vertical
J5: I2C-0; PinSocket_1x04_P2.54mm_Vertical
J6: MicroSD-Socket w/Det; SDCard-GCT_MEM2075-00-140-01-A
J7: KEY-PADDLE; CUI_SJ-63063B-audio-jack; PARTREV 1.0
J8: UART1 IO89; PinHeader_1x03_P2.54mm_Vertical
J9: UI 20-FCC; Amphenol_F51L_1x20_P1.00mm_Horizontal-FFC
J10: IO_EX; PinHeader_1x07_P2.54mm_Vertical
J11: SPKR_L; TerminalBlock_Philmore_TB132_1x02_P5.00mm_Horizontal
J12: SPKR_R; TerminalBlock_Philmore_TB132_1x02_P5.00mm_Horizontal
J13: UI 20-RBN; PinHeader_2x10_P2.54mm_Vertical
J14: AUDIO; CUI_DEVICES_SJ43516_SMT-CPJ
J15: SPI-0; PinSocket_1x07_P2.54mm_Vertical
J16: SPI-DISP; PinSocket_1x14_P2.54mm_Vertical
J17: SW_MATRIX; PinHeader_1x05_P2.54mm_Vertical
J18: UIM 20-FCC; Amphenol_F51L_1x20_P1.00mm_Horizontal-FFC
J19: UIM 20-RBN; PinHeader_2x10_P2.54mm_Vertical
J-SP1: Key-Paddle
JP1: S0-RX; PinHeader_1x02_P2.54mm_Vertical
JP2: J7-BP; PinHeader_1x02_P2.54mm_Vertical
JP3: AUD-SDR-; PinHeader_1x02_P2.54mm_Vertical
JP-PWR-1, JP-PWR-2: PWR-APWR-Bridge; PinHeader_2x02_P2.54mm_Vertical
KEY-EXT1: Key
LED1: PWR; LED_SMD_SIDEVIEW_Harvatek
LS1: Speaker
M_DISP1: Disp-2.8; MountingHole_3.2mm_M3
M_DISP2: Disp-3.5; MountingHole_3.2mm_M3
M_DISP3: Disp-4.0; MountingHole_3.2mm_M3
M_DISP4, M_DISP5: Mount; MountingHole_2.7mm_M2.5
M_H1, M_H2, M_H3, M_H4, M_H5: Mount; MountingHole_3.2mm_M3_ISO7380
M_KSI1, M_KSI2, M_KSI3, M_KSI4: MountingHole_Pad; MountingHole_3.2mm_M3_ISO7380_Pad_TopBottom
OP1: BZ-SPK; PinHeader_1x03_P2.54mm_Vertical
OP2, OP3, OP4, OP5, OP6, OP7: OP_A-B; PinHeader_1x03_P2.54mm_Vertical
OP8: IO28-ToneR; PinHeader_1x03_P2.54mm_Vertical
OP9: DISP-BL-PWR; PinHeader_1x03_P2.54mm_Vertical
Paddle1: PDL_EXT
Q1: 2N3904; TO-92_Inline
R1, R12, R15, R18: 100; R_0402_1005Metric_Pad0.72x0.64mm_HandSolder
R2: DNP; R_Axial_DIN0207_L6.3mm_D2.5mm_P10.16mm_Horizontal
R3, R20: 15.0k; R_0402_1005Metric_Pad0.72x0.64mm_HandSolder
R4, R5, R6, R7, R10: 100k; R_0402_1005Metric_Pad0.72x0.64mm_HandSolder
R8, R9, R24, R25: 10k; R_0402_1005Metric_Pad0.72x0.64mm_HandSolder
R11, R14: 220; R_0402_1005Metric_Pad0.72x0.64mm_HandSolder
R13, R16: 1.8k; R_0402_1005Metric_Pad0.72x0.64mm_HandSolder
R17: 20k; R_0402_1005Metric_Pad0.72x0.64mm_HandSolder
R19: 75.0k; R_0402_1005Metric_Pad0.72x0.64mm_HandSolder
R21: 3.00k; R_0402_1005Metric_Pad0.72x0.64mm_HandSolder
R22: 30.0k; R_0402_1005Metric_Pad0.72x0.64mm_HandSolder
R23: 7.50k; R_0402_1005Metric_Pad0.72x0.64mm_HandSolder
RE1: RotEnc-SW; RotaryEncoder_Bourns_Vertical_PEC12R-3xxxF-Sxxxx
SW1: RESET; SW_PUSH_SMD_1P1T_NO_45x45mm-CK
SW2: RE-SO; SW_PUSH_SMD_1P1T_NO_45x45mm-CK
SW3: UP; SW_PUSH_SMD_1P1T_NO_45x45mm-CK
SW4: LF; SW_PUSH_SMD_1P1T_NO_45x45mm-CK
SW5: EN; SW_PUSH_SMD_1P1T_NO_45x45mm-CK
SW6: RT; SW_PUSH_SMD_1P1T_NO_45x45mm-CK
SW7: DN; SW_PUSH_SMD_1P1T_NO_45x45mm-CK
SW8: RE-AO; SW_PUSH_SMD_1P1T_NO_45x45mm-CK
SW9: RE-BO; SW_PUSH_SMD_1P1T_NO_45x45mm-CK
TP1: VOL-A; PinHeader_1x01_P2.54mm_Vertical
TP2: VOL-B; PinHeader_1x01_P2.54mm_Vertical
TP3: AUD-IN; PinHeader_1x01_P2.54mm_Vertical
TP4: TONE-R; PinHeader_1x01_P2.54mm_Vertical
TP5: TONE-L; PinHeader_1x01_P2.54mm_Vertical
U1: MAX3221; TSSOP-16
U2: PicoW; RPi_PicoW_SMD_TH
U3: MCP23S08-E/SO; SOIC-18W_7.5x11.6mm_P1.27mm
U4: TLV70033_SOT23-5; SOT-23-5
U5: TPA2012D2RTJT; QFN50P400X400X80-21N270X270; PARTREV NA
U6: NC7WZ16P6X; SOT-363_SC-70-6

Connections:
+3.3V: C2.2, C4.1, C7.1, C8.1, CF1.1, CF2.1, CF3.1, CF4.1, CF5.1, J3.3, J5.2, J6.4 (VDD), J9.1, J13.2, J15.2, J16.1, J18.1, J19.2, JP-PWR-1.3, JP-PWR-2.3, R1.1, R4.1, R5.1, R6.1, R7.1, R17.1, R18.1, R24.1, R25.1, U1.15 (VCC), U2.36 (3V3), U3.18 (VDD), U5.3 (PVDD), U5.13 (PVDD)
+3.3VA: C9.1, C11.1, C18.1, CFA1.1, CFA2.1, CFA3.1, CFA4.1, CFA5.1, J9.20, J13.11, J18.20, J19.11, JP-PWR-1.4, JP-PWR-2.4, R3.1, R8.1, R9.1, U2.35 (ADC_VREF), U4.5 (OUT), U5.9 (AVDD), U6.5 (VCC)
/AIL+: C12.1, U5.20 (INL+)
/AIR+: C13.1, U5.16 (INR+)
/AOL+: J11.1, U5.2 (OUTL+)
/AOL-: J11.2, U5.5 (OUTL-)
/AOR+: J12.1, U5.14 (OUTR+)
/AOR-: J12.2, U5.11 (OUTR-)
/AUD_IN: C14.1, TP3.1, U2.32 (GPIO27_ADC1)
/BUZZ_DRV: BZ1.1 (-), OP1.1 (A)
/COM_RXD: J2.3, U1.8 (RIN)
/COM_TXD: J2.2, U1.13 (DOUT)
/DISP_BL_LED: J9.8, J13.16, J16.8, J18.8, J19.16, OP9.2 (C)
/DISP_CS-: J9.3, J13.6, J15.7, J16.3, J18.3, J19.6, U2.14 (GPIO10)
/DISP_D/C-: J9.5, J13.10, J15.6, J16.5, J18.5, J19.10, U2.7 (GPIO5)
/DISP_MISO: J9.9, J13.18, J16.9, J18.9, J19.18, U2.16 (GPIO12)
/DISP_MOSI: J9.6, J13.12, J15.4, J16.6, J18.6, J19.12, U2.15 (GPIO11)
/DISP_RST-: J9.4, J13.8, J15.5, J16.4, J18.4, J19.8, U2.17 (GPIO13), U3.6 (~RESET)
/DISP_SCK: J9.7, J13.14, J15.3, J16.7, J18.7, J19.14, U2.19 (GPIO14)
/EX_CS-: OP4.3 (B), U3.7 (~CS)
/EX_INT: OP5.3 (B), U3.8 (INT)
/EX_VOLA: OP6.3 (B), U3.10 (GP0)
/EX_VOLB: OP7.3 (B), U3.11 (GP1)
/ExIO2: J10.2, U3.12 (GP2)
/ExIO3: J10.3, U3.13 (GP3)
/ExIO4: J10.4, U3.14 (GP4)
/ExIO5: J10.5, U3.15 (GP5)
/ExIO6: J10.6, U3.16 (GP6)
/ExIO7: J10.7, U3.17 (GP7)
/GPIO08: OP2.2 (C), U2.11 (GPIO8)
/GPIO09: OP3.2 (C), U2.12 (GPIO9)
/GPIO28ADC2: J4.2, OP8.1 (A), OP9.1 (A)
/IO28_DBL_TGR: OP8.2 (C), U2.34 (GPIO28_ADC2)
/KEY-: J3.6, J7.4, JP2.2 (B)
/KEY_PDL_DOT-: J7.2, JP2.1 (A), U2.5 (GPIO3)
/MIC_IN: C15.2, J14.1 (S), R9.2
/PDL_DASH-: J3.7, J7.3, U2.6 (GPIO4)
/PWM_AUD_L: C19.1, J14.2 (T), R16.1
/PWM_AUD_R: C16.1, J14.3 (R1), R13.1
/PWM_L: R14.2, U6.4 (Y2)
/PWM_LL: C19.2, C20.1, R14.1, R15.1
/PWM_R: R11.2, U6.6 (Y1)
/PWM_RR: C16.2, C17.1, R11.1, R12.1
/P_VOL_A: OP2.3 (B), OP6.1 (A)
/P_VOL_B: OP3.3 (B), OP7.1 (A)
/RE_A: J5.3, J9.15, J13.1, J17.1, J18.15, J19.1, R24.2, RE1.A, SW8.1, U2.9 (GPIO6)
/RE_B: J5.4, J9.17, J13.5, J17.3, J18.17, J19.5, R25.2, RE1.B, SW9.1, U2.10 (GPIO7)
/RUN: C21.1, R17.2, SW1.1, U2.30 (RUN)
/SDL-: R7.2, U5.7 (~SDL)
/SDR-: JP3.1, R6.2, U5.8 (~SDR)
/SD_CARD_DET: J6.9 (CARD_DET), U2.20 (GPIO15)
/SD_CS-: J6.2 (DAT3/CD), U2.27 (GPIO21)
/SD_TP_EX_MISO: J6.7 (DAT0), U2.21 (GPIO16), U3.3 (SO)
/SD_TP_EX_SCK: J6.5 (CLK), J-SP1.1 (T), Paddle1.1, R2.1, U2.24 (GPIO18), U3.1 (SCK)
/SNDR_EN: J3.5, U2.4 (GPIO2)
/SW_MTRX: C22.1, C23.1, C24.1, C25.1, C26.1, C27.1, J9.19, J13.9, J17.4, J18.19, J19.9, R3.2, RE1.S2, SW2.1, SW3.1, SW4.1, SW5.1, SW6.1, SW7.1, U2.31 (GPIO26_ADC0)
/TCH_CLK: J9.10, J13.20, J16.10, J18.10, J19.20
/TCH_CS-: J9.11, J13.19, J16.11, J18.11, J19.19, U2.22 (GPIO17)
/TCH_IRQ-: J9.14, J13.13, J16.14, J18.14, J19.13, U2.26 (GPIO20)
/TCH_MISO: J9.13, J13.15, J16.13, J18.13, J19.15
/TCH_MOSI: J9.12, J13.17, J16.12, J18.12, J19.17
/TONE_GEN_L: OP1.2 (C), TP5.1, U2.29 (GPIO22)
/TONE_GEN_L_SPKR: OP1.3 (B), U6.3 (A2)
/TONE_GEN_R_SPKR: OP8.3 (B), TP4.1, U6.1 (A1)
/U1RX_EXINT: OP3.1 (A), OP5.2 (C)
/U1TX_EXCS: OP2.1 (A), OP4.2 (C)
/U1_RX: J8.2, OP5.1 (A)
/U1_TX: J8.3, OP4.1 (A)
/UART0_RX: J1.2, JP1.2, U2.2 (GPIO1)
/UART0_TX: J1.3, U1.11 (DIN), U2.1 (GPIO0)
/VOLA: OP6.2 (C), R4.2, TP1.1, U5.15 (G0)
/VOLB: OP7.2 (C), R5.2, TP2.1, U5.1 (G1)
GNDA: C9.2, C10.2, C11.2, C17.2, C18.2, C20.2, C22.2, C23.2, C24.2, C25.2, C26.2, C27.2, CFA1.2, CFA2.2, CFA3.2, CFA4.2, CFA5.2, J4.3, J9.18, J13.4, J14.4 (R2), J17.5, J18.18, J19.4, JP-PWR-1.2, JP-PWR-2.2, Q1.1 (E), R12.2, R13.2, R15.2, R16.2, R19.1, R20.1, R21.1, R22.1, R23.1, RE1.S1, SW2.2, U2.33 (AGND), U4.2 (GND), U5.17 (INR-), U5.18 (AGND), U5.19 (INL-)
unnamed: C13.2, J14.6 (R1N)
unnamed: C12.2, J14.5 (TN)
unnamed: J-SP1.2 (R), Paddle1.3
unnamed: JP1.1, U1.9 (ROUT)
unnamed: LED1.2 (A), R1.2
unnamed: OP9.3 (B), R18.2
unnamed: C15.1, Q1.2 (B), R10.2
unnamed: C14.2, Q1.3 (C), R8.2, R10.1
unnamed: R19.2, SW3.2
unnamed: R20.2, SW4.2
unnamed: R21.2, SW5.2
unnamed: R22.2, SW6.2
unnamed: R23.2, SW7.2
unnamed: C1.2, U1.2 (C1+)
unnamed: C1.1, U1.4 (C1-)
unnamed: C5.2, U1.5 (C2+)
unnamed: C5.1, U1.6 (C2-)
unnamed: C3.1, U1.3 (V+)
unnamed: C6.2, U1.7 (V-)
VBUS: U2.40 (VBUS)
VSYS: C10.1, J3.4, U2.39 (VSYS), U4.1 (IN), U4.3 (EN)

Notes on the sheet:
Jumper Settings: (All OP1-OP8:1-2 = Minimum Board) OP1:1-2 = BUZZER (No Audio) 2-3 = AUDIO (with Audio, with or w/o Amp) OP2,OP3,OP4,OP5:1-2 (no Audio Amp or ExpIO) = UART1 (GP 8&9) on J8 WITH - Audio and Amp OP2,OP3:2-3 OP6,OP7:1-2 = Volume from Pico WITH - Expansion IO OP2,OP3:1-2 OP4,OP5:2-3 OP6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
DC-
2.20v
RES
SCL
Speaker Amplifier w/volume (optional)
GND
Remove JP1 to use 3.5V serial for debug
1.10v
VCC
I2C-0
Audio+ Option
PicoW
0.55v
2.75v
CS-
SDA
3.5mm TRRS Audio (Cell)
Audio Output Option
OP8:1-2+BZ1 or OP8:2-3+rest
2.5mm RS232 (Same as ICOM IC-9700 Data)
Needed for Analog out and Mic in
I2C0_SDA
Serial Data Comm Option
Micro SD Card
Use when J7 not installed
Extrnal - Not part of MuKOB
Mic input (optional)
1.65v
1/4in Key/Paddle Jack (Same as ICOM IC-7300)
IO Expansion Option
I2C0_SCL
0.00V

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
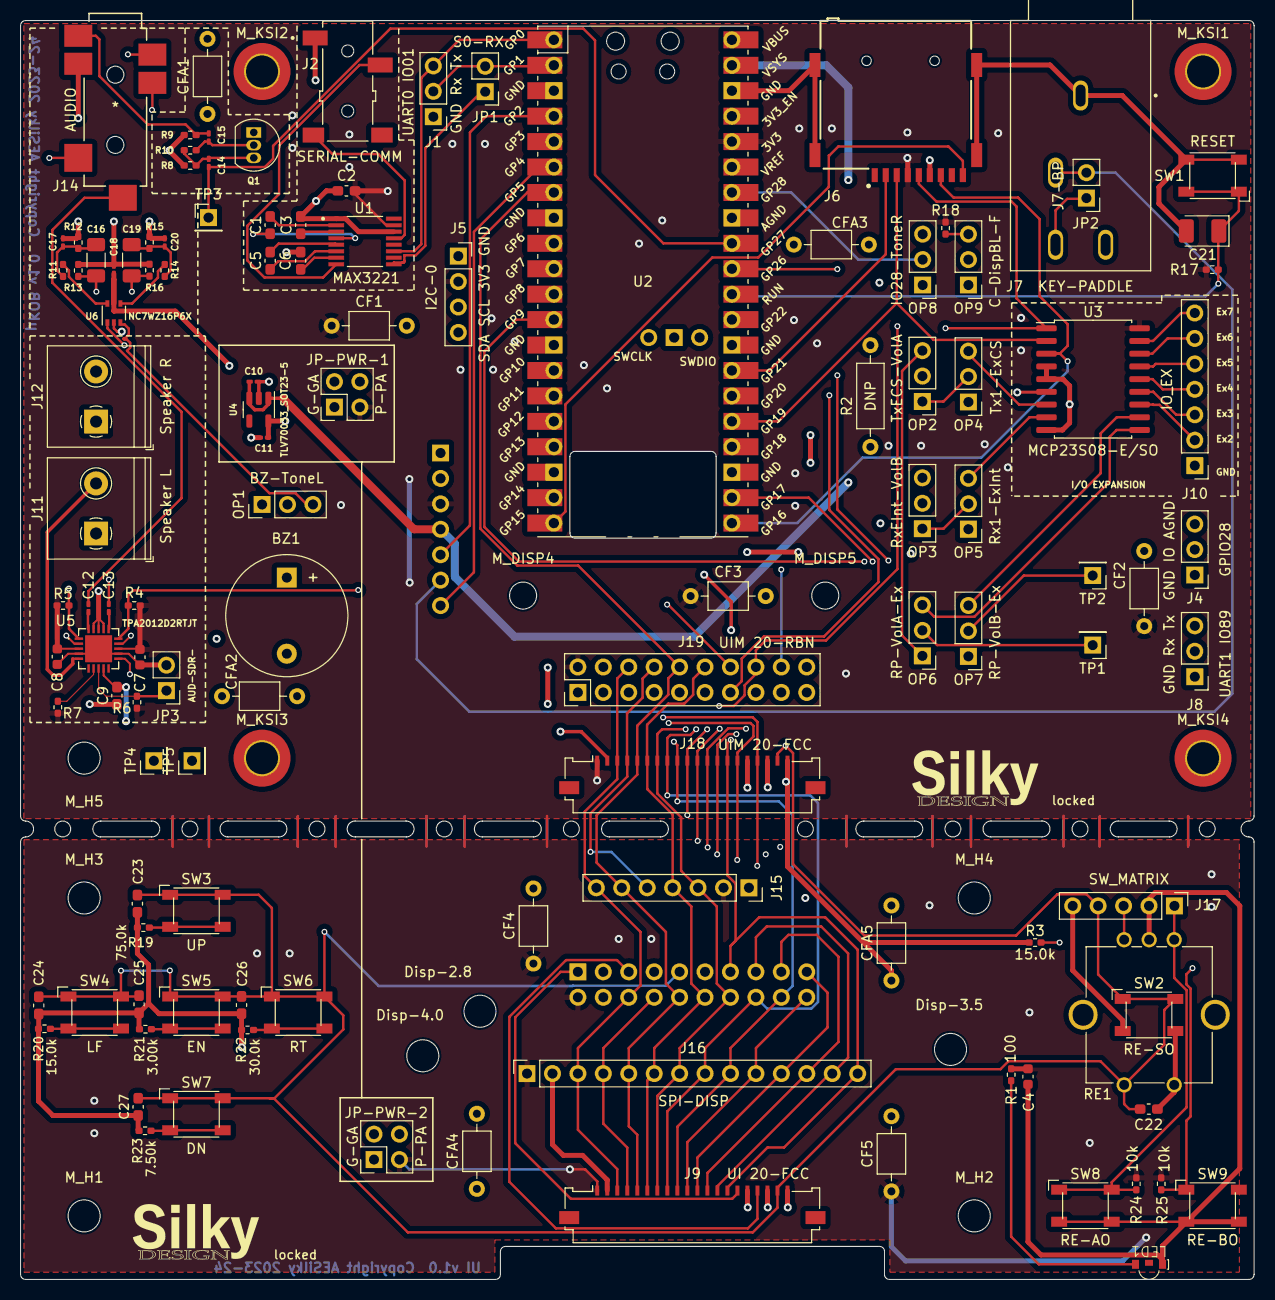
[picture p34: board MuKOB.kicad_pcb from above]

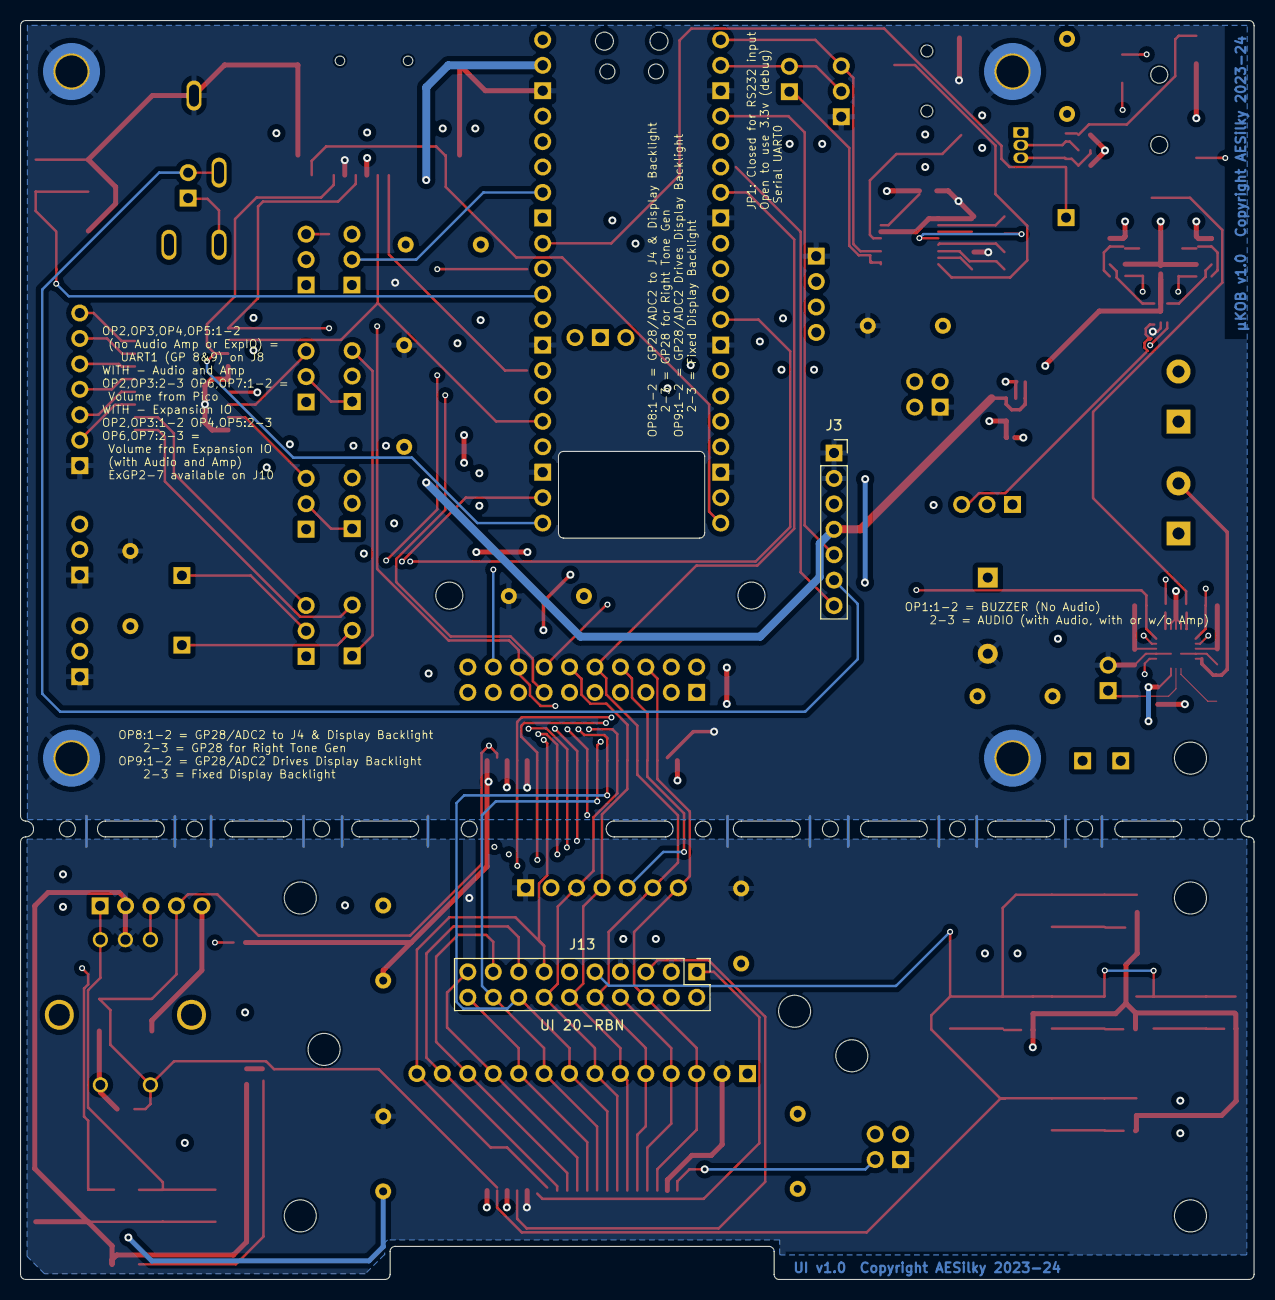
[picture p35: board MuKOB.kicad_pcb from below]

Board: 4 copper layers, 123.2 x 125.7 mm, 135 parts (2 on the bottom side), 94 nets.

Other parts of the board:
G1, G2: LOGO; SILKY-DESIGN-logo-0_50-AES

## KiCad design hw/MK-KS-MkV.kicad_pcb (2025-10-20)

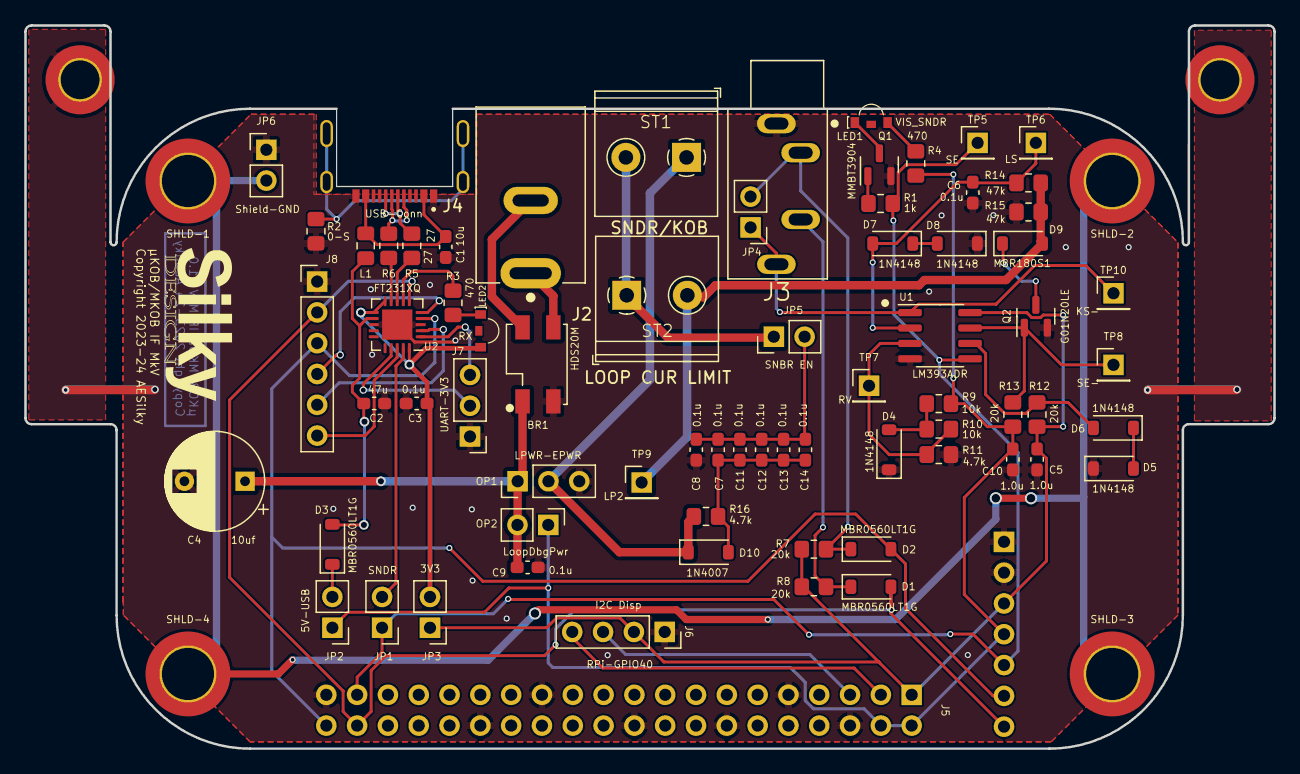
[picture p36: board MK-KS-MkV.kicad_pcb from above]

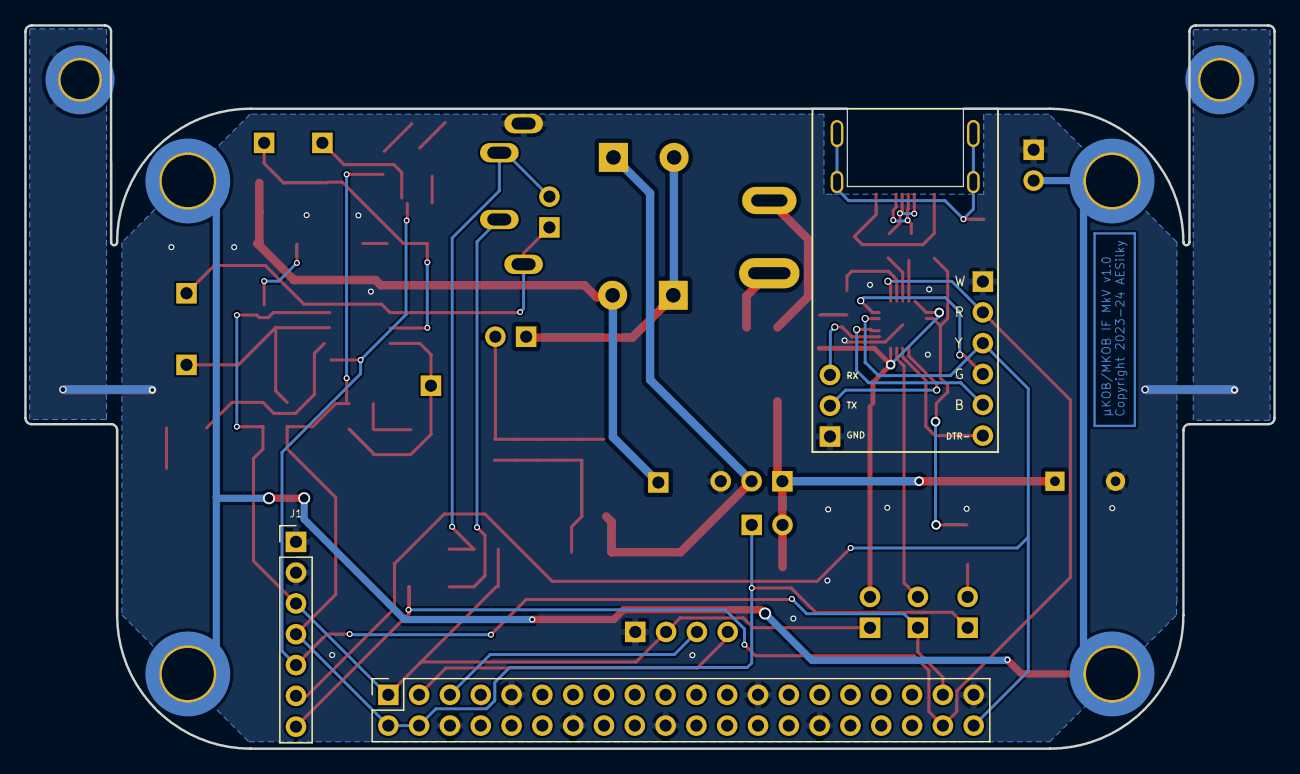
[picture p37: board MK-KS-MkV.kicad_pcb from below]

Board: 2 copper layers, 103.0 x 59.6 mm, 78 parts (2 on the bottom side), 48 nets.

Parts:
BR1: HDS20M; AES-BridgeRect-HDS20M-13-1KV-2A
C1: 10u; C_0603_1608Metric_Pad1.08x0.95mm_HandSolder
C2: 47u; C_0603_1608Metric_Pad1.08x0.95mm_HandSolder
C3, C6, C7, C8, C9, C11, C12, C13, C14: 0.1u; C_0603_1608Metric_Pad1.08x0.95mm_HandSolder
C4: 10uf; CP_Radial_D8.0mm_P5.00mm
C5, C10: 1.0u; C_0603_1608Metric_Pad1.08x0.95mm_HandSolder
D1, D2, D3: MBR0560LT1G; D_SOD-123
D4, D5, D6, D7, D8: 1N4148; D_SOD-123
D9: MBR180S1; D_SOD-123
D10: 1N4007; D_SOD-123
J1: MuKOB IF; PinHeader_1x07_P2.54mm_Vertical
J2: LOOP PWR; AES-CUI_PJ-037B
J3: KEY-PADDLE-1_8; AES-CUI_SJ1-3534NG-audio-jack
J4: USB-Conn; AES-USB_C_Amphenol_GSB1C4621DSHR
J5: RPi-GPIO40; PinSocket_2x20_P2.54mm_Vertical
J6: I2C Disp; PinSocket_1x04_P2.54mm_Vertical
J7: UART-3V3; PinHeader_1x03_P2.54mm_Vertical
J8: Selector-SW; PinHeader_1x06_P2.54mm_Vertical
JP1: SNDR; PinHeader_1x02_P2.54mm_Vertical
JP2: 5V-USB; PinHeader_1x02_P2.54mm_Vertical
JP3: 3V3; PinHeader_1x02_P2.54mm_Vertical
JP4: KeyJack-NP; PinHeader_1x02_P2.54mm_Vertical
JP5: SNBR EN; PinHeader_1x02_P2.54mm_Vertical
JP6: Shield-GND; PinHeader_1x02_P2.54mm_Vertical
L1: 600RJ0.5A; L_0805_2012Metric_Pad1.15x1.40mm_HandSolder
LED1: VIS_SNDR; AES-LED_SMD_SIDEVIEW_Harvatek
LED2: RX; AES-LED_SMD_SIDEVIEW_Harvatek
M_KSI1, M_KSI2: MountingHole_Pad; MountingHole_3.2mm_M3_ISO7380_Pad_TopBottom
OP1: LPWR-EPWR; PinHeader_1x03_P2.54mm_Vertical
OP2: LoopDbgPwr; PinHeader_1x02_P2.54mm_Vertical
Q1: MMBT3904; SOT-23
Q2: G01N20LE; SOT-23
R1: 1k; R_0805_2012Metric_Pad1.20x1.40mm_HandSolder
R2: 0-S; R_0805_2012Metric_Pad1.20x1.40mm_HandSolder
R3, R4: 470; R_0805_2012Metric_Pad1.20x1.40mm_HandSolder
R5, R6: 27; R_0805_2012Metric_Pad1.20x1.40mm_HandSolder
R7, R8, R12, R13: 20k; R_0805_2012Metric_Pad1.20x1.40mm_HandSolder
R9, R10: 10k; R_0805_2012Metric_Pad1.20x1.40mm_HandSolder
R11, R16: 4.7k; R_0805_2012Metric_Pad1.20x1.40mm_HandSolder
R14, R15: 47k; R_0805_2012Metric_Pad1.20x1.40mm_HandSolder
SHLD-1, SHLD-2, SHLD-3, SHLD-4: MountingHole_Pad; MountingHole_4.3mm_M4_ISO14580_Pad_TopBottom
ST1: SNDR/KOB; AES-TermBlock-2POS-5mm-Horz
ST2: LOOP CUR LIMIT; AES-TermBlock-2POS-5mm-Horz
TP5: SE; PinHeader_1x01_P2.54mm_Vertical
TP6: LS; PinHeader_1x01_P2.54mm_Vertical
TP7: RV; PinHeader_1x01_P2.54mm_Vertical
TP8: SE-; PinHeader_1x01_P2.54mm_Vertical
TP9: LP2; PinHeader_1x01_P2.54mm_Vertical
TP10: KS-; PinHeader_1x01_P2.54mm_Vertical
U1: LM393ADR; SOIC-8_3.9x4.9mm_P1.27mm
U2: FT231XQ; QFN-20-1EP_4x4mm_P0.5mm_EP2.5x2.5mm

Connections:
+3.3V: C5.2, J1.3, J5.1 (P3V3), J6.2, JP3.1 (A), R7.2, R8.2, R12.1, U1.8 (VCC)
+5V: C10.2, J1.4, J5.2 (P5V), J5.4 (P5V), JP2.1 (A), OP2.1, R4.1, R9.2, R13.2
/DASH-: D1.2 (A), J1.7, J5.38 (BCM20), J8.2, U2.6 (~CTS)
/DCD-: J8.4, U2.5 (~DCD)
/DOT-: D2.2 (A), J1.6, J5.40 (BCM21), J8.3, U2.4 (~DSR)
/DTR-: J8.6, U2.18 (~DTR)
/KEY_PDL_DOT-: D2.1 (K), J3.2, JP4.2 (B), R7.1
/KOB_KEY-: J3.4, JP4.1 (A), TP10.1, U1.1 (1OUT)
/LOOP_PWR: D10.1 (K), OP1.2 (C), R16.1, ST1.1
/LOOP_STATE: C6.1, D7.2 (A), R14.2, TP6.1, U1.2
/LP1: JP5.1 (A), ST1.2, ST2.1
/LP2: D9.2 (A), R14.1, R15.2, ST2.2, TP9.1
/LPI_A: BR1.4 (A), J2.1 (In)
/LPI_B: BR1.2 (A), J2.2 (Ext)
/LPI_P: BR1.1 (+), C4.1, C9.1, OP1.1 (A), OP2.2
/OFFSET_REF_V: R10.1, R11.2, TP7.1, U1.3
/PDL_DASH-: D1.1 (K), J3.3, R8.1
/RI-: J8.5, U2.2 (~RI)
/RTS: JP1.2 (B), U2.19 (~RTS)
/SCL: J5.5 (BCM3), J6.3
/SDA: J5.3 (BCM2), J6.4
/SNDR_EN: J1.5, J5.37 (BCM26), JP1.1 (A), R1.1, TP5.1, U1.5 (2IN+)
/SNDR_EN-: Q2.1 (G), R13.1, TP8.1, U1.7 (2OUT)
/V3.3I: C3.1, JP3.2 (B), LED2.2 (A), U2.10 (3V3OUT), U2.11 (~RESET), U2.20 (VCCIO)
/V5I: C2.2, D3.2 (A), L1.2, U2.12 (VCC)
Earth: JP6.2 (B), SHLD-1.1, SHLD-2.1, SHLD-3.1, SHLD-4.1
GND: BR1.3 (-), C1.1, C2.1, C3.2, C4.2, C5.1, C6.2, C8.2, C9.2, C10.1, D4.1 (K), D5.1 (K), D8.1 (K), J1.1, J1.2, J3.1, J4.A1_B12 (GND), J4.B1_A12 (GND), J5.6 (GND), J5.9 (GND), J5.14 (GND), J5.20 (GND), J5.25 (GND), J5.30 (GND), J5.39 (GND), J6.1, J7.1, J8.1, JP6.1 (A), M_KSI1.1, M_KSI2.1, OP1.3 (B), Q1.2 (E), Q2.2 (S), R2.1, R11.1, R15.1, U1.4 (GND), U2.3 (GND), U2.13 (GND), U2.21 (GND)
unnamed: C1.2, J4.A4_B9 (VBUS), J4.B4_A9 (VBUS), L1.1
unnamed: D3.1 (K), JP2.2 (B)
unnamed: D4.2 (A), R9.1, R10.2
unnamed: D5.2 (A), D6.1 (K)
unnamed: D6.2 (A), R12.2, U1.6 (2IN-)
unnamed: D7.1 (K), D8.2 (A)
unnamed: D9.1 (K), Q2.3 (D)
unnamed: C7.1, C11.1, C12.1, C13.1, C14.1, D10.2 (A), R16.2
unnamed: J4.A6 (D+), J4.B6 (D+), R5.1
unnamed: J4.A7 (D-), J4.B7 (D-), R6.1
unnamed: J4.SH1 (SHIELD), J4.SH2 (SHIELD), J4.SH3 (SHIELD), J4.SH4 (SHIELD), R2.2
unnamed: J7.2, U2.17 (TXD)
unnamed: J7.3, U2.1 (RXD)
unnamed: C7.2, C8.1, C11.2, C12.2, C13.2, C14.2, JP5.2 (B)
unnamed: LED1.2 (A), R4.2
unnamed: LED1.1 (K), Q1.3 (C)
unnamed: LED2.1 (K), R3.1
unnamed: Q1.1 (B), R1.2
unnamed: R3.2, U2.7 (CBUS2)
unnamed: R6.2, U2.9 (USBDM)
unnamed: R5.2, U2.8 (USBDP)

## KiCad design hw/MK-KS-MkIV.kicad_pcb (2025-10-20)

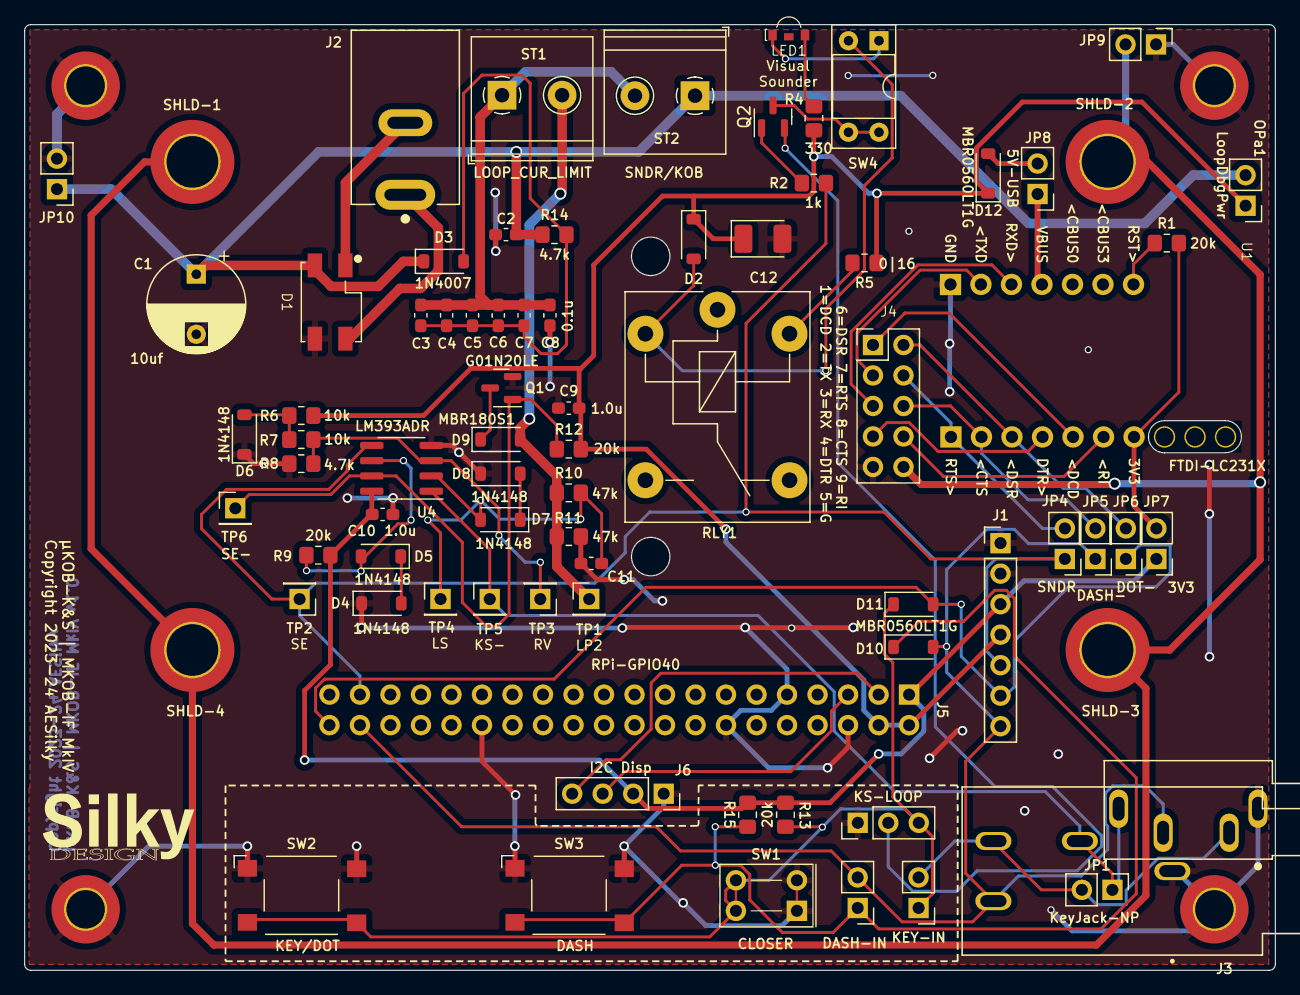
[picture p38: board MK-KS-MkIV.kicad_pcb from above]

Board: 2 copper layers, 104.1 x 78.7 mm, 84 parts (1 on the bottom side), 46 nets.

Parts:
C1: 10uf; CP_Radial_D8.0mm_P5.00mm
C2, C3, C4, C5, C6, C7, C8, C11: 0.1u; C_0603_1608Metric_Pad1.08x0.95mm_HandSolder
C9, C10: 1.0u; C_0603_1608Metric_Pad1.08x0.95mm_HandSolder
C12: 10uf Tant; CP_EIA-3528-12_Kemet-T_Pad1.50x2.35mm_HandSolder
D1: HDS20M; AES-BridgeRect-HDS20M-13-1KV-2A
D2, D10, D11, D12: MBR0560LT1G; D_SOD-123
D3: 1N4007; D_SOD-123
D4, D5, D6, D7, D8: 1N4148; D_SOD-123
D9: MBR180S1; D_SOD-123
G1: LOGO; SILKY-DESIGN-logo-0_50-AES
J1: MuKOB IF; PinHeader_1x07_P2.54mm_Vertical
J2: LOOP PWR; AES-CUI_PJ-037B
J3: KEY-PADDLE; AES-CUI_SJ-63063B-audio-jack
J4: COMM-DCE-10; PinHeader_2x05_DB9-Order
J5: RPi-GPIO40; PinSocket_2x20_P2.54mm_Vertical
J6: I2C Disp; PinSocket_1x04_P2.54mm_Vertical
J7: KEY-PADDLE-1_8; CUI_SJ1-3534NG-audio-jack
JP1: KeyJack-NP; PinHeader_1x02_P2.54mm_Vertical
JP2: KEY-IN; PinHeader_1x02_P2.54mm_Vertical
JP3: DASH-IN; PinHeader_1x02_P2.54mm_Vertical
JP4: SNDR; PinHeader_1x02_P2.54mm_Vertical
JP5: DASH-; PinHeader_1x02_P2.54mm_Vertical
JP6: DOT-; PinHeader_1x02_P2.54mm_Vertical
JP7: 3V3; PinHeader_1x02_P2.54mm_Vertical
JP8: 5V-USB; PinHeader_1x02_P2.54mm_Vertical
JP9: Shield_GND; PinHeader_1x02_P2.54mm_Vertical
JP10: EX-PWR; PinHeader_1x02_P2.54mm_Vertical
LED1: VIS_SNDR; AES-LED_SMD_SIDEVIEW_Harvatek
M_KSI1, M_KSI2, M_KSI3, M_KSI4: MountingHole_Pad; MountingHole_3.2mm_M3_ISO7380_Pad_TopBottom
OP1: KS-LOOP; PinHeader_1x03_P2.54mm_Vertical
OPa1: LoopDbgPwr; PinHeader_1x02_P2.54mm_Vertical
Q1: G01N20LE; SOT-23
Q2: MMBT3904; SOT-23
R1, R9, R12, R13, R15: 20k; R_0805_2012Metric_Pad1.20x1.40mm_HandSolder
R2: 1k; R_0805_2012Metric_Pad1.20x1.40mm_HandSolder
R4: 330; R_0805_2012Metric_Pad1.20x1.40mm_HandSolder
R5: 0|16; R_0805_2012Metric_Pad1.20x1.40mm_HandSolder
R6, R7: 10k; R_0805_2012Metric_Pad1.20x1.40mm_HandSolder
R8, R14: 4.7k; R_0805_2012Metric_Pad1.20x1.40mm_HandSolder
R10, R11: 47k; R_0805_2012Metric_Pad1.20x1.40mm_HandSolder
RLY1: RELAY-5v|3v-DPST; Relay_SPDT_Finder_36.11
SHLD-1, SHLD-2, SHLD-3, SHLD-4: MountingHole_Pad; MountingHole_4.3mm_M4_ISO14580_Pad_TopBottom
ST1: LOOP_CUR_LIMIT; TerminalBlock_Philmore_TB132_1x02_P5.00mm_Horizontal
ST2: SNDR/KOB; TerminalBlock_Philmore_TB132_1x02_P5.00mm_Horizontal
SW1: CLOSER; AES-SW-TGL-Micro-DPST-CIT
SW2: KEY/DOT; AES-SW_PUSH_SMD_1P1T_NO_6x6mm
SW3: DASH; AES-SW_PUSH_SMD_1P1T_NO_6x6mm
SW4: SW_DIP_x02; DIP-4_W7.62mm_Socket
TP1: LP2; PinHeader_1x01_P2.54mm_Vertical
TP2: SE; PinHeader_1x01_P2.54mm_Vertical
TP3: RV; PinHeader_1x01_P2.54mm_Vertical
TP4: LS; PinHeader_1x01_P2.54mm_Vertical
TP5: KS-; PinHeader_1x01_P2.54mm_Vertical
TP6: SE-; PinHeader_1x01_P2.54mm_Vertical
U1: FTDI-LC231X; AES-FTDI_LC231X
U4: LM393ADR; SOIC-8_3.9x4.9mm_P1.27mm

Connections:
+3.3V: C10.2, J1.3, J5.1 (P3V3), J6.2, JP7.1 (A), R9.1, R13.2, R15.2, U4.8 (VCC)
+5V: C9.2, C12.1, D2.1 (K), D12.1 (K), J1.4, J5.2 (P5V), J5.4 (P5V), OPa1.1, R4.1, R5.1, R6.2, R12.2
/CTS: J4.8, JP5.2 (B), U1.2R (CTS)
/DASH-: D10.1 (K), JP3.1 (A), R15.1, SW3.2
/DOT-: D11.1 (K), JP2.1 (A), OP1.3 (B), R13.1, SW1.2 (B), SW2.2
/DSR: J4.6, JP6.2 (B), U1.3R (DSR)
/DTR: J4.4, U1.4R (DTR)
/KEY_PDL-: J3.2, J7.2, JP1.2 (B), JP2.2 (B)
/KEY_PDL_DOT-: D11.2 (A), J1.6, J5.40 (BCM21), JP6.1 (A)
/KOB_KEY-: J3.4, J7.4, JP1.1 (A), TP5.1, U4.1 (1OUT)
/LOOP_PWR: C1.1, C2.1, D1.3 (+), D3.1 (K), JP10.1 (A), OPa1.2, R14.1, ST2.1
/LOOP_STATE: C11.1, D7.2 (A), R10.2, TP4.1, U4.2
/LP1: C3.2, C4.2, C5.2, C6.2, C7.2, C8.1, ST1.1, ST2.2
/LP2: D9.2 (A), R10.1, R11.2, ST1.2, TP1.1
/LPI_A: D1.2, J2.1 (In)
/LPI_B: D1.1, J2.2 (Ext)
/OFFSET_REF_V: R7.1, R8.2, TP3.1, U4.3
/PDL_DASH-: D10.2 (A), J1.7, J3.3, J5.38 (BCM20), J7.3, JP3.2 (B), JP5.1 (A)
/RESET-: R1.1, U1.7L (Reset#)
/RI: J4.9, U1.6R (RI)
/RTS: J4.7, JP4.2 (B), U1.1R (RTS)
/RXD: J4.3, U1.3L (RXD)
/SCL: J5.5 (BCM3), J6.3
/SDA: J5.3 (BCM2), J6.4
/SEL: LED1.1 (K), SW4.1
/SER: D2.2 (A), RLY1.A1, SW4.2
/SLG: OP1.2 (C), Q2.2 (E)
/SLG-C: Q2.3 (C), SW4.3, SW4.4
/SNDR_EN: J1.5, J5.37 (BCM26), JP4.1 (A), R2.1, TP2.1, U4.5 (2IN+)
/SNDR_EN-: Q1.1 (G), R12.1, TP6.1, U4.7 (2OUT)
/TXD: J4.2, U1.2L (TXD)
/V3.3I: JP7.2 (B), R1.2, U1.7R (3V3)
/V5I: D12.2 (A), JP8.2 (B)
/VBUS: JP8.1 (A), U1.4L (VBUS)
Earth: J4.10, JP9.2 (B), SHLD-1.1, SHLD-2.1, SHLD-3.1, SHLD-4.1
GND: C1.2, C2.2, C8.2, C9.1, C10.1, C11.2, C12.2, D1.4 (-), D4.1 (K), D6.1 (K), D8.1 (K), J1.1, J1.2, J3.1, J4.5, J5.6 (GND), J5.9 (GND), J5.14 (GND), J5.20 (GND), J5.25 (GND), J5.30 (GND), J5.39 (GND), J6.1, J7.1, JP9.1 (A), JP10.2 (B), M_KSI1.1, M_KSI2.1, M_KSI3.1, M_KSI4.1, OP1.1 (A), Q1.2 (S), R8.1, R11.1, SW1.1 (A), SW2.1, SW3.1, U1.1L (GND), U4.4 (GND)
unnamed: C3.1, C4.1, C5.1, C6.1, C7.1, D3.2 (A), R14.2
unnamed: D4.2 (A), D5.1 (K)
unnamed: D5.2 (A), R9.2, U4.6 (2IN-)
unnamed: D6.2 (A), R6.1, R7.2
unnamed: D7.1 (K), D8.2 (A)
unnamed: D9.1 (K), Q1.3 (D)
unnamed: J4.1, U1.5R (DCD)
unnamed: LED1.2 (A), R4.2
unnamed: Q2.1 (B), R2.2
unnamed: R5.2, RLY1.A2

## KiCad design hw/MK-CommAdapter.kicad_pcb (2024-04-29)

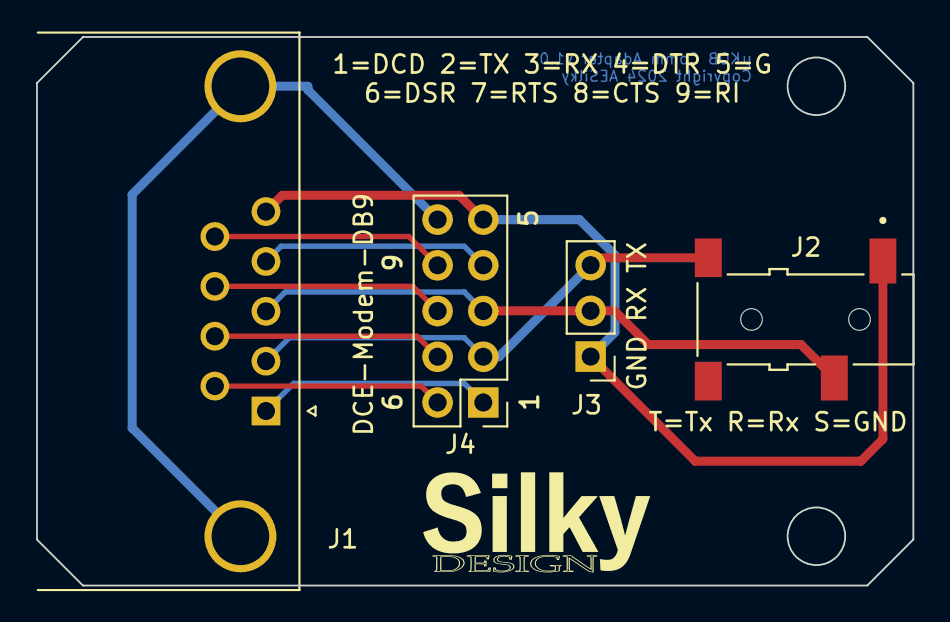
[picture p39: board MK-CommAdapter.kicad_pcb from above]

Board: 2 copper layers, 48.7 x 30.5 mm, 4 parts (0 on the bottom side), 10 nets.

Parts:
J1: DCE-Modem-DB9; DSUB-9_Female_Horizontal_P2.77x2.84mm_EdgePinOffset9.90mm_H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
J2: MuKOB-COMM; CUI_SJ-2524-SMT-TRS-audio-jack
J3: COMM-3; PinHeader_1x03_P2.54mm_Vertical
J4: COMM-DCE-10; PinHeader_2x05_DB9-Order

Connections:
/CH-GND: J1.0 (PAD), J4.10
/CTS: J1.8, J4.8
/DCD: J1.1, J4.1
/DSR: J1.6, J4.6
/DTR: J1.4, J4.4
/RI: J1.9, J4.9
/RTS: J1.7, J4.7
/RXD: J1.3, J2.3, J3.2, J4.3
/TXD: J1.2, J2.2, J3.3, J4.2
GND: J1.5, J2.1, J3.1, J4.5

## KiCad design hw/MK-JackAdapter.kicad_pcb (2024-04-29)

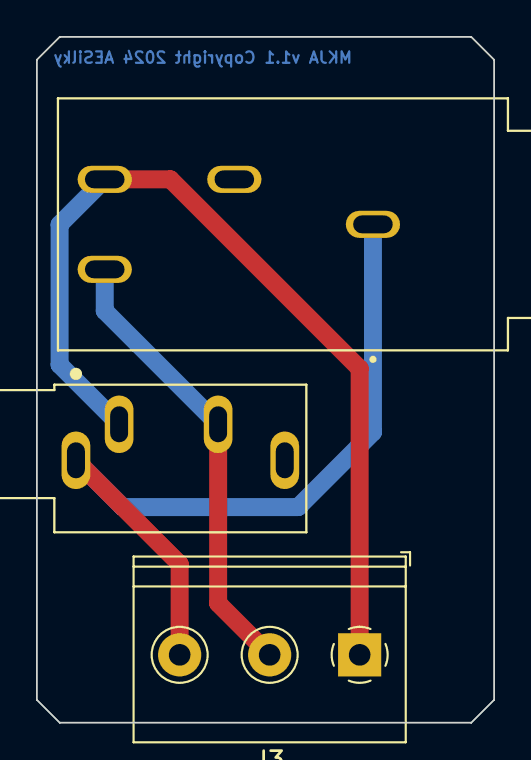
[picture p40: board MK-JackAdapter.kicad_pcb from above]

Board: 2 copper layers, 25.4 x 38.1 mm, 3 parts (0 on the bottom side), 3 nets.

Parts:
J1: KEY-PADDLE-4; CUI_SJ-63063B-audio-jack
J2: KEY-PADDLE-8; CUI_SJ1-3534NG-audio-jack
J3: Screw_Terminal_01x03; TerminalBlock_Philmore_TB133_1x03_P5.00mm_Horizontal

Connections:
/COMMON: J1.1, J2.1, J3.3
/KEY_PDL_DOT-: J1.2, J2.2, J3.1
/PDL_DASH-: J1.3, J2.3, J3.2

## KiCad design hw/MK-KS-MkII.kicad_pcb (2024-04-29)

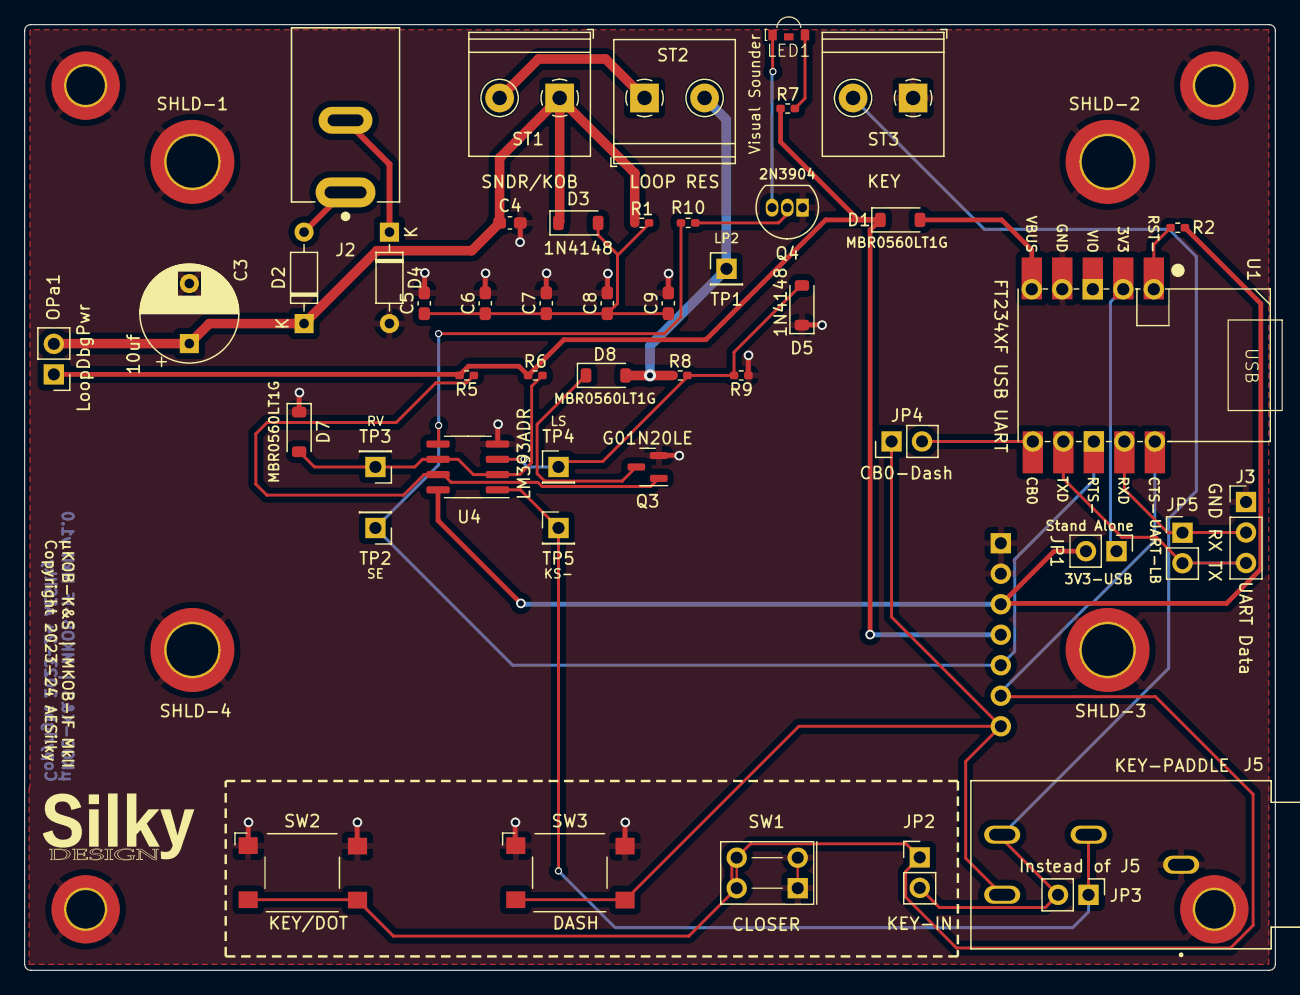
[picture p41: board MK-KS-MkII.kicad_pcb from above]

Board: 2 copper layers, 104.1 x 78.7 mm, 57 parts (1 on the bottom side), 27 nets.

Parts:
C3: 10uf; CP_Radial_D8.0mm_P5.00mm
C4, C5, C6, C7, C8, C9: 0.1u; C_0603_1608Metric_Pad1.08x0.95mm_HandSolder
D1, D7, D8: MBR0560LT1G; D_SOD-123
D2, D4: 1N4148; D_DO-35_SOD27_P7.62mm_Horizontal
D3, D5: 1N4148; D_SOD-123
G1: LOGO; SILKY-DESIGN-logo-0_50-AES
J2: LOOP PWR; AES-CUI_PJ-037B
J3: UART Data; PinHeader_1x03_P2.54mm_Vertical
J4: MuKOB IF; PinHeader_1x07_P2.54mm_Vertical
J5: KEY-PADDLE; AES-CUI_SJ-63063B-audio-jack
JP1: 3V3-USB; PinHeader_1x02_P2.54mm_Vertical
JP2: KEY-IN; PinHeader_1x02_P2.54mm_Vertical
JP3: Key Jack NP; PinHeader_1x02_P2.54mm_Vertical
JP4: CB0-Dash; PinHeader_1x02_P2.54mm_Vertical
JP5: UART-LB; PinHeader_1x02_P2.54mm_Vertical
LED1: SNDR; AES-LED_SMD_SIDEVIEW_Harvatek
M_KSI1, M_KSI2, M_KSI3, M_KSI4: MountingHole_Pad; MountingHole_3.2mm_M3_ISO7380_Pad_TopBottom
OPa1: LoopDbgPwr; PinHeader_1x02_P2.54mm_Vertical
Q3: G01N20LE; SOT-23
Q4: 2N3904; TO-92_Inline
R1: 3.3k; R_0402_1005Metric_Pad0.72x0.64mm_HandSolder
R2, R5, R6, R8: 20k; R_0402_1005Metric_Pad0.72x0.64mm_HandSolder
R7: 100; R_0402_1005Metric_Pad0.72x0.64mm_HandSolder
R9: DNP; R_0402_1005Metric_Pad0.72x0.64mm_HandSolder
R10: 1k; R_0402_1005Metric_Pad0.72x0.64mm_HandSolder
SHLD-1, SHLD-2, SHLD-3, SHLD-4: MountingHole_Pad; MountingHole_4.3mm_M4_ISO14580_Pad_TopBottom
ST1: SNDR/KOB; TerminalBlock_Philmore_TB132_1x02_P5.00mm_Horizontal
ST2: LOOP RES; TerminalBlock_Philmore_TB132_1x02_P5.00mm_Horizontal
ST3: KEY; TerminalBlock_Philmore_TB132_1x02_P5.00mm_Horizontal
SW1: CLOSER; AES-SW-TGL-Micro-DPST-CIT
SW2: KEY/DOT; AES-SW_PUSH_SMD_1P1T_NO_6x6mm
SW3: DASH; AES-SW_PUSH_SMD_1P1T_NO_6x6mm
TP1: LP2; PinHeader_1x01_P2.54mm_Vertical
TP2: SE; PinHeader_1x01_P2.54mm_Vertical
TP3: RV; PinHeader_1x01_P2.54mm_Vertical
TP4: LS; PinHeader_1x01_P2.54mm_Vertical
TP5: KS-; PinHeader_1x01_P2.54mm_Vertical
U1: FT234XF_USB_UART_Module; AES-FTDI-UMFT234XF
U4: LM393ADR; SOIC-8_3.9x4.9mm_P1.27mm

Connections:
+3.3V: J4.3, JP1.2 (B), R2.2, U4.8 (VCC)
+5V: D1.1 (K), J4.4, OPa1.1, R5.2, R6.1, R7.1
/CB0: JP4.2 (B), U1.6 (CB0)
/KEY_PDL-: J5.2, JP2.2 (B), JP3.2 (B), ST3.2
/KEY_PDL_DOT-: J4.6, JP2.1 (A), SW1.2 (B), SW2.2, U1.10 (CTS-)
/KOB_KEY-: J5.4, JP3.1 (A), TP5.1, U4.1 (1OUT)
/LOOP_PWR: C3.1, C4.1, D2.1 (K), D3.1 (K), OPa1.2, R1.1, ST1.1
/LOOP_STATE: D5.2 (A), R8.2, R9.2, TP4.1, U4.3
/LP1: ST1.2, ST2.1
/LP2: D8.2 (A), R8.1, ST2.2, TP1.1
/LPI+: D2.2 (A), J2.1 (In)
/LPI-: D4.1 (K), J2.2 (Ext)
/OFFSET_REF_V: D7.2 (A), R6.2, TP3.1, U4.2, U4.6 (2IN-)
/PDL_DASH-: J4.7, J5.3, JP4.1 (A), SW3.2
/RESET-: R2.1, U1.1 (RESET-)
/RXD: J3.2, JP5.1 (A), U1.9 (RXD)
/SNDR_EN: J4.5, R10.1, TP2.1, U1.8 (RTS-), U4.5 (2IN+)
/SNDR_EN-: Q3.1 (G), R5.1, U4.7 (2OUT)
/TXD: J3.3, JP5.2 (B), U1.7 (TXD)
/V3.3I: JP1.1 (A), U1.2 (3V3)
/V5I: D1.2 (A), U1.5 (VBUS)
GND: C3.2, C4.2, C5.2, C6.2, C7.2, C8.2, C9.2, D4.2 (A), D5.1 (K), D7.1 (K), J3.1, J4.1, J4.2, J5.1, M_KSI1.1, M_KSI2.1, M_KSI3.1, M_KSI4.1, Q3.2 (S), Q4.1 (E), R9.1, SHLD-1.1, SHLD-2.1, SHLD-3.1, SHLD-4.1, ST3.1, SW1.1 (A), SW2.1, SW3.1, U1.4 (GND), U4.4 (GND)
unnamed: C5.1, C6.1, C7.1, C8.1, C9.1, D3.2 (A), R1.2
unnamed: D8.1 (K), Q3.3 (D)
unnamed: LED1.2 (A), R7.2
unnamed: LED1.1 (K), Q4.3 (C)
unnamed: Q4.2 (B), R10.2

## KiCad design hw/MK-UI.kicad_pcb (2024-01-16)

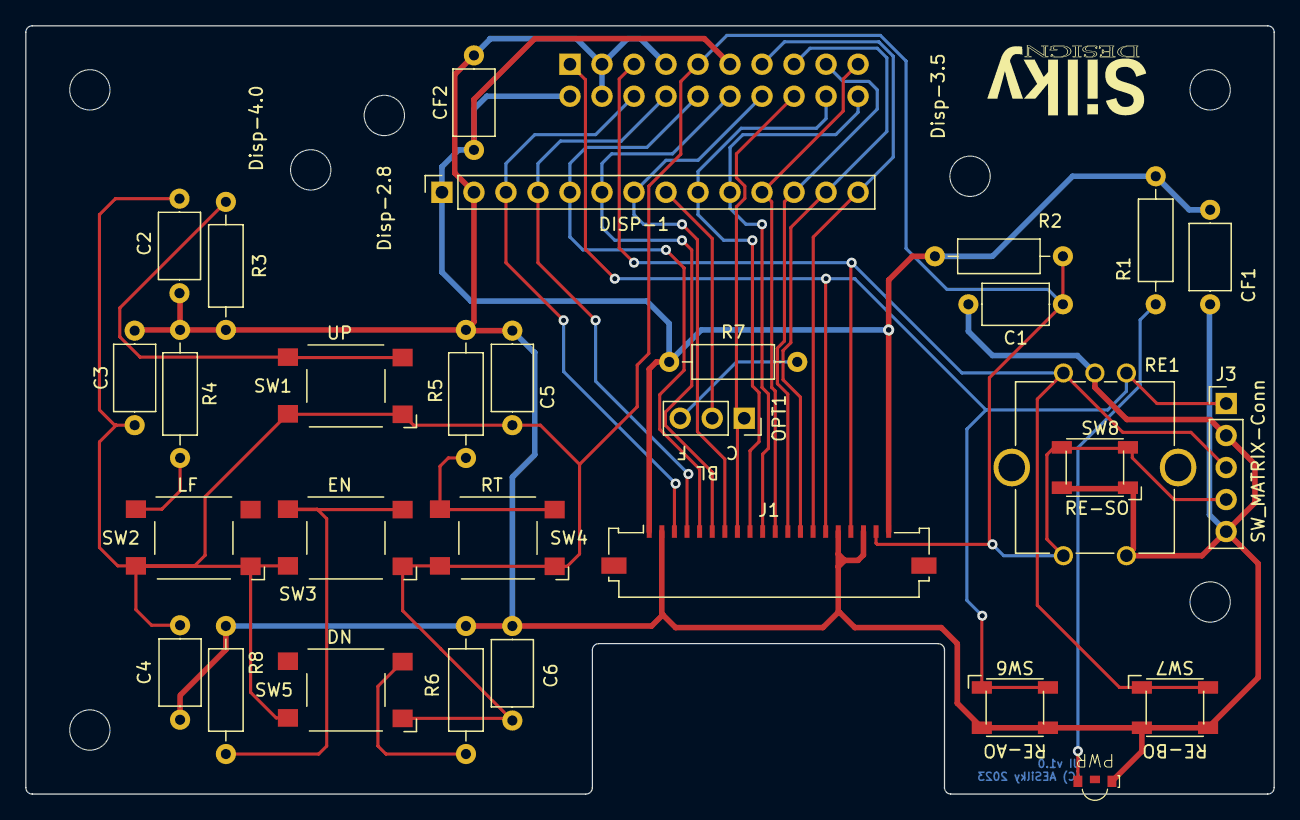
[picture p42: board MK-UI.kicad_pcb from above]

Board: 2 copper layers, 99.1 x 61.0 mm, 38 parts (1 on the bottom side), 25 nets.

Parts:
C1, C2, C3, C4, C5, C6: 0.1uF; C_Axial_L5.1mm_D3.1mm_P7.50mm_Horizontal
CF1, CF2: 0.1uF; C_Axial_L5.1mm_D3.1mm_P7.50mm_Horizontal
DISP-1: TFT-SPI w/Touch 9/5; PinSocket_1x14_P2.54mm_Vertical
H1, H2, H3, H4: MountingHole; MountingHole_3.2mm_M3
J1: Conn_01x20-FFC; Amphenol_F51L_1x20_P1.00mm_Horizontal-FFC
J2: UI 20-RBN; PinHeader_2x10_P2.54mm_Vertical
J3: SW_MATRIX-Conn; PinHeader_1x05_P2.54mm_Vertical
LED1: PWR; LED_SMD_SIDEVIEW_Harvatek
M_DISP1: Disp-2.8; MountingHole_3.2mm_M3
M_DISP2: Disp-3.5; MountingHole_3.2mm_M3
M_DISP3: Disp-4.0; MountingHole_3.2mm_M3
OPT1: Conn_01x03; PinSocket_1x03_P2.54mm_Vertical
R1, R7: 100; R_Axial_DIN0207_L6.3mm_D2.5mm_P10.16mm_Horizontal
R2: 10k; R_Axial_DIN0207_L6.3mm_D2.5mm_P10.16mm_Horizontal
R3: 47k; R_Axial_DIN0207_L6.3mm_D2.5mm_P10.16mm_Horizontal
R4: 15k; R_Axial_DIN0207_L6.3mm_D2.5mm_P10.16mm_Horizontal
R5: 28k; R_Axial_DIN0207_L6.3mm_D2.5mm_P10.16mm_Horizontal
R6: 6.8k; R_Axial_DIN0207_L6.3mm_D2.5mm_P10.16mm_Horizontal
R8: 2.2k; R_Axial_DIN0207_L6.3mm_D2.5mm_P10.16mm_Horizontal
RE1: RotEnc-SW; RotaryEncoder_Bourns_Vertical_PEC12R-3xxxF-Sxxxx
SW1: UP; SW_PUSH_SMD_1P1T_NO_6x6mm
SW2: LF; SW_PUSH_SMD_1P1T_NO_6x6mm
SW3: EN; SW_PUSH_SMD_1P1T_NO_6x6mm
SW4: RT; SW_PUSH_SMD_1P1T_NO_6x6mm
SW5: DN; SW_PUSH_SMD_1P1T_NO_6x6mm
SW6: RE-AO; SW_PUSH_SMD_1P1T_NO_45x45mm-CK
SW7: RE-BO; SW_PUSH_SMD_1P1T_NO_45x45mm-CK
SW8: RE-SO; SW_PUSH_SMD_1P1T_NO_45x45mm-CK

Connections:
+3.3V: CF1.1, CF2.1, DISP-1.1 (VCC), J1.1, J1.20, J2.2, J2.11, R1.1, R2.1, R7.1
/DISP_BL_LED: J1.8, J2.16, OPT1.1
/DISP_CS-: DISP-1.3 (CS-), J1.3, J2.6
/DISP_D/C-: DISP-1.5 (D/C-), J1.5, J2.10
/DISP_MISO: DISP-1.9 (MISO_SDO), J1.9, J2.18
/DISP_MOSI: DISP-1.6 (MOSI_SDI), J1.6, J2.12
/DISP_RST-: DISP-1.4 (RESET-), J1.4, J2.8
/DISP_SCK: DISP-1.7 (SCK), J1.7, J2.14
/RE_A: J1.15, J2.1, J3.1, RE1.A, SW6.1
/RE_B: J1.17, J2.5, J3.3, RE1.B, SW7.1
/SW_MTRX: C1.1, C2.1, C3.1, C4.1, C5.1, C6.1, J1.19, J2.9, J3.4, R2.2, RE1.S2, SW1.1, SW2.1, SW3.1, SW4.1, SW5.1, SW8.2
/TCH_CLK: DISP-1.10 (T_CLK), J1.10, J2.20
/TCH_CS-: DISP-1.11 (T_CS-), J1.11, J2.19
/TCH_IRQ-: DISP-1.14 (T_IRQ), J1.14, J2.13
/TCH_MISO: DISP-1.13 (T_DO), J1.13, J2.15
/TCH_MOSI: DISP-1.12 (T_DIN), J1.12, J2.17
GND: C1.2, C2.2, C3.2, C4.2, C5.2, C6.2, CF1.2, CF2.2, DISP-1.2 (GND), J1.2, J1.16, J1.18, J2.3, J2.4, J2.7, J3.2, J3.5, LED1.1 (K), R3.1, R4.1, R5.1, R6.1, R8.1, RE1.C, RE1.S1, SW6.2, SW7.2, SW8.1
unnamed: DISP-1.8 (LED_BL), OPT1.2
unnamed: LED1.2 (A), R1.2
unnamed: OPT1.3, R7.2
unnamed: R3.2, SW1.2
unnamed: R4.2, SW2.2
unnamed: R5.2, SW4.2
unnamed: R6.2, SW5.2
unnamed: R8.2, SW3.2

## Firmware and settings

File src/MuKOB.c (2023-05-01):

/**
 * MuKOB main application.
 *
 * Copyright 2023 AESilky
 * SPDX-License-Identifier: MIT License
 *
*/
#include "pico/binary_info.h"
//
#include "system_defs.h" // Main system/board/application definitions
//
#include "be.h"
#include "mkboard.h"
#include "mkdebug.h"
#include "morse.h"
#include "ui.h"

#define DOT_MS 60 // Dot at 20 WPM
#define UP_MS  DOT_MS
#define DASH_MS (2 * DOT_MS)
#define CHR_SP (3 * DOT_MS)

 // 'H' (....) 'I' (..)
static const int32_t say_hi[] = {
    DOT_MS,
    UP_MS,
    DOT_MS,
    UP_MS,
    DOT_MS,
    UP_MS,
    DOT_MS,
    CHR_SP,
    DOT_MS,
    UP_MS,
    DOT_MS,
    1000, // Pause before repeating
    0 };

//static int32_t qbf[] = { -32767, 2, -460, 180, -230, 60, -60, 60, -60, 60, -60, 60, -230, 60, -460, 60, -60, 60, -60, 180, 60, 60, -230, 60, -60, 60, -60, 180 };

int main()
{
    // useful information for picotool
    bi_decl_if_func_used(bi_2pins_with_func(PICO_DEFAULT_UART_RX_PIN, PICO_DEFAULT_UART_TX_PIN, GPIO_FUNC_UART));
    bi_decl(bi_program_description("Micro version of MorseKOB, with built-in display and terminal UI"));

    // Board/base level initialization
    board_init();

    // Indicate that we are awake
    if (mk_debug()) {
        tone_sound_pattern(150);
    }
    led_on_off(say_hi);

    // Set up the Backend (needs to be done before starting the UI)
    be_module_init();

    // Launch the UI (core-1 Message Dispatching Loop)
    start_ui();

    // Launch the Backend (core-0 (endless) Message Dispatching Loop - never returns)
    start_be();

    // How did we get here?!
    error_printf(true, "MuKOB - Somehow we are out of our endless message loop in `main()`!!!");
    // ZZZ Reboot!!!
    return 0;
}

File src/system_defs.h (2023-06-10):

#ifndef _SYSTEM_DEFS_H_
#define _SYSTEM_DEFS_H_
#ifdef __cplusplus
extern "C" {
#endif

#define MuKOB_VERSION_INFO "MuKOB v0.1"  // ZZZ get from a central name/version string

#undef putc     // Undefine so the standard macros will not be used
#undef putchar  // Undefine so the standard macros will not be used

#include <hardware/exception.h>
#include "multicore.h"
#include "pico/stdlib.h"

// SPI
//
// MuKOB uses 3 SPI devices; Display, Touch Panel, SD Card
// These are split across the two HW SPIs on the Pico so the display can be
// contolled at the same time the touch is read, or the SD card is read/written.
// This also allows the display to be clocked at a higher rate than the SD card
// can reliably be used with.
//
// Pins can be changed, see the GPIO function select table in the datasheet for
// information on GPIO assignments.
// Note: 'Pins' are the GPIO number, not the physical pins on the device.

// Using SPI 0 for the Touch and SD
#define SPI_TOUCH_DEVICE spi0     // Hardware SPI to use
#define SPI_TOUCH_MOSI  3         // DP-5
#define SPI_TOUCH_MISO 4          // DP-6
#define SPI_TOUCH_SCK  2          // DP-4

// Using SPI 1, and allocate it to the following GPIO pins
#define SPI_DISPLAY_DEVICE spi1 // Hardware SPI to use
#define SPI_DISPLAY_MOSI 11     // DP-15
#define SPI_DISPLAY_MISO 12     // DP-16
#define SPI_DISPLAY_SCK  10     // DP-14

// Chip select values/levels
#define SPI_CS_ENABLE  0        // LOW
#define SPI_CS_DISABLE 1        // HIGH

// Devices Chip select (and display CMD/Data)
#define SPI_CS_DISPLAY  9       // DP-12
#define SPI_DC_DISPLAY  8       // DP-11
#define SPI_CS_SDCARD   5       // DP-07
#define SPI_CS_TOUCH    6       // DP-09
//
#define IRQ_KEY     17      // DP-22
#define IRQ_rotary_TURN 14      // DP-19
#define IRQ_rotary_SW   13      // DP-17
#define IRQ_SPACEBAR_SW 28      // DP-34
#define IRQ_TOUCH       7       // DP-10

// PIO
// MuKOB uses PIO for reading the rotary encoder. This narrows the pins that can be used.
#define ROTARY_A_IN             14  // DP-19 - IRQ on same pin. 'B" must be the next GPIO (15)
#define ROTARY_B_IN             15  // DP-20 - Must be 1 greater than 'A' in.

// Other GPIO
#define DISPLAY_RESET_OUT       26  // DP-31
#define DISPLAY_BACKLIGHT_OUT   27  // DP-32
#define KEY_IN                  17  // DP-22 - IRQ on same pin.
#define SOUNDER_OUT             16  // DP-21
#define OPTIONS_3_IN            20  // DP-26 - Options DIP switch is 123 - 3 USB/BAUD OFF-OFF=115200 OFF-ON=19200
#define OPTIONS_2_IN            19  // DP-25 - Options DIP switch is 123 - 2 USB/BAUD  ON-OFF=9600    ON-ON=USB
#define OPTIONS_1_IN            18  // DP-24 - Options DIP switch is 123 - 1 ON = MKOB4 Interface
#define ROTARY_PB_SW_IN         13  // DP-17 - IRQ on same pin.
#define SPACEBAR_SW             28  // DP-34 - IRQ on same pin.
#define TONE_DRIVE              22  // DP-29 - Speaker drive

// Rotary switch push button state
#define ROTARY_PB_SW_PUSHED 0 // Switch is to GND
#define ROTARY_PB_SW_UNPUSHED 1

// Buzzer/Tone support
#define TONE_OFF 0
#define TONE_ON 1

// Display
// Hardware driven values (writes to GPIO)
#define DISPLAY_BACKLIGHT_OFF 0
#define DISPLAY_BACKLIGHT_ON 1
#define DISPLAY_HW_RESET_OFF 1
#define DISPLAY_HW_RESET_ON 0
#define DISPLAY_DC_DATA 1
#define DISPLAY_DC_CMD 0

// KOB support
#define KEY_CLOSED 0
#define KEY_OPEN 1
#define SOUNDER_DEENERGIZED 1
#define SOUNDER_ENERGIZED 0

// Options bit masks
typedef enum _option_mask_ {
    OPTION_BAUD_RATE  = 0x0C,  // 1100 < Mask for the baud rate select option
} option_mask_t;

/** @brief Macro to get the size of a structure member */
#define member_size(type, member) sizeof(((type *)0)->member)

// Some general purpose time constants
#define ONE_SECOND_MS 1000
#define FIVE_SECONDS_MS 5000
#define TEN_SECONDS_MS 10000
#define FIFTEEN_SECONDS_MS 15000
#define THIRTY_SECONDS_MS 30000
#define ONE_MINUTE_MS 60000
#define FIVE_MINUTES_MS 300000
#define TEN_MINUTES_MS 600000
#define ONE_HOUR_MS 3600000

#ifdef __cplusplus
}
#endif
#endif // _SYSTEM_DEFS_H_

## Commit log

2023-01-24 Updates to printing strings.
2023-01-24 Fix font (too many cols in 1 char). Add SP card library.
    [MuKOB.c]
2023-01-25 Add support for rotory encoder+switch.
2023-02-01 Reorganize source. Some board init working.
2023-02-20 Using 64k (16bit) color to improve performance. Split SPI so Display and Touch are separate.
2023-03-04 Initial KOB. Process Config.
    [mukob_sample.cfg]
2023-03-10 UI & BE on separate cores and CMT. UI on display.
    [mukob.sample.cfg, mukob.sys.sample.cfg]
2023-03-10 Remove leading '.' from names and update sample cfg
    [mukob.sample.cfg, mukob.sys.sample.cfg]
2023-03-19 Wire and Speed display. Build/debug on Windows.
2023-03-21 Handle 'Current Sender' info.
2023-03-30 Pin assignments.
2023-04-04 KOB key input functional.
    [mukob.sample.cfg]
2023-04-06 Configure/Cfg shell command display of config.
    [mukob.sample.cfg, mukob.sys.sample.cfg]
2023-04-20 Fix keep-alive timer from us to ms.
    [MuKOB.c]
2023-04-25 Station list (first cut).
    [mukob.sys.sample.cfg]
2023-04-26 Rotory encoder and switch IRQ handler. Temp connect-toggle on PBSW push.
2023-04-28 Components docs for the board. Debug flag functionality.
2023-05-01 Add 'debug' and other commands. Remove debug from option switches.
2023-05-10 Include interrupt status in '.ps' command output.
2023-05-13 Correct Term-UI when the station list adds lines.
    [ui.c]
2023-05-14 Hardware/PCB setup.
2023-05-25 Track GERBER files so they can be part of a project release.
2023-05-28 Main and KOB schematic pages.
    [MuKOB.kicad_pcb, MuKOB.kicad_sch, key_sounder.kicad_sch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]
2023-05-29 Schematic updates.
    [MuKOB.kicad_sch, key_sounder.kicad_sch, ui.kicad_sch]
2023-05-30 Update and organize display component docs.
    [MuKOB.kicad_sch, key_sounder.kicad_sch, ui.kicad_sch]
2023-05-31 HW - Display FFCs.
    [MuKOB.kicad_sch, ui.kicad_sch]
2023-06-02 Cfg version, name, are first 2 lines (no 'key=').
    [mukob.sample.cfg, mukob.sys.sample.cfg]
2023-06-02 Finish KOB page. UI FFC on.
    [MuKOB.kicad_sch, key_sounder.kicad_sch, ui.kicad_sch]
2023-06-02 Schematic ready for rules check.
    [MuKOB.kicad_sch, key_sounder.kicad_sch]
2023-06-02 Flip the display vertically so connector is at the bottom.
2023-06-02 Update README.md
    Update to talk more about the complete device.
2023-07-08 Change display backlight GPIO.
    [MK_UI.kicad_pcb, MK_UI.kicad_sch, MuKOB.kicad_sch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]
2023-10-10 Schematic prior to pulling KOB interface to separate board.
    [MuKOB.kicad_sch, audio.kicad_sch, key_sounder.kicad_sch]
2023-10-13 Audio on main page. KeySounder Intf on separate board. Switch matrix via Resistors.
    [MK_KS.kicad_pcb, MK_KS.kicad_sch, MK_UI.kicad_sch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]
2023-10-14 Reorganize onto 3 boards. Use 20pin UI connector.
    [MK_KS.kicad_sch, MK_UI.kicad_sch, MuKOB.kicad_sch]
2023-11-11 Electrical checks complete.
    [MK_KS.kicad_sch, MK_UI.kicad_sch, MuKOB.kicad_sch]
2023-11-18 KeySounder schematic ready for PCB layout.
    [MK_KS.kicad_sch]
2023-11-27 Schematic updates. Reorg components between boards. 20 pin ribbon.
    [MK_KS.kicad_sch, MK_UI.kicad_sch, MuKOB.kicad_sch]
2023-11-27 UI PCB initial
    [MK_KS.kicad_sch, MK_UI.kicad_pcb, MK_UI.kicad_sch]
2023-12-31 Device (Main) and K&S-IF ready for layout.
    [MK_KS.kicad_pcb, MK_KS.kicad_sch, MK_UI.kicad_pcb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]
2024-01-03 Main w/ UI - DRC close.
    [MuKOB.kicad_pcb, MuKOB.kicad_sch]
2024-01-04 Main PCB v1.0 complete.
    [MK_KS.kicad_pcb, MK_KS.kicad_sch, MuKOB.kicad_pcb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]
2024-01-06 Add 3D components for rendering.
    [MK_KS.kicad_pcb, MK_KS.kicad_sch, MuKOB.kicad_pcb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]
2024-01-16 PCBs received.
    [MK-CommAdapter.kicad_pcb, MK-CommAdapter.kicad_sch, MK-JackAdapter.kicad_pcb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]
2024-04-06 KSInf-MkIII: New JA: Add terminal block
    [MK-CommAdapter.kicad_pcb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]
2024-04-14 IF: MKIII. JA: Add terminal block.
    [MK-JackAdapter-B_Cu.gbr, MK-JackAdapter-B_Mask.gbr, MK-JackAdapter-B_Silkscreen.gbr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]
2024-04-29 MK-IF-MKIII and JackAdapter PCBs produced.
    [MK-KS-MkIII.kicad_pcb, MK-KS-MkIII.kicad_sch]
2024-07-08 Update manual. Add IF-MkIV.
    [IF-MkIV Costed BOM.xlsx, MK-KS-MkIII.kicad_pcb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]
2024-07-26 KS-MkIV: Pinout for bridge and mini-sounder update.
    [MK-KS-MkIV.kicad_pro.kicad_sch, MuKOB.kicad_pcb, MuKOB.kicad_sch]
2024-08-14 MK-IF-MkV BOM
    [MK-KS-MkV.kicad_pcb]
2024-08-14 bom clean up
2024-08-16 MK-IF-MkV: Working board.
    [MK-KS-MkV.kicad_pcb]
2024-08-23 Ref manual for MkV Interface.
    [MK-IF-MkV-Faceplate_2-0.dxf]
2024-11-03 MuKOB: rev b, update UI Switch res values to match Scores SW Board.
    [IF-MkV Costed BOM.xlsx, MuKOB.kicad_pcb, MuKOB.kicad_sch]
2025-10-02 Update costed BOM
    [IF-MkV Costed BOM.xlsx]

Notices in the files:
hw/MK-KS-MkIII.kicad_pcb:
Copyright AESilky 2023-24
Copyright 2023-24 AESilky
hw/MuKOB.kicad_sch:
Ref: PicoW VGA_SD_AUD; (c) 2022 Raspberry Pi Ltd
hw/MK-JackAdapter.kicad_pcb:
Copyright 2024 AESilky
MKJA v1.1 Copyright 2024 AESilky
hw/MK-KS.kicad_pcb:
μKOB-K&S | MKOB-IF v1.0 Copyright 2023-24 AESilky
